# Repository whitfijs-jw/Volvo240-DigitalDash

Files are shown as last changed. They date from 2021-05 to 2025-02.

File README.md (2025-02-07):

# DigitalDash

Volvo 240 Digital Dash Project.  Designed to use existing dash connectors (circular connectors w/ 2mm pins, vehicle speed sensor (VSS) connector, and various spade connectors) to
minimize extra wiring effort and installation of superfluous sensors.

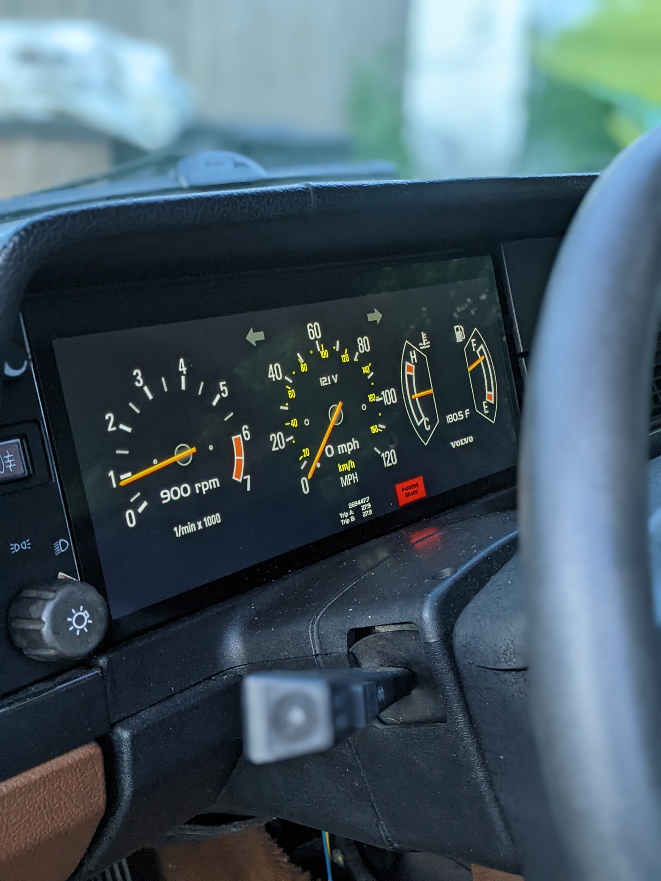
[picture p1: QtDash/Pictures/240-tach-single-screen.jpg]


## Features
### Plug and play with stock sensors and dash connectors
One of the main goals of the project was to use the existing Volvo 240 connectors. The only additional connectors and wiring needed are for sensors that weren't available on the stock main dash (oil pressure, oil temperature, vacuum/boost pressure, etc). Dash lights (low oil pressure, battery voltage, parking brake,high beams, etc) are functional as well as turn indicators. Fuel level and coolant temperature are functional.
The hardware supports the addition of common accessory sensors such as oil pressure, oil temperature, manifold absolute pressure, and ambient temperature.

### Multiple dash styles
Different Volvo dash styles can be displayed:
#### 240 w/ Tach
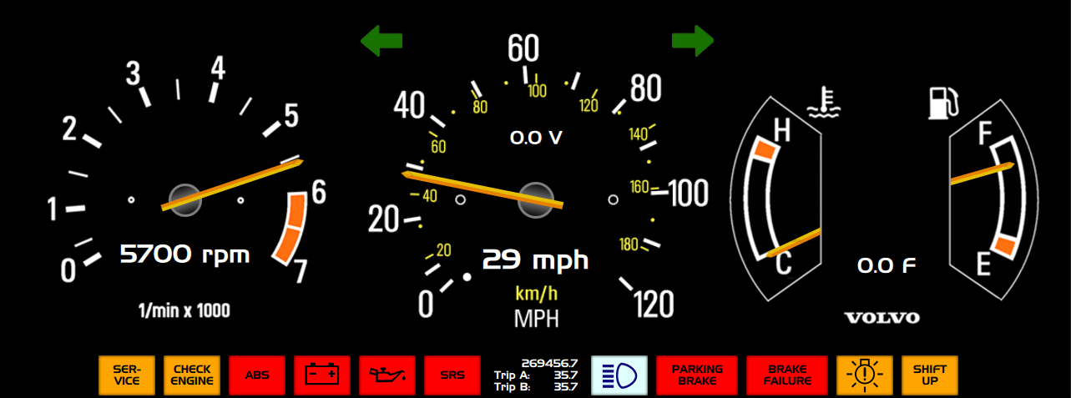
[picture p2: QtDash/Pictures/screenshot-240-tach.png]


#### 240 w/ Clock
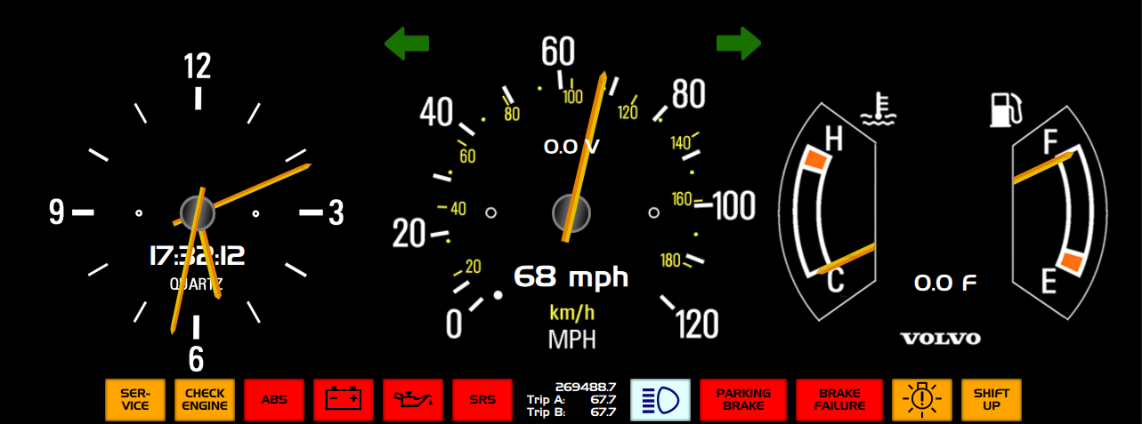
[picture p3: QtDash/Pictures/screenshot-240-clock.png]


#### R-Sport Style
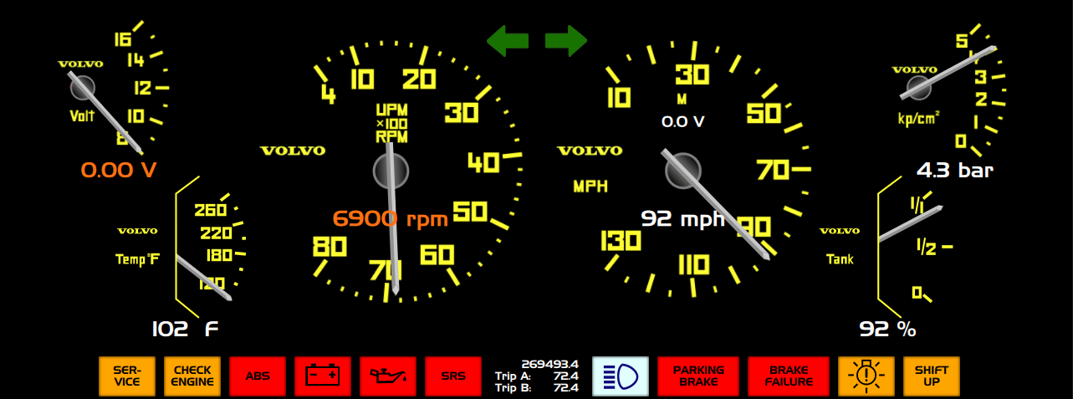
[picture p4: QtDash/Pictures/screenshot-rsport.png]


#### P1800 Style
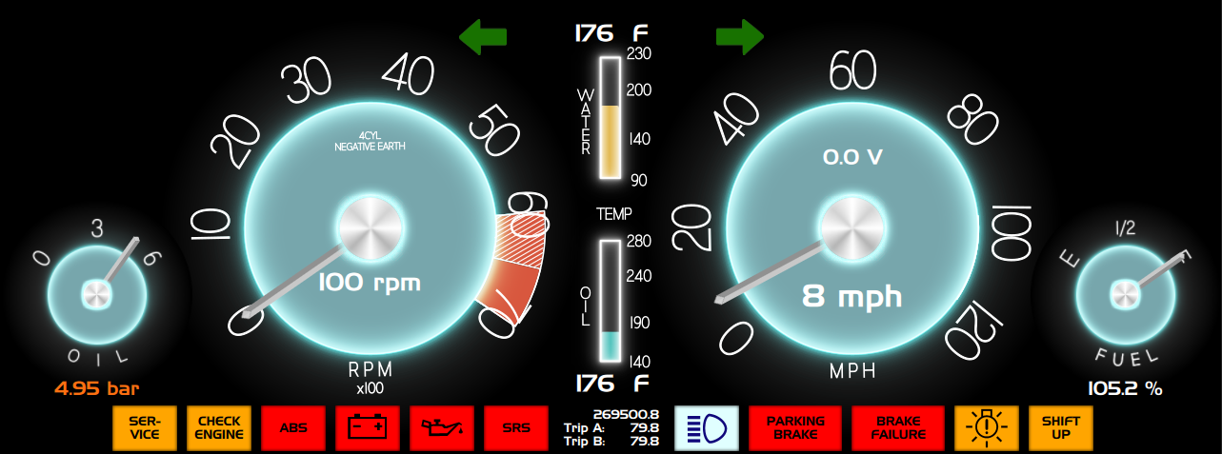
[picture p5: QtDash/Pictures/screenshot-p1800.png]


#### 850R
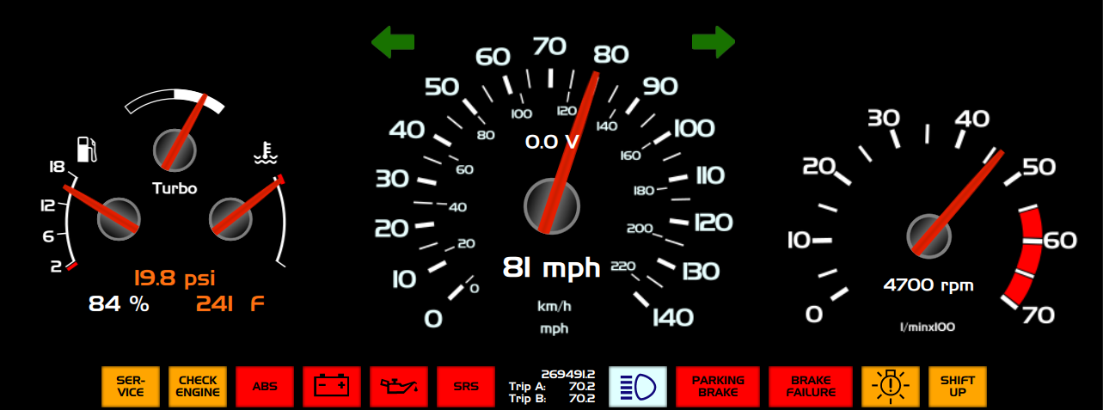
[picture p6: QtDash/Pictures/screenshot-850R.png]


#### 740/940 Style
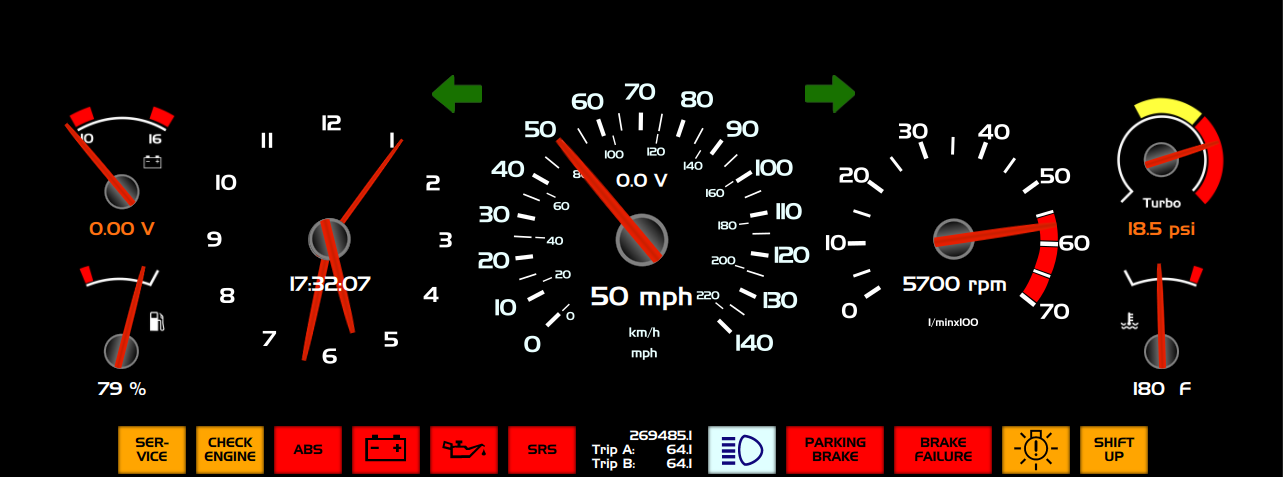
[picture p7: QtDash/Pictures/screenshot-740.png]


#### 544/140 Linear Style
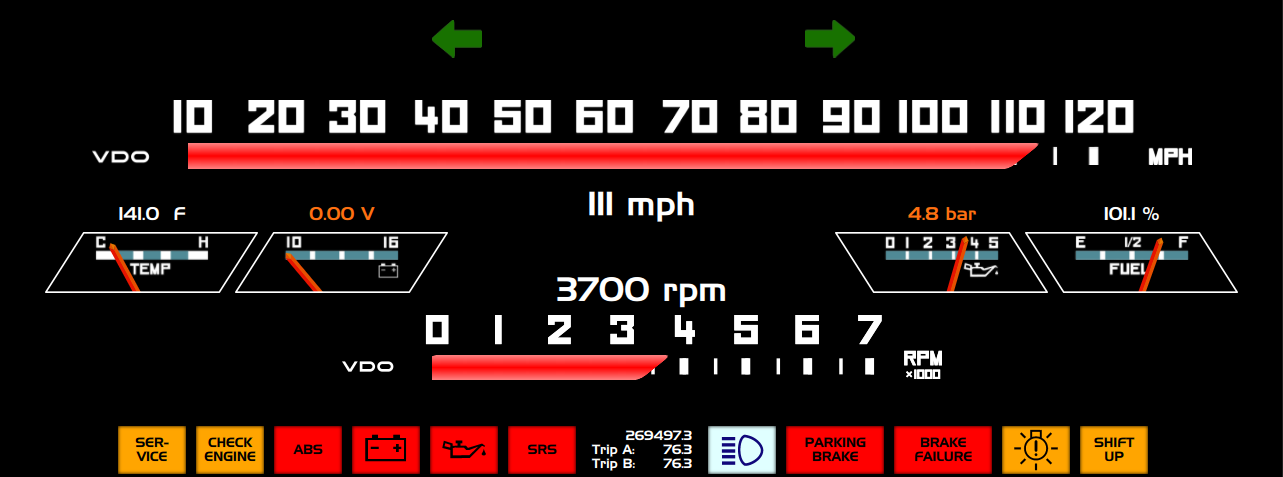
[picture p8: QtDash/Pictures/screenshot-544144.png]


#### Early 240 Style
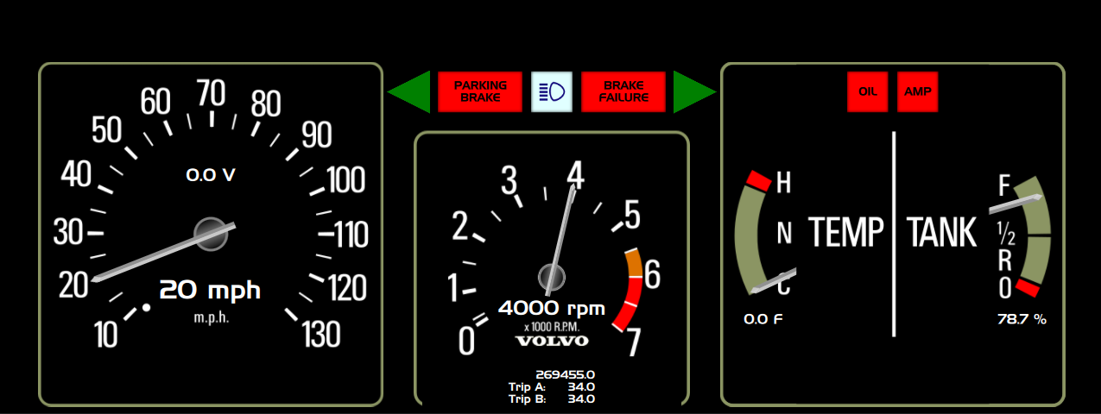
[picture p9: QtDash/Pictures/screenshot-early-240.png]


#### 140 Rallye Style
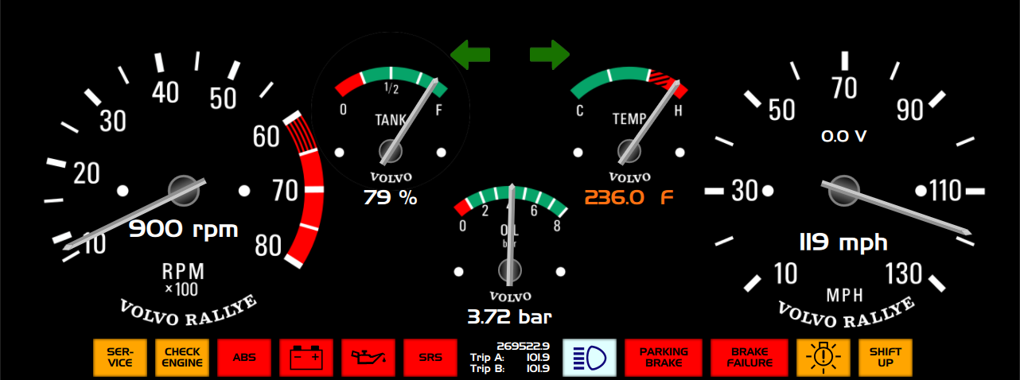
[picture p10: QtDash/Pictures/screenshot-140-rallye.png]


#### 240 Style Custom Layouts
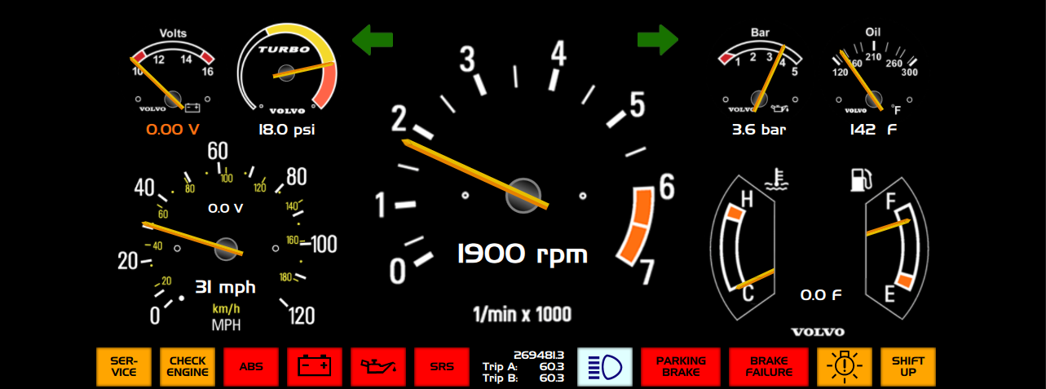
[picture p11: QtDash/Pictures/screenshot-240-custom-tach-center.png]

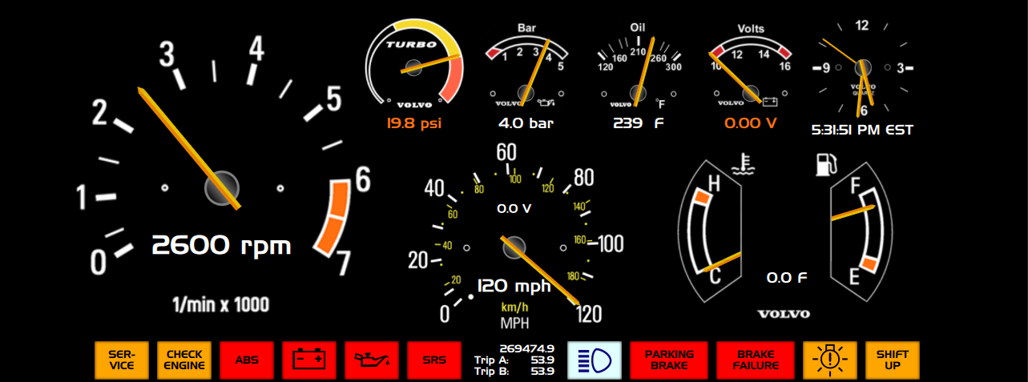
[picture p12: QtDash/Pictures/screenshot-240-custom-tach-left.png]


### Accessory Gauges
The raspberry pi 4 supports 2 HDMI outputs so a second screen can be added where normal 52mm accessory gauges would have been placed:

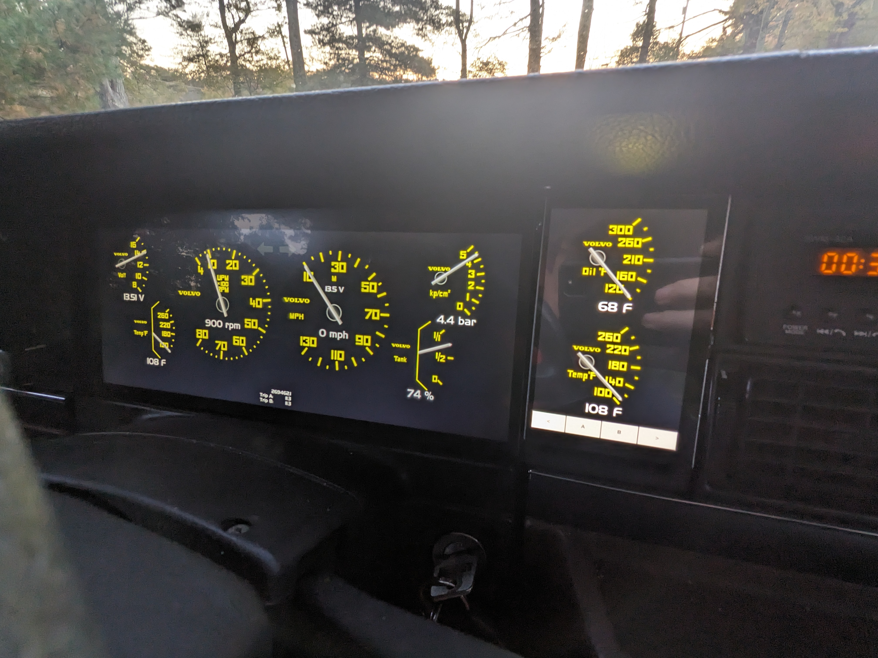
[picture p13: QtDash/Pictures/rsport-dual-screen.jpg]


Touch screen controls on this screen can be used to changed between dash layouts and also to reset trip odometers.  The style of the accessory gauges reflects the style of the main dash layout.

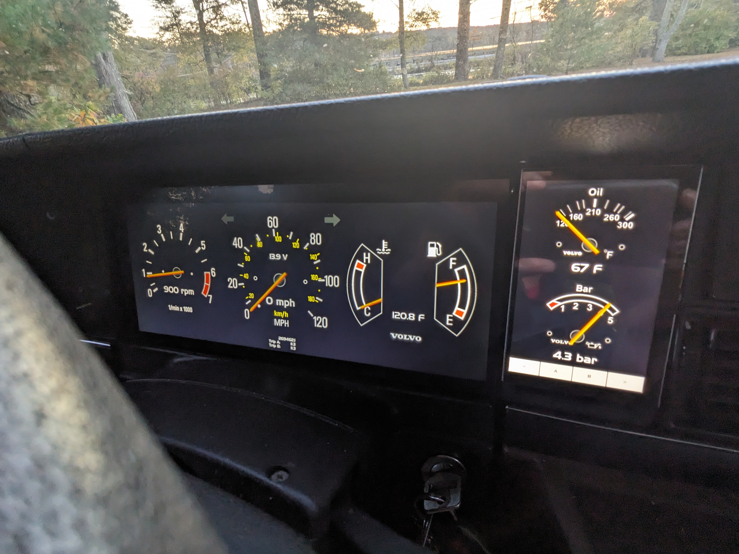
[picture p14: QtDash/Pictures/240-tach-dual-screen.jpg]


## Project Structure:
### /QtDash

This directory contains the hardware and software components that makeup the dash. There are also various visual/graphical assets that are used in the dash app.

#### /QtDash/VolvoDigitalDashModels

This directory contains the Qt app and related unit tests.  It is advised to use [QtCreator](https://www.qt.io/product/development-tools) to edit and compile the app. Using QtCreator to `QtDash/VolvoDigitalDashModels/subdirs.pro` will load both the app and the unit tests. The app is written using C/C++ for interfacing with the various sensors and QML for the UI.

#### /QtDash/Hardware

This directory contains the hardware that has been designed for this project.  Most of the PCBs have been designed using Eagle 7.7 as this is what I am most familiar with. The future of Eagle is questionable as an open source/free tool, so Kicad 6 will be used more and more as I become more familiar with it.

##### /QtDash/Hardware/DashHat

This directory contains the schematics and board files for the PCB that directly interfaces with the Raspberry Pi 40 pin header.  The board is split up into a low voltage (3.3/5V) that is powered from the Pi header and a high voltage (car battery voltage 8-16V) that is powered from the 240 ignition switch via the VSS connector.  The high voltage side is optically isolated from the low voltage side using optoislators.

##### /QtDash/Hardware/Cold Start Power Supply

This directory contains the schematics and board files for the cold start tolerant power supply design based around the LM3488. The input range is ~3V-24V and the output is ~5V rated at 3A.  During bench testing the input power needs to be above 5V when first powering up, and then could drop to ~3V while still continuously powering the Pi. This is a little overkill as the battery voltage during cranking only momentarily drops to 3V-4V before recovering very quickly to >10V.

##### /QtDash/Hardware/Screen Mounting

This directory contains the `.stl` files for mounting the HSD123KPW2-D10 12.3" TFT LCD using the stock 240 dash mounting holes.  These mounts will put the screen flush with the surrounding dash. The mounts and all other 3D modeling/CAD has been done using [Onshape](https://cad.onshape.com/documents/a41976d465f773bfdcbe5a50/w/2aee2fa256d8f08e0c531410/e/f563da56c6a88e94f86205e9). Included in the public OnShape document are models of the main PCB, HSD123KPW2-D10 LCD, screen mounts, etc.

##### /QtDash/Hardware/Simulation

This directory contains SPICE simulations of various circuits used in the dash. This is more of a scratchpad than it is a serious attempt at accurate real-life simulations.

##### /QtDash/Hardware/TachAdapter

This directory contains the schematics and board files for the tach signal adapter.  This board takes the high voltage pulses (>30V on my 88 245) and converts them to a square wave that can be used by the dash software to calculate RPM. The high voltage pulses are optically isolated from the dash/pi side to prevent any unwanted noise or damage to the pi or other hardware.

##### /QtDash/Hardware/VSS Adapter

This directory contains the schematics and board files for the VSS signal adapter. This board is based on the MAX9924 VR signal conditioning IC and takes the VR signal from the stock Volvo differential cover sensor and converts it into a square wave to be used by the dash software to calculated speed.

### /buildroot

This directory contains Buildroot, a tool used to generate a custom embedded Linux system that runs on the Pi. Buildroot allows us to generate a stripped down Linux system that has just enough to get the dash running.  This is the directory where you'll need to be to start linux image builds.

Below are relevant directories for this project within the buildroot directory structure:

#### /buildroot/board/volvodash

This directory contains the rootfs overlay for the dash as well as the custom scripts and configurations used whilst building the dash linux image. 

#### /buildroot/configs

This directory contains the configuration files for various boards. The relevant files for this project are `volvodash_defconfig` and `volvodash_rpi4_defconfig`.

#### /buildroot/output/images

This directory contains the outputs of the buildroot compilation process. After buildroot is done compiling the custom linux image, compiling the specified target packages, and constructing the target rootfs and bootfs, an image that can be flashed on to an SD card is placed here.  `sdcard.img` can then be flashed on to an SD card to be used on a pi.  As a part of the compilation/building the Qt Dash app should be compiled and placed within this image.  For more detailed information see *Setting Up Buildroot* below.

## Project components:
- Raspberry Pi 3 or Raspberry Pi 4/400
- 12.3" bar TFT LCD
- Qt Quick w/ EGLFS project to display renders of gauges
- Buildroot linux to cut down on footprint and boot time
- i2c/spi adc interface for reading temp, fuel, speed, etc sensors
- i2c IO expander for warning lights
- Raspberry Pi daughter board to read various sensors.
- DC/DC power supply for screen, pi and sensor supplies, if necessary
- Cheap USB GPS for speedometer and heading (leaving the original speedo behind the dash? Not planning on implementing a validated odometer)

## Current parts (mainly driven by availability):
- HSD123KPW2-D10 12.3" TFT 1920x720 LCD Display w/ HDMI conversion board and custom mounts
- MCP3208 for ADC inputs
- MCP23017SS for dash warning lights and left/right blinkers
- ILQ1 for isolated I/O inputs (3 for 12 inputs) add one more to completely fill the MCP23017
- IL300 for 12V to 3.3V for isolated analog signals (rheostat and battery voltage)
- lM358D for driving IL300 12V isolated analog inputs
- LMV324 & TVS912D for 5V to 3.3V analog sensor inputs
- VK-162 USB GPS module -- needs to be manually configured with u-blox u-center to get 10Hz update rate.
- (optional and separate) LM3488 switching power supply to maintain 5.1V out from 3V-24V input
- (optional) MAX9924 VSS conditioning circuit
- (separate) optocoupler tach pulse input.

## Accessory Screen Parts (optional)
- Adafruit TFP401 HDMI/DVI Decoder to 40-Pin TTL Breakout - With Touch
- BuyDisplay.com 5" IPS 800x480 LCD Screen TFT w/ touch module ER-TFT050-6-5781-4859
- extended 40-pin flat cable
- USB cable for touch screen interface

## Setting up buildroot

Buildroot will build the custom linux image.  The image being build is based on the raspberry-piX 32-bit images provided from the buildroot project.  Right now there is only support for raspberry pi 3 and pi 4/400.  Things are still a bit of a mess here and depending on your flavor of Linux you might have to setup your system a little differently than others.  You can find a lot of good information here on host packages that are absolutely necessary: [Buildroot System Requirements](https://buildroot.org/downloads/manual/manual.html#requirement)

Detailed instructions for setting up a virtual machine and the build environment are found [here](SetupBuildEnv.md)

## Remote Access

1. SSH (ethernet)

After boot the pi will be configured with a static ip address of 192.168.42.2.
Assuming you're running a version of linux that has network-manager you can run some variation of the following after connecting the pi to your computer with an ethernet cable:

`nmcli con add con-name dash-target type ethernet ifname <your-ethernet-interface> ip4 192.168.42.1/24`

`nmcli con up id dash-target`

You can find your ethernet interface by running:

`ip addr show`

You're looking for something like `enp2s0` or `eth0` depending on your flavor of linux.

After setting everything up you can test the connection using:

`ping 192.168.42.2` 

on the host machine and then run:

`ssh root@192.168.42.2` 

and enter the default credentials

## Dash Configuration

After linux is done booting and loading kernel modules, the init system will automatically start the Qt app stored in the /opt directory.  When the app is initializing it will load two configuration files from the /opt directory:

- config.ini
- config_gauges.ini
- config_odo.ini
- config_can.ini

These files are parsed using QSettings ([more info here](https://doc.qt.io/qt-5/qsettings.html)).

### Sensor input configuration (config.ini)

The sensor configuration file contains the configuration for the analog sensor inputs, dash light inputs, user inputs, tach inputs, vss inputs, the isolated 12V inputs, and backlight PWM control.

#### Sensor channels

Under the **[sensor_channel]** section the following inputs can be configured:

| Parameter | Description |
|---|---|
| *coolant_temp* | Stock Volvo coolant temperature sensor/sender. |
| *fuel_level* | Stock Volvo Fuel Level sender |
| *oil_pressure* | Oil Pressure sender |
| *oil_temp* | Oil temperature sender |
| *map_sensor* | MAP sensor sensor (GM 0-5V) |
| *ambient_temp* | Ambient Temperature sender (any NTC sensor can be used) |
| *dimmer_voltage* | Dimmer Rheostat output voltage |
| *fuse8_12v* | Volvo Fuse 8 to measure battery voltage |
| *reference* | A channel configured to measure the unregulated pi 5V supply to decrease measurment error.  If this is not used it is assumed that the supply is exactly 5V. You can alternatively measure your 5V power rail and provide that in the configurations below.|
| *v_supply* | Optional value to set the exact value of the 5V supply.  If left empty exactly 5.0V will be used |

The default configuration is as follows:
```
[sensor_channels]
coolant_temp=0
fuel_level=1
oil_pressure=2
oil_temp=3
map_sensor=5
ambient_temp=4
dimmer_voltage=6
fuse8_12v=7
reference=-1
v_supply=5.1
```

#### Dash Light Inputs

Under the **[dash_lights]** section the following inputs can be configured:

| Parameter | Description |
|---|---|
| *oil_pressure_sw* | Stock oil pressure switch |
| *od_lamp* | Overdrive lamp |
| *high_beam* | High beam indication |
| *brake_failure* | brake failure indication |
| *bulb_failure* | bulb failure indication |
| *charging* | Alternator D+/Battery charge failure indication |
| *blinker_left* | Left blinker indication |
| *blinker_right* | Right blinker indication |
| *od_lamp_auto* | auto trans OD lamp |
| *check_engine* | Check Engine indication |
| *parking_brake* | Parking Brake engagement indication |
| *conn_32_pin3* | Half moon connector pin 3 (ABS light in newer 240s) |

and one additional option:

- *active_low* -- Optoisolator outputs are open collector so this should be set to 1 unless changes to the hardware have been made

The default configuration is as follows:

```
[dash_lights]
active_low=1
oil_pressure_sw=0
od_lamp=1
high_beam=2
brake_failure=3
bulb_failure=7
charging=6
blinker_left=5
blinker_right=4
od_lamp_auto=8
check_engine=9
parking_brake=10
conn_32_pin3=11
```
#### User Input configuration

There are 4 user inputs in Rev C and greater hardware.  They are active low inputs on the otherwise unused pins on the MCP23017.

Under the **[user_inputs]** section the following inputs can be configured:

| Parameter | Description |
|---|---|
| *input_1* | User input 1 pin number |
| *input_2* | User input 2 pin number |
| *input_3* | User input 3 pin number |
| *input_4* | User input 4 pin number |
| *input_1_map* | User input 1 key mapping |
| *input_2_map* | User input 2 key mapping |
| *input_3_map* | User input 3 key mapping |
| *input_4_map* | User input 4 key mapping |

The default configuration is as follows:

```
[user_inputs]
input_1=12
input_2=13
input_3=14
input_4=15
input_1_map="Key_Left"
input_2_map="Key_A"
input_3_map="Key_B"
input_4_map="Key_Right"
```

Available key mappings are:
```
"Key_Left"
"Key_Right"
"Key_Up"
"Key_Down"
"Key_A"
"Key_B"
"Key_C"
"Key_D"
"Key_1"
"Key_2"
"Key_3"
"Key_4"
```

"Key_Left" and "Key_Right" are used to change dash layouts.  Other keys will be mapped to other functions in the future (resetting trip counters, for example).

#### MAP Sensor configuration

Designed for a GM style 0-5V output MAP sensor (1 bar, 2 bar, 3 bar). Under the **[map_sensor]** section the following parameters can be configured:

| Parameter | Description |
|---|---|
| *p_0v* | pressure when sensor output is 0V |
| *p_5v* | pressure when sensor output is 5V |
| *p_atm* | atmospheric pressure |
| *units* | pressure units used for above values.  "kPa", "psi" or "bar" should be used |

The default configuration is for a 3 bar GM style map sensor:

```
[map_sensor]
p_0v=3.6
p_5v=315
units="kPa"
```

#### Temperature Sensor (NTC) Configuration

An array of NTC sensor configurations. Calibration curves are calculated using the [Steinhart-Hart equation](https://en.wikipedia.org/wiki/Steinhart%E2%80%93Hart_equation). Under the **[temp_sensor]** the following parameters can be configured:

| Parameter | Description |
|---|---|
| *type* | Sensor type.  Options are "coolant", "oil", and "ambient" |
| *r_balance* | Resistance of the balance resistor. This can be calculated based on the high and low resistances expected during operation. |
| *t1_temp* 	|  Temperature at first calibration point |
| *t1_R* 		| Resistance at first calibration point |
| *t2_temp* 	| Temperature at second calibration point |
| *t2_R* 		| Resistance at second calibration point |
| *t3_temp* 	| Temperature at third calibration point |
| *t3_R* 		| Resistance at third valibration point |
| units | Temperature units used.  Options are "C", "K", "F" |

The default configuration is designed for an early type stock 240 coolant temp sensor, a VDO 325-905 Oil temperature sender, and a random ambient temp sensor for a BMW off Amazon.

```
[temp_sensor]
size=3
[temp_sensor/1]
type="coolant"
r_balance=470
t1_temp=60
t1_R=217
t2_temp=90
t2_R=87
t3_temp=100
t3_R=67
units="C"
[temp_sensor/2]
type="oil"
r_balance=150.0
t1_temp=19.5
t1_R=1325
t2_temp=100
t2_R=78.5
t3_temp=157
t3_R=40.5
units="C"
[temp_sensor/3]
type="ambient"
r_balance=6490
t1_temp=1.0
t1_R=15800
t2_temp=20
t2_R=6400
t3_temp=36
t3_R=3360
units="C"
```

#### Resistive Sensor Configuration

An array of resistive sensor configurations. Calibration values can be interpolated (not advised unless a lot of data points are available) or can be fitted with a polynomial of an arbitray order.  Usually a 2nd order polynomial is good enough.  The following parameters can be configured:

| Parameter | Description |
|---|---|
| *type* | Sensor type.  Options are "coolant", "oil", and "ambient" |
| *fit* | Type of fit. Options are "interpolate" or "polynomial, N" with N as the polynomial order.
| *r_balance* | Resistance of the balance resistor. This can be calculated based on the high and low resistances expected during operation. |
| *r* | Calibration resistance values.|
| *y* | Calibration y values |
| *units* | Units of calibration y values |
| *lag* | Lag factor (0-1).  Used to filter values with the difference equation: **y[n] = lag \* x[n] + (1 - lag) \* y[n-1]** Default value is 1.0. |
|*lag_decay*| Lag decay factor.  If set to a non-zero value the following equation will dictate the lag factor value used above: **lagStart=1-*lag*, lag[n] = lagStart \* (1 - *lag_decay*)^(n)** and saturates at the value set by *lag*. Large values will decay quickly, small values slowly.  Default value is 0.0.  |

The default configuration is designed for a VDO 360-028 Oil pressure sender and a 240-33Ohm Volvo 240 Fuel level sender.

```
[resistive_sensor]
size=2
[resistive_sensor/1]
type="oil_pressure"
fit=polynomial,2
r_balance=43.0
r=10.0,48.0,82.0,116.0,184.0
y=0.0,1.0,2.0,3.0,5.0
units="bar"
lag=1.0
[resistive_sensor/2]
type="fuel_level"
fit=polynomial,3
r_balance=91.0
r=240,196,153,125,103,87,67,45,33
y=0.0,12.5,25.0,37.5,50.0,62.5,75.0,87.5,100
units="%"
lag=0.2
```

#### Analog 12V inputs.

To measure signals that are inherently tied to battery voltage there are 2 linearized opto-isolated inputs.  The following parameters can be configured:

| Parameter | Description |
|---|---|
| *name* | Sensor name.  "voltmeter" is the only one currently used |
| *opto_r1* | Isolated side (R59 in schematic below) |
| *opto_r2* | Opto-isolator gain resistor R2 (R62 in schematic below) |
| *input_r1* | High side resistor of voltage divider for input into opto-isolator. (R71 in schematic below) |
| *input_r2* | Low side resistor of voltage divivider for input into opto-isolator. (R72 in schematic below) |
| *k3* | Opto-isolator K3 gain (defined by linearized opto-isolator used and will have to be measured) |
| *offset* | Offset to voltage calculation, the linearized opto-isolator usually has an offset that will need to be accounted for. |
| *x* | Linearized opto-isolator input voltage calibration measurements.  This is the high voltage side.  The more measurement points the better. |
| *y* | Output voltage calibration measurements.  This is the low voltage side.  Ideally if there was zero offset and a K3 gain of 1.0 these should be x / 10.  This is unlikely to be the case given the binning of the IL300 and LOC11x series. |

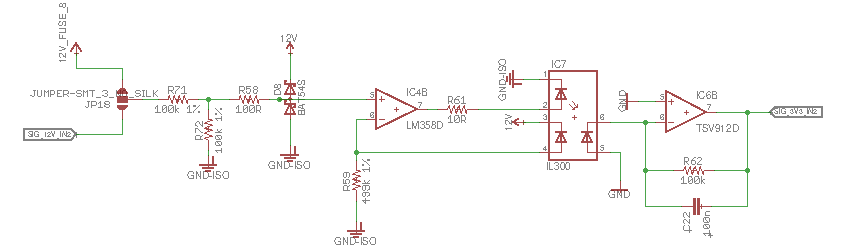
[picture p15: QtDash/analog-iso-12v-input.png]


##### How to determine K3 value (still need to test on car -- likely to change)
1. In the config.ini file, set *opto_r1*, *opto_r2*, *input_r1*, *input_r2*, and *k3* to 1.0.
2. In the config.ini file, set *offset* to 0.0.
3. Reboot the dash.
4. The output for the voltmeters will now be the real input to the ADC. Usually between 1V-2V for inputs from 8V to 16V.
5. With the car on but not running, measure the voltage at fuse 8.  This will be your first x value.  Take the output of the voltmeter (somewhere between 1V-2V).  This will be your first y value.
6. Start the car and repeat the above step.  These will be your second x and y values.
7. Enter the values determined above in the config.ini file.
8. Reset the *opto_r1*, *opto_r2*, *input_r1*, *input_r2* to their previous values.  You can leave *offset* and *k3* alone.  The software will use your calibration values to calculate the k3 gain and offset.
9. Reboot the dash and verify that the voltages with the car on and running match what you had measured before.

*Note on K3 gain calibration values:*
*Ideally, you would want way more than just 2 points to calibrate with.  If you have access to an adjustable power supply it is recommended to take 5+ measurements from 8V-16V.*

The default configuration is as follows:

```
[12v_analog]
size=2
[12v_analog/1]
name="voltmeter"
opto_r1=490000.0
opto_r2=100000.0
input_r1=100000.0
input_r2=100000.0
k3=1.1536
offset=.087985
x=8.25, 9.05, 9.87, 10.67, 11.52, 12.37, 13.30, 14.15, 14.96, 15.78, 16.78
y=1.05, 1.15, 1.25, 1.35, 1.45, 1.55, 1.65, 1.76, 1.85, 1.95, 2.05
[12v_analog/2]
name="rheostat"
opto_r1=490000.0
opto_r2=100000.0
input_r1=100000.0
input_r2=100000.0
k3=1.1536
offset=.087985
x=8.25, 9.05, 9.87, 10.67, 11.52, 12.37, 13.30, 14.15, 14.96, 15.78, 16.78
y=1.05, 1.15, 1.25, 1.35, 1.45, 1.55, 1.65, 1.76, 1.85, 1.95, 2.05
```

#### Tach Input Configuration

RPM is estimated by measuring the time difference between pulses from the negative terminal of the ignition coil.  The following parameters can be configured:

| Parameter | Description |
|---|---|
| *pulse_per_rot* | Number of tach pulses per rotation (number of cylinders / 2) |
| *max_rpm* | Maximum RPM to resolve.  This should be as low as possible. |
| *avg_num_samples* | Number of samples to average over to estimate RPM |

The default configuration is as follows:

```
[tach_input]
pulse_per_rot=2
max_rpm=9000
avg_num_samples=4
```

#### Vehicle speed sensor input

Designed to used the stock 240 diff cover VSS. The vehicle speed can be estimated using the number of pulses coming from the VSS sensor for every rotation of the rear diff. The following parameters can be configured:

| Parameter | Description |
|---|---|
| *pulse_per_rot* | Number of VSS pulses per rotation (12 for non-ABS and 48 for ABS equipped 240s) |
| *tire_diameter* | Tire diameter (can be used to calculate pulses per unit distance) |
| *diameter_units* | Tire diameter units: "inch", "centimeter", "millimeter", "foot", etc  |
| *pulse_per_unit_distance* | Number of pulses per units distance. |
| *distance_units* | Distance units for pulses per unit distance:  "mile", "kilometer  |
| *max_speed* | max speed (distance_units / hour).  Keep as low as possible to avoid picking up noise as VSS pulses |

The default configuration is as follows:

```
[vss_input]
pulse_per_rot=12
tire_diameter=24.9
diameter_units="inch"
pulse_per_unit_distance=9720
distance_units="mile"
max_speed="185"
```

#### Backlight control configuration (optional and only somewhat functional)

The stock 240 dimming circuit (Pin 10 on the circular Volvo connector 31) can be used to dim the backlight of the LCD by injecting a PWM signal into the LCD control board. Back light control with the dimmer knob only works when the headlights or running lights are engaged.  Otherwise, the dimmer rheostat does not receive voltage.

The following parameters can be configured:

| Parameter | Description |
|---|---|
| *max_duty_cycle* | Maximimum duty cycle of backlight PWM signal (min_duty_cycle-1.0) |
| *min_duty_cycle* | Minimum duty cycle of backlight PWM signal (0-max_duty_cycle) |
| *lights_off_duty_cycle* | Default duty cycle to use when the headlights or running lights are off |
| *lights_on_duty_cycle* | Default duty cycle to use when headlights or running lights are on|
| *min_dimmer_ratio* | rheostat voltage as a percentage of battery voltage at dimmest setting |
| *max_dimmer_ratio* | rheostat voltage as a percentage of battery voltage at brightest setting |
| *use_dimmer* | flag to use/don't use dimmer |
| *active_low* | PWM signal active low flag |

The default configuration is as follows:

```
[backlight]
max_duty_cycle=1.0
min_duty_cycle=0.05
lights_off_duty_cycle=1.0
lights_on_duty_cycle=0.5
min_dimmer_ratio=0.82
max_dimmer_ratio=0.93
use_dimmer=0
active_low=1
```

### Gauge Configs (config_gauges.ini)
There are a few options in setting up the gauge units and high/low warning indications.  There settings are found within the file config_gauges.ini.  The app will parse this file and will set the various gauge units, min/max values, and high/low warnings.

#### Gauge Config Parameters
| Parameter | Description | Default Value |
|---|---|
|*units*| Gauge Display Units ||
|*low_alarm*| Value below which gauge will indicate a warning ||
|*high_alarm*| Value above which gauge will indicate a warning ||
|*alt_units_enable*| Enable alternate units|*false*|
|*alt_units*|Alternate units|\"\"|
|*alt_units_thres*|Threshold value to switch units|*0.0*|
|*alt_units_above*|If true, use alternate units above threshold.  Otherwise the alternate units are used below the threshold|*false*|

##### Example:
This example sets the units for coolant temperature gauges, in all screens, to celsius.  The gauge will indicate an alarm when the temperature exceeds 100C.
```
[coolant_temp]
units="C"
low_alarm=0.0
high_alarm=100.0
```

#### Available Gauge Units
Below are the available units for each gauge type

| Gauge Type | Available Units |
|---|---|
|**[boost]**|```"bar"``` ```"psi"``` ```"inHg"```|
|**[coolant_temp]**|```"C"``` ```"F"```|
|**[fuel_level]**|```"%"```|
|**[oil_pressure]**|```"bar"``` ```"psi"```|
|**[oil_temperature]**|```"C"``` ```"F"```|
|**[voltmeter]**|```"V"```|
|**[speedo]**|```"mph"``` ```"kph"``` ```"km/h"```|
|**[tacho]**|*none*|

#### Default Gauge Ranges

These are the default gauge ranges for the given units.  These can be assigned to different values in *config_gauges.ini*, but the gauges themselves are prerendered so its not gauranteed that the needle position will align with the displayed value

| Gauge Type | Unit | Min Value | Max Value |
|---|---|---|---|
|**[boost]**| ```"psi"``` | -20 | 30 |
|**[boost]**| ```"bar"```| -1.0| 1.5 |
|**[coolant_temp]**| ```"C"``` | 50 | 120 |
|**[coolant_temp]**| ```"F"```| 120| 250 |
|**[fuel_level]**| ```"%"``` | 0 | 100 |
|**[oil_pressure]**| ```"bar"```| 0| 5 |
|**[oil_pressure]**| ```"psi"``` | 0 | 80 |
|**[oil_temperature]**| ```"C"```| 50| 150 |
|**[oil_temperature]**| ```"F"``` | 120 | 300 |
|**[voltmeter]**| ```"V"```| 10| 16 |
|**[speedo]**| ```"kph"``` ```"km/h"``` | 0 | 220 |
|**[speedo]**| ```"mph"```| 0| 120 |

### Default Values

```
[boost]
units="psi"
low_alarm=-20.0
high_alarm=20.0
[coolant_temp]
units="F"
low_alarm=0.0
high_alarm=200.0
[fuel_level]
units="%"
low_alarm=10.0
high_alarm=200.0
[oil_pressure]
units="bar"
low_alarm=1.0
high_alarm=4.5
[oil_temperature]
units="F"
low_alarm=0.0
high_alarm=220.0
[voltmeter]
units="V"
low_alarm=12.0
high_alarm=15.0
[speedo]
units="mph"
top_value_source="voltmeter"
top_value_units="V"
[tacho]
max_rpm=7000
redline=6000
```

### CAN config (config_can.ini)
Rev C hardware added components to interface with CAN outputs from an aftermarket ECU.  The MCP2515 driver and can0 network interface are loaded when the dash boots and the Dash Qt app attempts to load CAN frame configuration from the *config_can.ini* file.  To date this has only been tested with a Microsquirt on a bench with simulated inputs. If the CAN interface is enabled in the CAN config file, the dash will preferentially use the frame data for a specific gauge over a hardware sensor.

#### Enable/Disable
Under the **[start]** heading in the CAN config file, there is a single option:

| Parameter | Description |
|---|---|
| *use* | true/false to enable/disable the use of incoming CAN data |

#### CAN Frame data
Under the **[can_frame]** heading will come the CAN frame data settings. This is setup based upon information found [here](http://www.msextra.com/doc/pdf/Megasquirt_CAN_Broadcast.pdf).

| Parameter | Description |
|---|---|
| *frame_id* | CAN Frame ID where data is present |
| *offset* | Offset within frame where the data is present |
| *data_size* | Data size in bytes |
| *signed* | true if data is signed |
| *name* | Name of data (map, rpm, tps, etc) -- default values come from the simplified CAN broadcast data from Megasquirt |
| *units* | Units of data |
| *multiply* | Factor to multiply raw value by |
| *divide* | Factor to divide raw value by |
| *add* | Value to add to raw value |
| *gauge* | Gauge to route data to. |

Order of operations is **(raw_data * multiply_factor / divide_factor) + add_value**.  Is this right? No idea.

Example configuration:
```
[start]
use=false
[can_frame]
size=7
[can_frame/1]
frame_id=1512
offset=0
data_size=2
signed=true
name="map"
units="kPa"
multiply=1
divide=10
add=0
gauge="boost"
[can_frame/2]
frame_id=1512
offset=2
data_size=2
signed=false
name="rpm"
units="rpm"
multiply=1
divide=1
add=0
gauge="tacho"
[can_frame/3]
frame_id=1512
offset=4
data_size=2
signed=true
name="clt"
units="F"
multiply=1
divide=10
add=0
gauge="coolant_temp"
[can_frame/4]
frame_id=1512
offset=6
data_size=2
signed=true
name="tps"
units="%"
multiply=1
divide=10
add=0
gauge="none"
[can_frame/5]
frame_id=1513
offset=4
data_size=2
signed=true
name="mat"
units="F"
multiply=1
divide=10
add=0
gauge="none"
[can_frame/6]
frame_id=1515
offset=0
data_size=2
signed=true
name="batt"
units="V"
multiply=1
divide=10
add=0
gauge="voltmeter"
[can_frame/7]
frame_id=1516
offset=0
data_size=2
signed=true
name="vss1"
units="msec^-1"
multiply=1
divide=10
add=0
gauge="none"
```

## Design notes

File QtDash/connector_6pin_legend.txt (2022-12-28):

oil pressure -> yellow
oil temp -> orange
ambient -> N/C
map_sensor -> blue

6 pin DT04-6P
1 -> +5V (red)
2 -> MAP Sensor output (blue)
3 -> GND (black)
4 -> N/C (ambient temp sensor)
5 -> oil temp (orange)
6 -> oil pressure (yellow)

Molex Nano-fit 8-pin
1 -> oil temp (orange)
2 -> oil pressure (yellow)
3 -> sensor 2 input (used by stock fuel level sensor)
4 -> sensor 1 input (used by stock coolant temp sensor)
5 -> N/C (ambient temp sensor)
6 -> MAP (blue)
7 -> +5V (red)
8 -> GND (black)

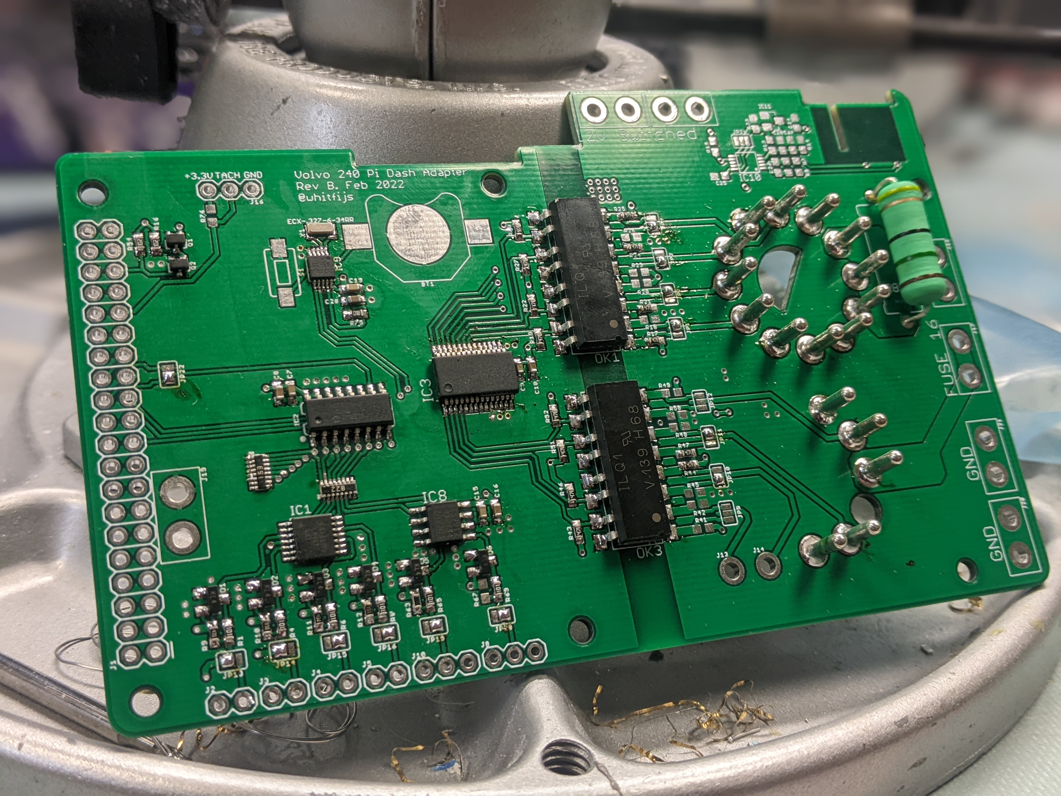
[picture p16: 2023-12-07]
QtDash/Pictures/revb_hardware.jpg

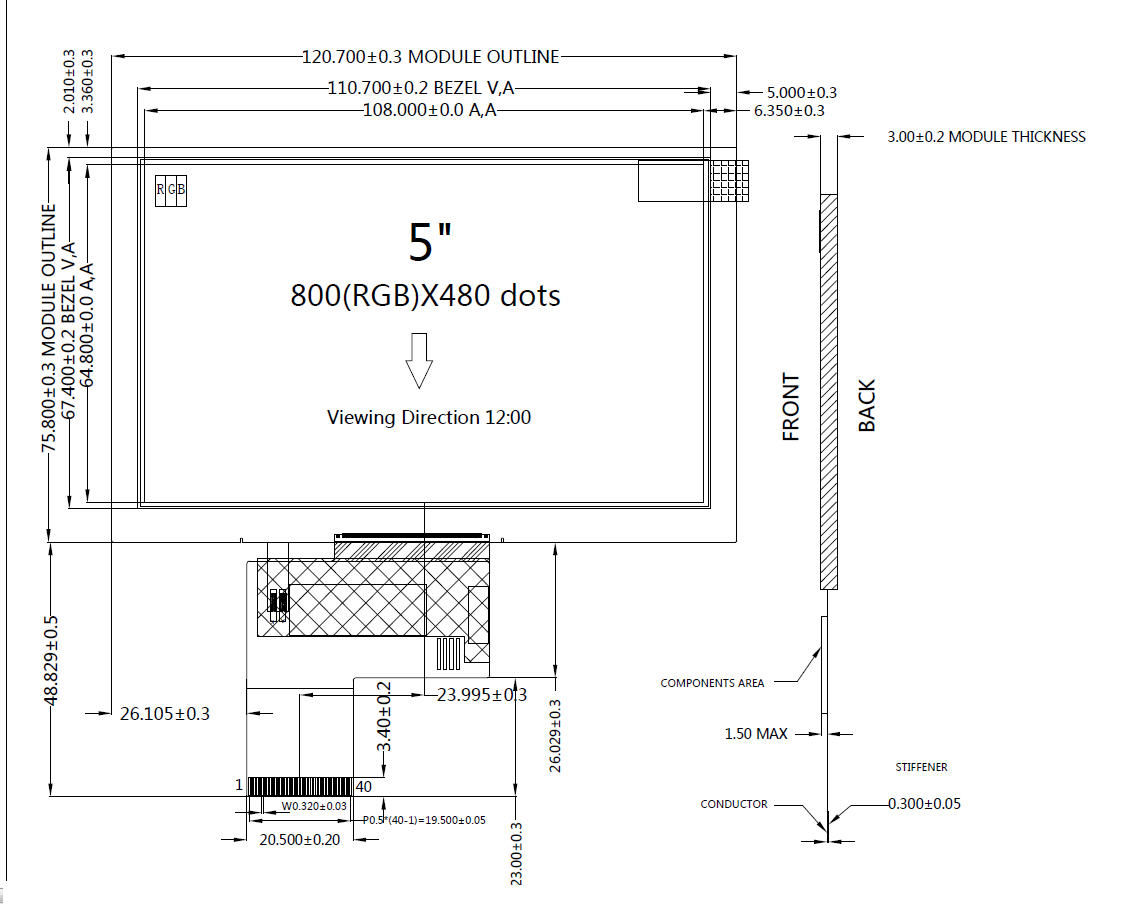
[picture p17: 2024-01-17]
QtDash/Hardware/Datasheets/Accessory Screen/er-tft050-3_outline_drawing_5.jpg

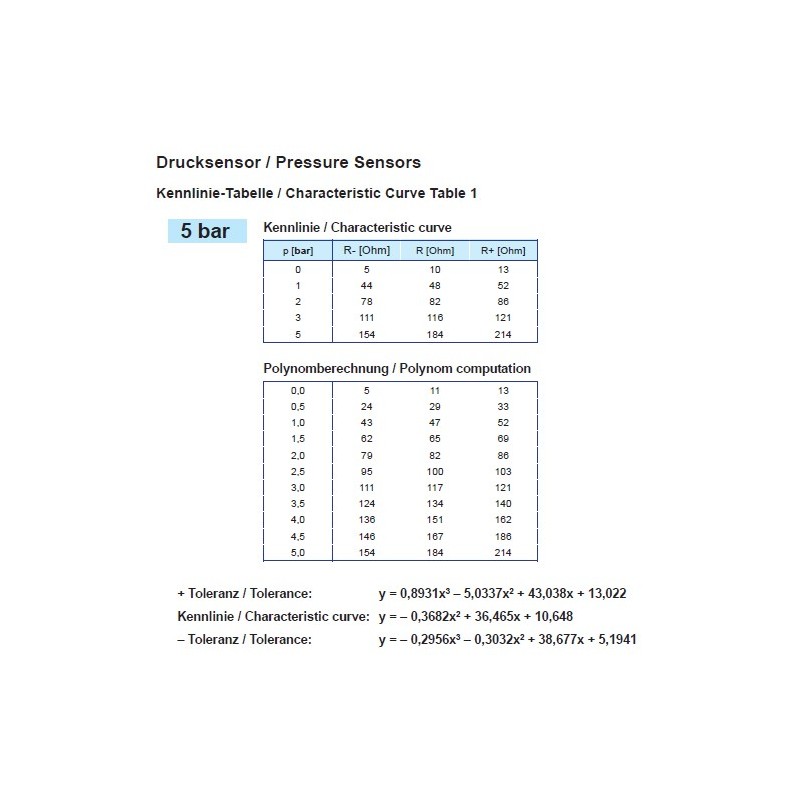
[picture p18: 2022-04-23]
QtDash/Hardware/Datasheets/Sensor Info/vdo-pressure-sender-0-5-bar-1-8-27-nptf.jpg

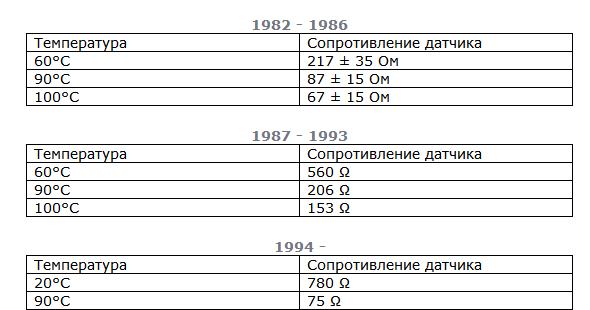
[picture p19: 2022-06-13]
QtDash/Hardware/Datasheets/Sensor Info/sensor.JPG

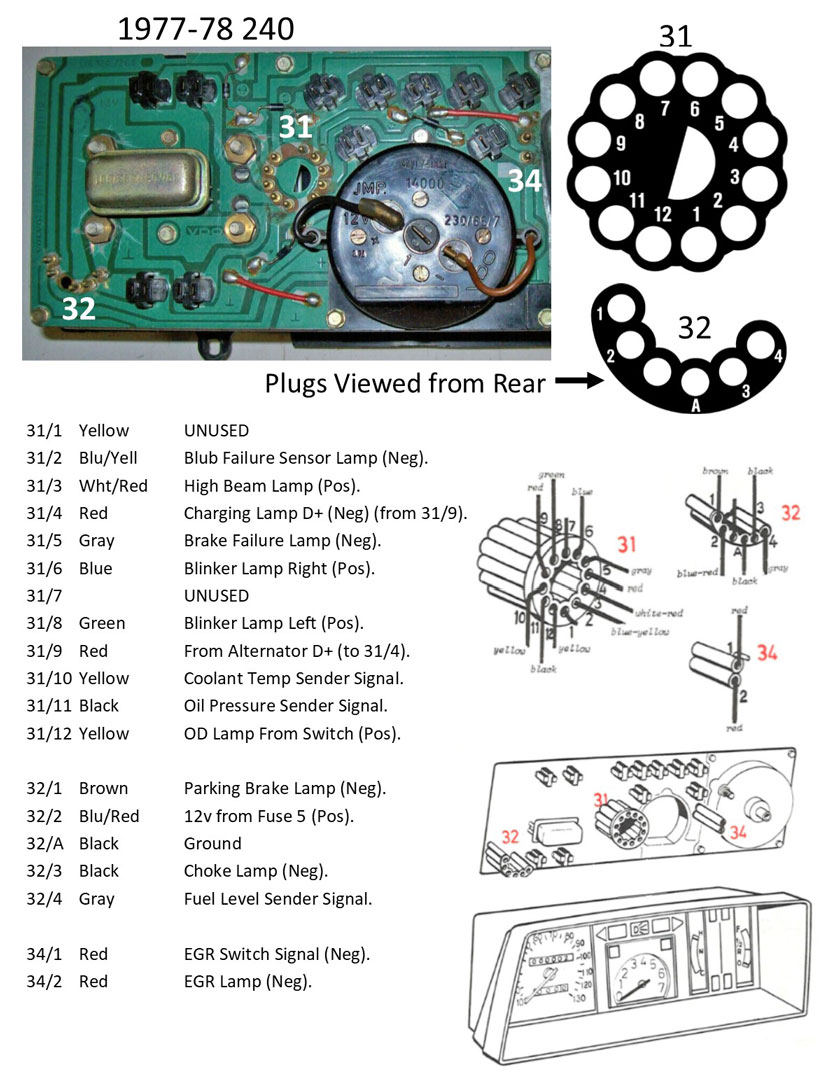
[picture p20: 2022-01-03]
QtDash/Hardware/Dash Pinouts/240instruments1977-78-01med.jpg

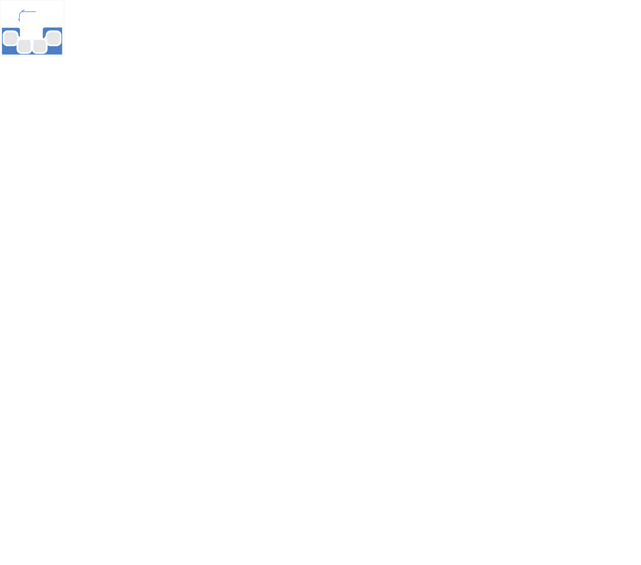
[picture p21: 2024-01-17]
QtDash/Hardware/TouchPanel/touch_panel/bottom_layer.svg/touch_panel-B_Cu.png

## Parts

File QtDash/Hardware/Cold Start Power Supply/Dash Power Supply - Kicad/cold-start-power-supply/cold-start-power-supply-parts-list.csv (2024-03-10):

Item | Qty | Reference(s) | Value | LibPart | Footprint | Datasheet | PN
1 | 3 | C1, C2, C3 | 3.3u | Device:C_Polarized | Capacitor_SMD:CP_Elec_5x5.3 | ~ | EEE-FK1K3R3R
2 | 1 | C4 | 100n | Device:C | Capacitor_SMD:C_0603_1608Metric | ~ | CL10B104MB8NNNC
3 | 2 | C5, C7 | 1n | Device:C | Capacitor_SMD:C_0603_1608Metric | ~ | CL10B102KB8NNWC
4 | 1 | C6 | .68u | Device:C | Capacitor_SMD:C_0603_1608Metric | ~ | CL10B684KO8NFNC
5 | 1 | C8 | 4.7u | Device:C | Capacitor_SMD:C_0603_1608Metric | ~ | CL10A475KL8NRNC
6 | 2 | C9, C10 | 100u | Device:C | Capacitor_SMD:C_1210_3225Metric | ~ | CL32A107MPVNNNE
7 | 1 | C11 | 4.7u | Device:C | Capacitor_SMD:C_1210_3225Metric | ~ | CL10A475KL8NRNC
8 | 1 | D1 | D_Schottky | Device:D_Schottky | Package_TO_SOT_SMD:TO-263-2_TabPin1 | ~ | STPS8H100G-TR
9 | 4 | H1, H2, H3, H4 | MountingHole | Mechanical:MountingHole | MountingHole:MountingHole_2.2mm_M2_Pad_Via | ~
10 | 1 | IC1 | LM3488 | volvodash:LM3488 | Package_SO:MSOP-8_3x3mm_P0.65mm |  | LM3488QMMX/NOPB
11 | 2 | J1, J2 | Conn_01x02 | Connector_Generic:Conn_01x02 | Connector_Wire:SolderWire-1sqmm_1x02_P5.4mm_D1.4mm_OD2.7mm | ~
12 | 1 | L1 | 4.7u | Device:L_Coupled_1324 | volvodash:DRQ127 | ~ | DRQ127-4R7-R
13 | 1 | Q1 | BSC026N08NS5 | Transistor_FET:BSC026N08NS5 | Package_TO_SOT_SMD:TDSON-8-1 | http://www.infineon.com/dgdl/Infineon-BSC026N08NS5-DS-v02_01-EN.pdf?fileId=5546d4624ad04ef9014ae2eace7629e0 | DMTH6002LPS-13
14 | 1 | R1 | 20R | Device:R | Resistor_SMD:R_0603_1608Metric | ~ | RC0603JR-0720RL
15 | 1 | R2 | 270 1% | Device:R | Resistor_SMD:R_0603_1608Metric | ~ | RC0603FR-07270RL
16 | 1 | R3 | 75k | Device:R | Resistor_SMD:R_0603_1608Metric | ~ | RC0603JR-0775KL
17 | 1 | R4 | 0 | Device:R | Resistor_SMD:R_0603_1608Metric | ~
18 | 1 | R5 | 100R | Device:R | Resistor_SMD:R_0603_1608Metric | ~ | RC0603JR-07100RL
19 | 1 | R6 | 6mOhm | Device:R | volvodash:R3216 | ~ | PRL1632-R006-F-T1
20 | 1 | R7 | 30.9k 1% | Device:R | Resistor_SMD:R_1206_3216Metric | ~ | RC1206FR-0730K9L
21 | 1 | R8 | 10k 1% | Device:R | Resistor_SMD:R_0603_1608Metric | ~ | RC0603FR-1010KL

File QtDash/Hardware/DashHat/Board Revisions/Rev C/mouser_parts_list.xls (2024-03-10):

VOLVODIGITALDASH
Mouser # | Mfr. # | Manufacturer | Customer # | Description | RoHS | Lifecycle | Order Qty. | Price (USD) | Ext.: (USD)
538-105300-2100-CT | 105300-2100 (Cut Strip) | Molex |  | Headers & Wire Housings NF FEM TERM 20-22AWG CUT STRIP OF 100 | RoHS Compliant |  | 100 | $0.131 | $13.10
534-3000 | 3000 | Keystone Electronics |  | Coin Cell Battery Holders SM COIN CELL BH 12mm | RoHS Compliant |  | 1 | $0.388 | $0.388
603-RC0603JR-07100RL | RC0603JR-07100RL | YAGEO |  | Thick Film Resistors - SMD 100 Ohms 100 mW 0603 5% | RoHS Compliant By Exemption |  | 8 | $0.10 | $0.80
603-RC0603FR-10100KL | RC0603FR-10100KL | YAGEO |  | Thick Film Resistors - SMD 100 kOhms 100-200mW 0603 1% | RoHS Compliant By Exemption |  | 6 | $0.10 | $0.60
187-CL10B104MB8NNNC | CL10B104MB8NNNC | Samsung Electro-Mechanics |  | Multilayer Ceramic Capacitors MLCC - SMD/SMT 100nF+/-20% 50V X7R 0603 | RoHS Compliant |  | 20 | $0.012 | $0.24
603-RC0603FR-1010KL | RC0603FR-1010KL | YAGEO |  | Thick Film Resistors - SMD 10 kOhms 100-200mW 0603 1% | RoHS Compliant By Exemption |  | 2 | $0.10 | $0.20
187-CL10B103KB8NNNC | CL10B103KB8NNNC | Samsung Electro-Mechanics |  | Multilayer Ceramic Capacitors MLCC - SMD/SMT SAMSUNG | RoHS Compliant |  | 1 | $0.10 | $0.10
187-CL10B106MQ8NRNC | CL10B106MQ8NRNC | Samsung Electro-Mechanics |  | Multilayer Ceramic Capacitors MLCC - SMD/SMT 10uF+/-20% 6.3V X7R 0603 | RoHS Compliant |  | 1 | $0.69 | $0.69
603-RC0603FR-07120RL | RC0603FR-07120RL | YAGEO |  | Thick Film Resistors - SMD 120 Ohms 100mW 0603 1% | RoHS Compliant By Exemption |  | 1 | $0.10 | $0.10
520-120-20-3XT | ECS-120-20-3X-TR | ECS |  | Crystals 12MHz 20pF 50ppm -10C +70C | RoHS Compliant |  | 1 | $0.31 | $0.31
603-YC248-JR-0715KL | YC248-JR-0715KL | YAGEO |  | Resistor Networks & Arrays 15K 5% CONVEX SQUARE 8X0402 | RoHS Compliant By Exemption |  | 1 | $0.24 | $0.24
603-RC0603JR-071KL | RC0603JR-071KL | YAGEO |  | Thick Film Resistors - SMD 1 kOhms 100 mW 0603 5% | RoHS Compliant By Exemption |  | 27 | $0.01 | $0.27
187-CL10A105KA8NNNC | CL10A105KA8NNNC | Samsung Electro-Mechanics |  | Multilayer Ceramic Capacitors MLCC - SMD/SMT 1uF+/-10% 25V X5R 16 0603 | RoHS Compliant |  | 8 | $0.10 | $0.80
603-RC0603JR-0720KL | RC0603JR-0720KL | YAGEO |  | Thick Film Resistors - SMD 20 kOhms 100 mW 0603 5% | RoHS Compliant By Exemption |  | 5 | $0.10 | $0.50
603-RC0603FR-0720KL | RC0603FR-0720KL | YAGEO |  | Thick Film Resistors - SMD 20 kOhms 100mW 0603 1% | RoHS Compliant By Exemption |  | 2 | $0.10 | $0.20
187-CL10C220JB81PNC | CL10C220JB81PNC | Samsung Electro-Mechanics |  | Multilayer Ceramic Capacitors MLCC - SMD/SMT 22pF+/-5% 50V C0G 16 0603 | RoHS Compliant |  | 2 | $0.10 | $0.20
603-RC0603FR-07270RL | RC0603FR-07270RL | YAGEO |  | Thick Film Resistors - SMD 270 Ohms 100mW 0603 1% | RoHS Compliant By Exemption |  | 2 | $0.10 | $0.20
512-2N7002 | 2N7002 | onsemi |  | MOSFET N-CHANNEL 60V 115mA | RoHS Compliant |  | 2 | $0.45 | $0.90
603-RC0603JR-07470RL | RC0603JR-07470RL | YAGEO |  | Thick Film Resistors - SMD 470 Ohms 100 mW 0603 5% | RoHS Compliant By Exemption |  | 10 | $0.011 | $0.11
603-YC248-JR-078K2L | YC248-JR-078K2L | YAGEO |  | Resistor Networks & Arrays 8.2K 5% CONVEX LONG SIDE TERM | RoHS Compliant By Exemption |  | 1 | $0.28 | $0.28
637-BAT54S | BAT54S | Diotec Semiconductor |  | Schottky Diodes & Rectifiers Schottky, SOT-23, 30V, 0.2A | RoHS Compliant |  | 8 | $0.12 | $0.96
700-DS1374U-33T&R | DS1374U-33+T&R | Analog Devices Inc. |  | Real Time Clock I C, 32-Bit Binary Counter Watchdog RTC with Trickle Charger and Reset Input/Output | RoHS Compliant |  | 1 | $4.81 | $4.81
520-.327-6-34RRT | ECS-.327-6-34RR-TR | ECS |  | Crystals 32.786kHz 6pF 20ppm -40C +85C | RoHS Compliant |  | 1 | $1.14 | $1.14
782-IL300-DEFG-X007T | IL300-DEFG-X007T | Vishay |  | High Linearity Optocouplers High Gain Wide Bandwidth Linear | RoHS Compliant |  | 2 | $4.74 | $9.48
782-ILQ1-X009 | ILQ1-X009 | Vishay |  | Transistor Output Optocouplers Phototransistor Out Quad CTR > 20% | RoHS Compliant |  | 2 | $4.43 | $8.86
595-LM358DR | LM358DR | Texas Instruments |  | Operational Amplifiers - Op Amps Dual Op Amp | RoHS Compliant |  | 1 | $0.45 | $0.45
926-LMV614MTX/NOPB | LMV614MTX/NOPB | Texas Instruments |  | Operational Amplifiers - Op Amps Lo Vltg,Low Pwr,RRIO Gen Purp amp | RoHS Compliant |  | 1 | $1.04 | $1.04
700-MAX9924UAUB/V+T | MAX9924UAUB/V+T | Analog Devices Inc. |  | Sensor Interface Var-Relctnce SnsrIntrfce w/Diffl Inpt<(>&<)>Adptve PkThrshld | RoHS Compliant |  | 1 | $10.98 | $10.98
579-MCP23017-E/SS | MCP23017-E/SS | Microchip |  | Interface - I/O Expanders 16bit Input/Output Exp I2C interface | RoHS Compliant |  | 1 | $1.69 | $1.69
579-MCP2515T-E/SO | MCP2515T-E/SO | Microchip |  | CAN Interface IC W/ SPI Inter 125dC | RoHS Compliant |  | 1 | $2.97 | $2.97
579-MCP3208-BI/SL | MCP3208-BI/SL | Microchip |  | Analog to Digital Converters - ADC 12-bit SPI 8 Chl | RoHS Compliant |  | 1 | $5.76 | $5.76
771-PESD1CANVL | PESD1CANVL | Nexperia |  | ESD Suppressors / TVS Diodes PESD1CAN/SOT23/TO-236AB | RoHS Compliant | NRND | 1 | $0.42 | $0.42
652-WS5M68R0J | WS5M68R0J | Bourns |  | Wirewound Resistors - Through Hole 68R0 5W 5% RES AX | RoHS Compliant |  | 1 | $0.69 | $0.69
595-SN65HVD230D | SN65HVD230D | Texas Instruments |  | CAN Interface IC STANDBY MODE | RoHS Compliant | End of Life | 1 | $3.04 | $3.04
595-TSV912AQDRQ1 | TSV912AQDRQ1 | Texas Instruments |  | Operational Amplifiers - Op Amps Automotive-grade, dual, 5.5-V, 8-MHz, RRIO operational amplifier 8-SOIC -40 to 125 | RoHS Compliant |  | 2 | $0.97 | $1.94
621-ZXTR2105FQ-7 | ZXTR2105FQ-7 | Diodes Incorporated |  | Linear Voltage Regulators Transistor Array | RoHS Compliant |  | 1 | $0.34 | $0.34
575-1480-3-80-030 | 1480-3-00-80-00-00-03-0 | Mill-Max |  | Circuit Board Hardware - PCB Surface Mount Pin, .375" Long Slotted Base, .080" Diameter Tail | RoHS Compliant |  | 17 | $0.352 | $5.98
538-105310-2108 | 105310-2108 | Molex |  | Headers & Wire Housings NanoFit Hdr Vrt 8Ckt DR KNK Pns Ntl Tin | RoHS Compliant |  | 1 | $2.52 | $2.52
538-105314-1204 | 105314-1204 | Molex |  | Headers & Wire Housings NanoFit RA Hdr TH DR 4Ckt 0.38um Au Blk | RoHS Compliant |  | 1 | $1.35 | $1.35
538-105308-1208 | 105308-1208 | Molex |  | Headers & Wire Housings NanoFit TPA Recp Hsg Dual Row 8Ckt Blk | RoHS Compliant |  | 1 | $0.50 | $0.50
538-105308-1204 | 105308-1204 | Molex |  | Headers & Wire Housings NanoFit TPA Recp Hsg Dual Row 4Ckt Blk | RoHS Compliant |  | 1 | $0.42 | $0.42

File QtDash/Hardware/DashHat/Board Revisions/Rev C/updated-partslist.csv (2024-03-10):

Qty | Value | Device | Package | Parts | Description
1 |  | 3000 | BATTCON_12MM | BT1 | Battery - Single Cell
8 | 100R | RC0603JR-07100RL | 603 | R1, R4, R6, R8, R57, R58, R65, R69
6 | 100k 1% | RC0603FR-10100KL | 603 | R53, R59, R71, R72, R73, R74
20 | 100n | CL10B104MB8NNNC | 603 | C1, C2, C3, C4, C5, C7, C9, C11, C12, C15, C17, C18, C19, C21, C22, C23, C25, C27, C30, C31
2 | 10k 1% | RC0603FR-1010KL | 603 | R5, R7
1 | 10n | CL10B103KB8NNNC | 603 | C26
1 | 10u | CL10B106MQ8NRNC | 603 | C28
1 | 120 1% | RC0603FR-07120RL | 603 | R77
1 | 12MHz | ECS-120-20-3X-TR | ECS | X1
1 | 15k | YC248-JR-0715KL | YC248 | R3
27 | 1k | RC0603JR-071KL | 603 | R9, R10, R11, R12, R13, R14, R15, R19, R22, R27, R28, R31, R34, R39, R40, R43, R46, R51, R52, R63, R64, R66, R67, R68, R70, R75, R80
8 | 1u | CL10A105KA8NNNC | 603 | C6, C8, C10, C13, C14, C16, C20, C24
5 | 20k | RC0603JR-0720KL | 603 | R16, R54, R60, R76, R81
2 | 20k 1% | RC0603FR-0720KL | 603 | R56, R62
2 | 22p | CL10C220JB81PNC | 603 | C32, C33
2 | 270 1% | RC0603FR-07270RL | 603 | R55, R61
2 | 310mA/60V/1.6Ω | 2N7002 | SOT323 | Q1, Q2 | N-channel MOSFETs
10 | 470R | RC0603JR-07470RL | 603 | R17, R21, R24, R25, R29, R32, R36, R38, R44, R47
1 | 8.2k | YC248-JR-078K2L | YC248 | R2
8 | BAT54S | BAT54S | SOT23 | D1, D2, D3, D4, D5, D6, D7, D8 | Schottky Diodes
1 | DS1374 | DS1374U-33+T&R | UMAX10 | IC9
1 | ECX-.327-6-34RR | ECS-.327-6-34RR-TR | ECX-34RR | Y1
2 | IL300 | IL300-DEFG-X007T | DIL8-SMD | IC5, IC7
3 | ILQ1X009 | ILQ1X009 | SMD16 | OK1, OK2, OK3 | SIEMENS OPTO COUPLER
1 | LM358D | LM358DR | SO08 | IC4 | OP AMP also LM158 | LM258 | LM2904
1 | LMV614 | LMV614MTX/NOPB | TSSOP14 | IC1
1 | MAX9924 | MAX9924UAUB/V+T | UMAX10 | IC10
1 | MCP23017SS | MCP23017 E/SS | SSOP28 | IC3 | http://ww1.microchip.com/downloads/en/DeviceDoc/21952a.pdf
1 | MCP2515 | MCP2515T-E/SO | SO18W | IC13 | CAN controller with SPI interface
1 | MCP3X083008 | MCP3208-BI/SL | SO16 | IC2
1 | PESD1CAN | PESD1CANVL | SOT23 | D9 | CAN bus ESD protection diode
1 | 68R | WS5M68R0J | 0617/17 | R82
1 | SN65HVD230D | SN65HVD230D | SO08 | IC12
2 | TSV912D | TSV912AQDRQ1 | SO08 | IC6, IC8 | OP AMP also TSV912A
1 | ZXTR2105FQ | ZXTR2105FQ-7 | SOT23 | IC11
17 | Connector Pins | 1480-3-00-80-00-00-03-0 |  |  | Volvo Connectors Pins
1 | CONN_04X2 | 1053102108 |  | J2 | Sensor input
1 | CONN_04RIGHT-ANGLE | 1053141204 |  | J3 | Switched 12V
1 | CONN_04X2_MALE | 1053081208 |  |  | Sensor input male plug
1 | CONN_04_MALE | 1053081204 |  |  | switched 12V male plug
20 | MOLEX_CONNECTOR_PIN | 538-105300-2100-CT |  |  | Molex connector pins

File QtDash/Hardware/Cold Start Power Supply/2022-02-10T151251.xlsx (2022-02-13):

Index | Quantity | Part Number | Manufacturer Part Number | Description | Customer Reference | Available | Backorder | Unit Price | Extended Price USD
1 | 3 | LM3488QMM/NOPBCT-ND | LM3488QMM/NOPB | IC REG CTRLR MULT TOP 8VSSOP |  | 3 | 0 | 3.32 | 9.96
2 | 3 | 513-1147-1-ND | DRQ127-4R7-R | INDUCT ARRAY 2 COIL 4.841UH SMD |  | 3 | 0 | 3.03 | 9.09
3 | 3 | LM5060Q1MM/NOPBCT-ND | LM5060Q1MM/NOPB | IC GATE DRVR HIGH-SIDE 10VSSOP |  | 3 | 0 | 3.05 | 9.15
4 | 6 | IPB042N10N3GATMA1CT-ND | IPB042N10N3GATMA1 | MOSFET N-CH 100V 100A D2PAK |  | 6 | 0 | 3.04 | 18.24
5 | 3 | BSC027N04LSGATMA1CT-ND | BSC027N04LSGATMA1 | MOSFET N-CH 40V 24A/100A TDSON |  | 3 | 0 | 1.57 | 4.71
6 | 3 | 497-7571-1-ND | STPS8H100G-TR | DIODE SCHOTTKY 100V 8A D2PAK |  | 3 | 0 | 1.08 | 3.24
7 | 3 | PRL1632.006FCT-ND | PRL1632-R006-F-T1 | RES 0.006 OHM 1W 1206 WIDE |  | 3 | 0 | 0.6 | 1.80
8 | 10 | 445-12508-1-ND | CGA3E3X5R1H684K080AB | CAP CER 0.68UF 50V X5R 0603 |  | 10 | 0 | 0.205 | 2.05
9 | 10 | 1276-2114-1-ND | CL10B684KO8NFNC | CAP CER 0.68UF 16V X7R 0603 |  | 10 | 0 | 0.139 | 1.39
10 | 10 | PCE3487CT-ND | EEV-FK1K3R3R | CAP ALUM 3.3UF 20% 80V SMD |  | 10 | 0 | 0.223 | 2.23
11 | 10 | 1276-3364-1-ND | CL32A107MPVNNNE | CAP CER 100UF 10V X5R 1210 |  | 10 | 0 | 0.868 | 8.68
12 | 10 | 1276-6794-1-ND | CL10A475KL8NRNC | CAP CER 4.7UF 35V X5R 0603 |  | 10 | 0 | 0.322 | 3.22
13 | 100 | 311-270HRCT-ND | RC0603FR-07270RL | RES 270 OHM 1% 1/10W 0603 |  | 100 | 0 | 0.0097 | 0.97
14 | 100 | 311-30.9KFRCT-ND | RC1206FR-0730K9L | RES 30.9K OHM 1% 1/4W 1206 |  | 100 | 0 | 0.0301 | 3.01

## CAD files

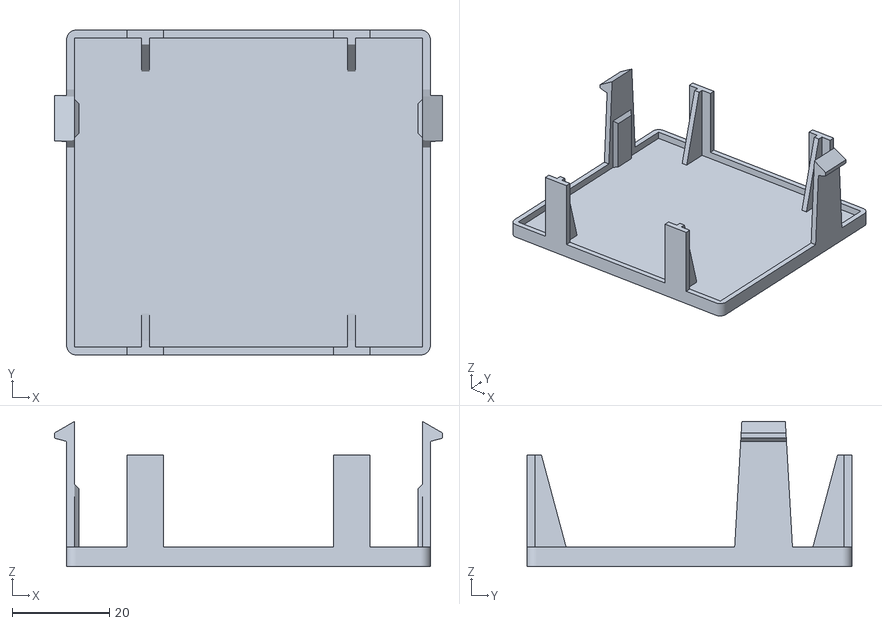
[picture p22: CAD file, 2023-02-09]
QtDash/Hardware/TouchPanel/3D Models/Small_Gauge_Cover_Whole.stl
80.0 x 67.0 x 29.9

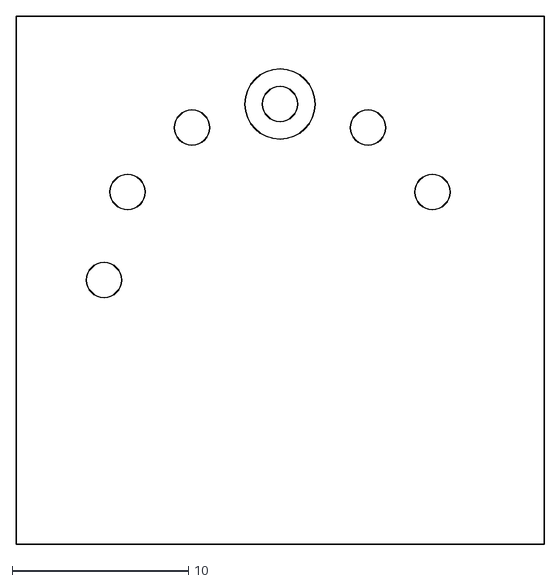
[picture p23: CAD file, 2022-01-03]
QtDash/Hardware/Dash Pinouts/Dash-Connector-32.dxf
30.0 x 30.0

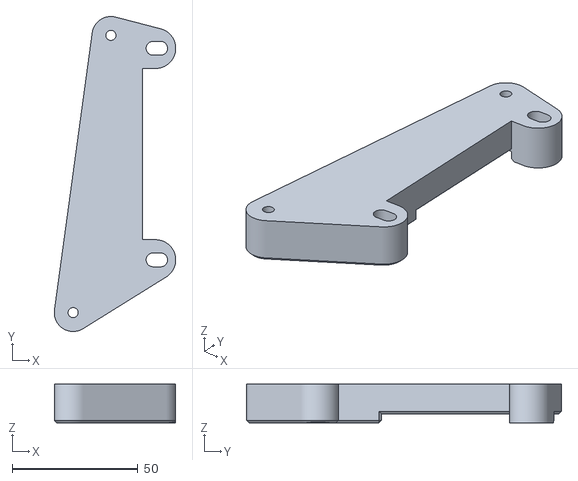
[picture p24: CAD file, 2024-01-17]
QtDash/Hardware/Screen Mounting/Mount-thick-HSD123KPW2-upsidedown-left.stl
48.2 x 125.1 x 15.4

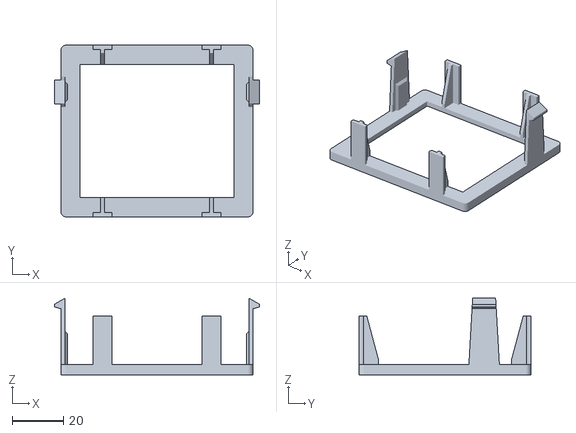
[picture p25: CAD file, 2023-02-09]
QtDash/Hardware/TouchPanel/3D Models/Small_Gauge_Cover_Cover_ w_cutout.stl
80.0 x 67.0 x 29.9

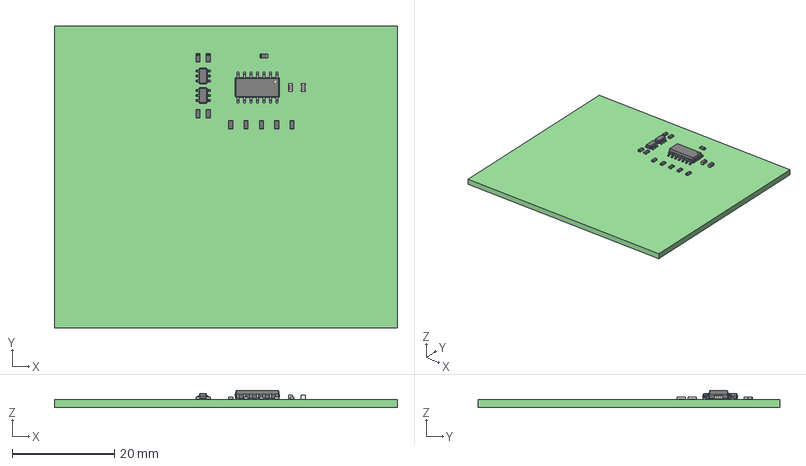
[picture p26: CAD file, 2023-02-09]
QtDash/Hardware/TouchPanel/touch_panel/touch_panel.step
67.0 x 59.0 x 3.40 mm
touch_panel PCB

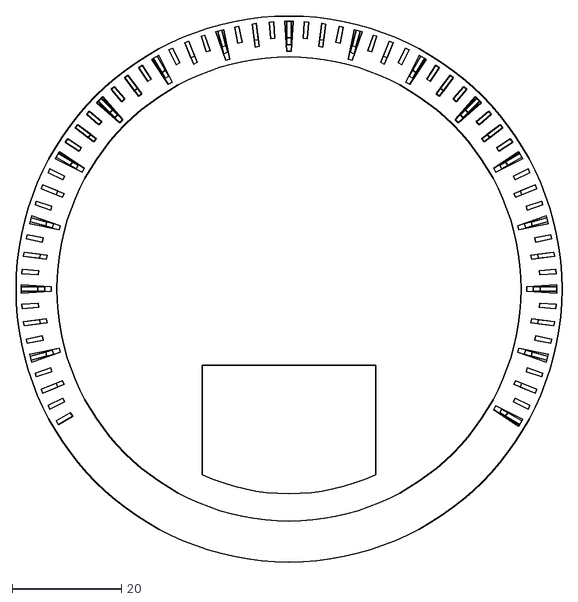
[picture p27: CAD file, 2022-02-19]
QtDash/s60R gauges/face.dxf
100.0 x 100.0

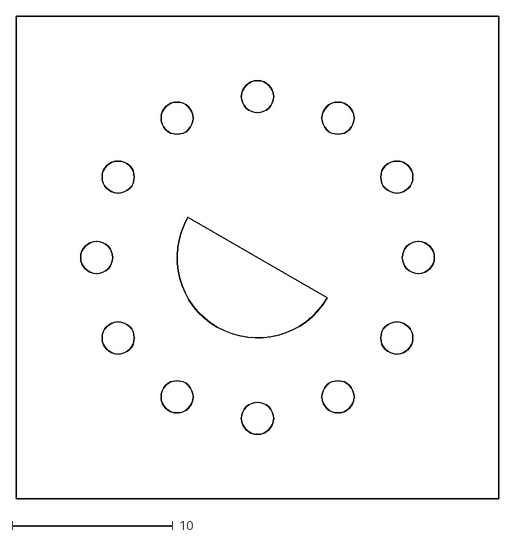
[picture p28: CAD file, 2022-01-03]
QtDash/Hardware/Dash Pinouts/Dash-Connector-31.dxf
30.0 x 30.0

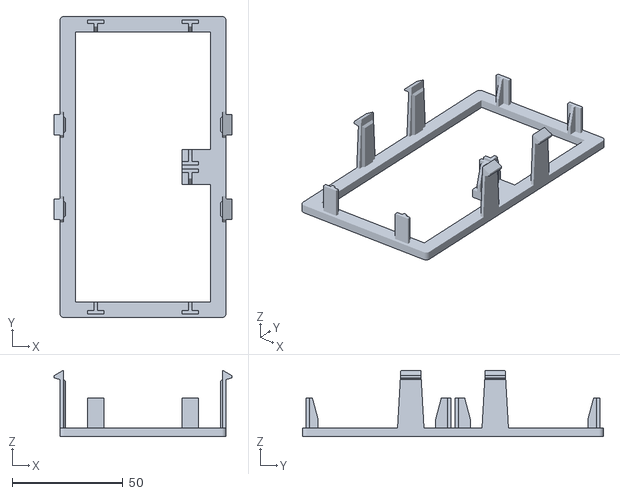
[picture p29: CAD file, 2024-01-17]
QtDash/Hardware/Screen Mounting/accessory_screen_double_cover.stl
80.0 x 135.6 x 29.9

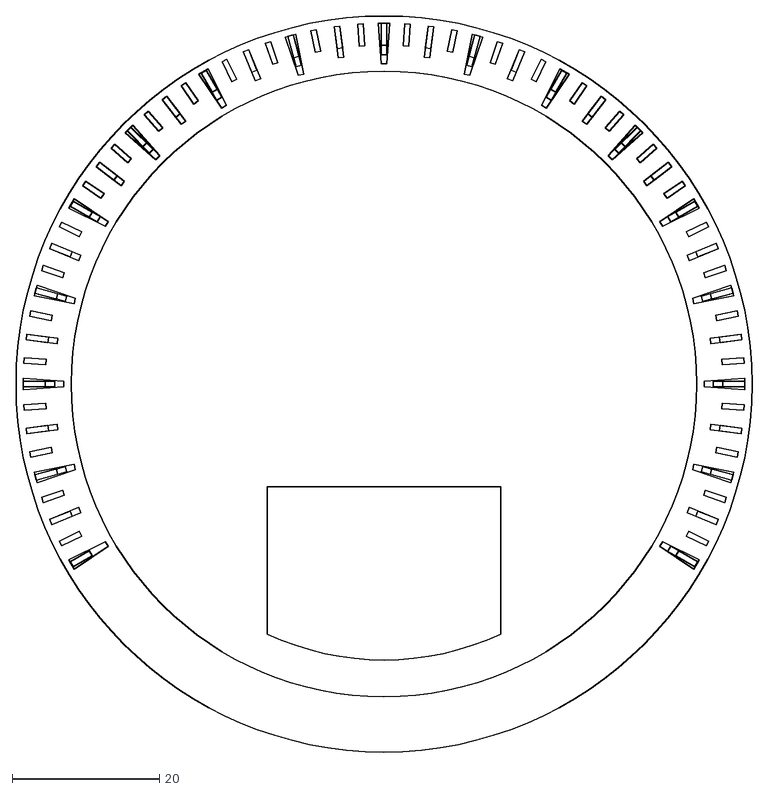
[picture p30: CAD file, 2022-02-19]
QtDash/s60R gauges/face_all.dxf
100.0 x 100.0

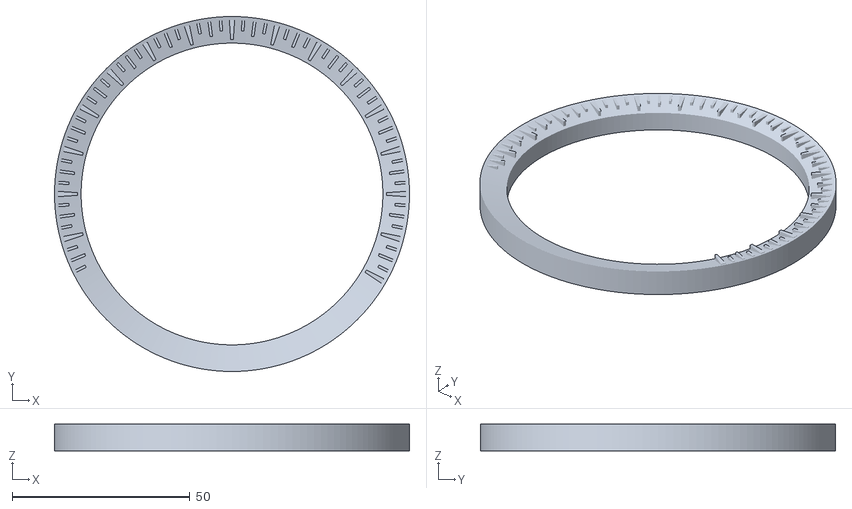
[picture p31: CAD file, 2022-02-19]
QtDash/s60R gauges/outerface.stl
100.0 x 100.0 x 7.50

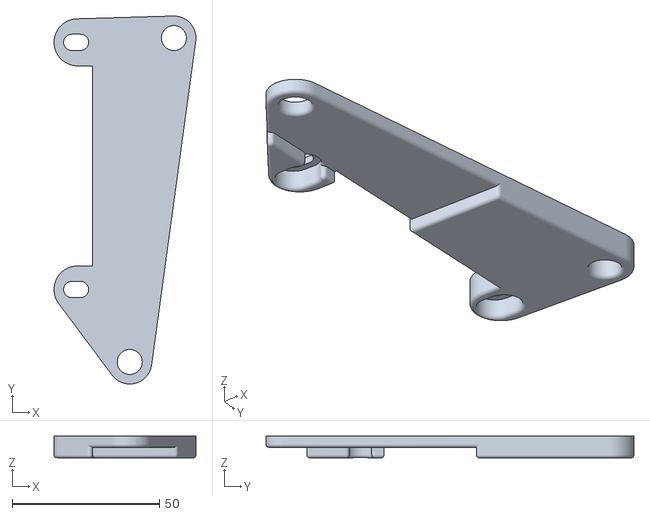
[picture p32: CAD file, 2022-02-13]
QtDash/Hardware/Screen Mounting/Mount-HSD123KPW2-right.stl
48.2 x 125.1 x 7.40

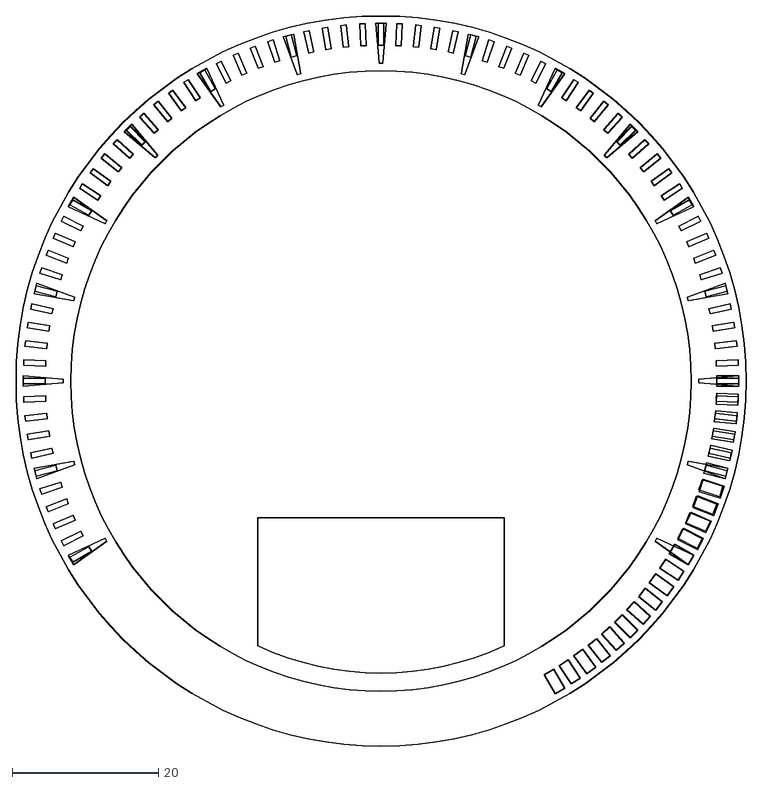
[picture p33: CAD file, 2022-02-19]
QtDash/s60R gauges/tach-face.dxf
100.0 x 100.0

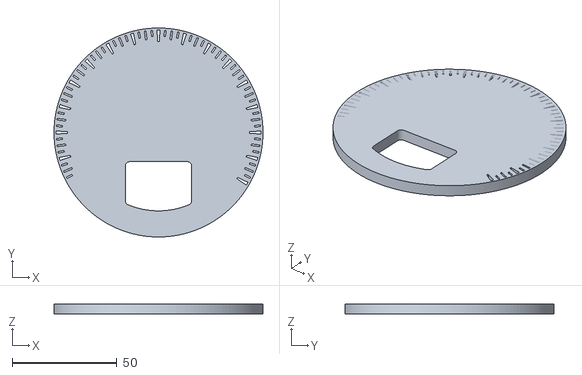
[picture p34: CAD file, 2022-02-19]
QtDash/s60R gauges/innerface.stl
100.0 x 100.0 x 5.00

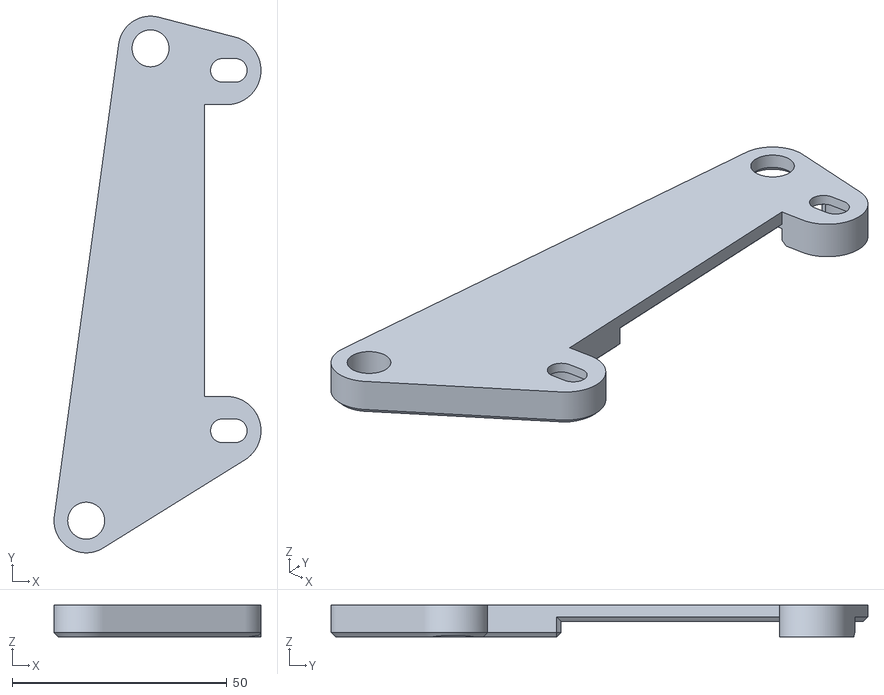
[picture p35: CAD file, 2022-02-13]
QtDash/Hardware/Screen Mounting/Mount-HSD123KPW2-upsidedown-left.stl
48.2 x 125.1 x 7.40

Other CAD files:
QtDash/Hardware/Screen Mounting/Mount-thick-HSD123KPW2-upsidedown-right.stl
QtDash/Hardware/Screen Mounting/Mount-HSD123KPW2-left.stl
QtDash/Hardware/Screen Mounting/Electronics Mount.stl
QtDash/Hardware/Screen Mounting/Electronics Mount-right.stl
QtDash/Hardware/Screen Mounting/Electronics Mount-left.stl
QtDash/Hardware/Screen Mounting/Mount-HSD123KPW2-upsidedown-right.stl

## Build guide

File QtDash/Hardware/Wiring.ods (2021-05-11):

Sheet: Tach Pinout
Marking | Wire Color (93) | Connection
G | Black | GND
1 | Green/White | VR sensor input
+ | Blue | +12V

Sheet: Circular Cluster Connector
Connector Pos | Color (Diagram) | Color (JY 93 Cluster) | Function | Warning Light (if applicable) | Gauge (if applicable)
1 | Green | Gray | Brake Fail Switch | Brake Failure
2 | Yellow | Yellow | Temp Sensor | N/A | Coolant Temp
3 | White/Red | White/Red | Step Relay (?) | High Beam On/Off
4 | Brown/Black | Brown/Black | SRS Ctrl Unit | SRS Warning (?)
5 | Black | Black | Oil Pressure Sensor | Low Oil Pressure
6 | Blue/Black | Blue/Black | Fuel Injection ECU
7 | Blue | Blue | DIR SW | Right Blinker
8 | Blue/Green | Blue/Green | DIR SW | Left Blinker
9 | Green | Green | Fuse #8 (power)
10 | Brown | Brown | Convenience Lights
11 | Red | Red | Alternator | Low Voltage/Battery
12 | Blue/Yellow | Blue/Yellow | Blub Failure Sensor | Bulb Failure

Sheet: C Shaped Connected
Connector Pos | Color (Diagram) | Color (JY 93 Cluster) | Function | Warning Light (if applicable) | Gauge (if applicable)
1 | Gray/White | Gray/White | Fuel Sensor |  | Fuel
2 | Brown | Brown | Parking Brake Switch | Parking Brake
NC | N/A | N/A | N/A
A | Gray | Not Present | Fuse #16 (+12V)
3 | Green | Green | ABS Control Unit | ABS
4 | Black | Black | GND

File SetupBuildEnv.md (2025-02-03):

# Setting up Build Environment

## Install Virtual Box
If not already running linux, you can install a virtual machine using VirtualBox. Detailed instructions on setting up Ubuntu using VirtualBox can be found [here](https://ubuntu.com/tutorials/how-to-run-ubuntu-desktop-on-a-virtual-machine-using-virtualbox#1-overview). 

It is recommended to up the drive size from 25GB to 50GB. These instructions assume that you are installing Ubuntu 24.04 LTS

## Cloning the repository
After installing a vanilla version of Ubuntu 24.04 on a virtual box instance, its time to actually clone the repo:

```
sudo apt update
sudo apt upgrade
```
then

```
sudo apt install git git-lfs
```

Cloning the repo, first making sure you're in the home directory and then making a git directory so its not cloned directly in home:

```
cd ~/
mkdir git
cd git
git clone https://github.com/whitfijs-jw/Volvo240-DigitalDash.git --recurse-submodules
```
## Install necessary packages for Buildroot
After the clone you'll need to install the necessary packages for buildroot (from [here](https://buildroot.org/downloads/manual/manual.html#requirement-mandatory), with the exception of python-is-python3):

```
sudo apt install which sed make binutils build-essential diffutils gcc g++ bash patch gzip bzip2 perl tar cpio unzip rsync file bc findutils wget python-is-python3
```

## Configure Buildroot
Navigate into the buildroot directory (from ~/git/)

```
cd Volvo240-DigitalDash/buildroot/
```

Set the current configuration so that we're building for the dash:

For configuring Buildroot to build an image for a Raspberry Pi 4 use:
```
make volvodash_rpi4_defconfig
```

For configuring Buildroot to build an image for a Raspberry Pi 3 use:
```
make volvodash_defconfig
```

## Building the image

Cross your fingers and then run:

```
make
```

This is going to take a while, many hours if you're running it on a laptop or older computer.

## Finding the output image

The output produced from build are located here:

```/buildroot/output/images```

This directory contains the outputs of the buildroot compilation process. After buildroot is done compiling the custom linux image, compiling the specified target packages, and constructing the target rootfs and bootfs, an image that can be flashed on to an SD card is placed here. ```sdcard.img``` can then be flashed on to an SD card to be used on a pi. As a part of the compilation/building the Qt Dash app should be compiled and placed within this image.

## Flashing the image to an SD card

The easiest way to flash the image (```sdcard.img```) onto an SD card for use on a pi is to use a utility like the [Raspberry Pi Imager](https://www.raspberrypi.com/software/). In the imager utility select the "Choose OS" option, scroll all the way down and select the "Use Custom" option. Navigate to where the repository is cloned then to ```buildroot/output/images```. There should be a file named ```sdcard.img```. After selecting the image file, select your sdcard using the "Choose Storage" option. Hit write and wait.

After writing has completed you can plug the SD card into the pi and boot. The dash app should start up automatically.

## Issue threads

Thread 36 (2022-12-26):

Network not coming up on Rev B hardware

whitfijs-jw, 2022-12-26:
To boot can0 + mcp2515 in config.txt in boot partition had to be disabled.

Check if network interfaces needs to be tweaked as well to remove can0 bringup

whitfijs-jw, 2022-12-26:
These are the changes made to /etc/network/interfaces on rev B hardware that resulted in eth0 working again:

`auto lo
iface lo inet loopback

auto eth0
iface eth0 inet static
      address 192.168.42.2
      netmask 255.255.255.0

#auto can0
#iface can0 inet manual
#    pre-up /sbin/ip link set can0 type can bitrate 500000 triple-#sampling on restart-ms 100
#    up /sbin/ifconfig can0 up
#    down /sbin/ifconfig can0 down
`

EvripidesKarseras, 2023-09-03:
Hi,

I having difficulty getting the network working on the rev B hardware. This is the first time I am trying this whole buildroot/pi deal.

When the whole thing was compiling I got an error about the sftp server not finding python 2.4 or better and I applied a fix I found on the buildoort mailing list. Ended up finishing succesfully generating the image.

Bit off topic but, I haven't got the custom boards/adc/etc, would that mean that the app will not just fire up on the pi? I haven't read any of the code yet btw so don't really know how the whole state machine is supposed to work.

Thanks for the work you've put into this. It is brilliant.

Regards,
Evros

whitfijs-jw, 2023-09-03:
Hey! I'll have to test with a bare pi to see what happens -- it's been a little while since I've done bench testing.  From what I remember, the only thing that holds the eth0 network from starting is the can0 interface failing to come up.  Otherwise, I don't think the app really cares if any of the other devices are present -- I will verify this on the bench as soon as I can.

First things first, can you tell me what your setup is?:

- What version pi are you using?
- What screen, if any, do you have hooked up?
- What branch/commit are you building from?

Another thing to verify is that you've gone through setting up your network manager (assuming you're using some version of ubuntu):

> Remote Access

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

EvripidesKarseras, 2023-09-04:
Hi J,

Thanks for replying. I tried to sign up on the forum but I could not reach you via pm so I thought I'd write you over here.

Short story, I began building something similar in a bare-metal fashion with embedded graphics libraries, etc, but it is taking ages and the result is going to need a lot of work to reach Qt levels of eye-candiness. I bumped on your project in youtube and thought I'd give it a go. When I first started considering a digital dash I didn't think you'd get fast enough boot times. This qt/buildroot/pi thing is too softwarey for my skills. I digress.

1. I am using a pi4 B, 8GB currently on sale at mouser.
2. I haven't got a dedicated screen yet, I am using the pc monitor.
3. I am using the main branch. I am not well versed in Git, I only know the basics.

Let me know if you want to be contacted elsewhere.

Cheers,
Evros

whitfijs-jw, 2023-09-05:
Sorry, I didn't get any notifications on the tb forums, not sure whats up -- if we can work it out on here maybe it'll help someone with a similar issue in the future.

I've done a fair amount of work with stm32's and LVGL so I get not wanting to go through the hassle of low level firmware development on something like this.

Back on task:
Does anything come up on screen? I tested with a pi 400 on the bench with nothing attached and everything started alright.

The only change I had to make was that I edited the file /etc/network/interfaces on the rootfs partition of SD card so that the can0 setup is either deleted or commented out.  That should allow the network to come up on eth0 at 192.168.42.2.  The current buildroot image doesn't have any wifi drivers, as an attempt at boot time optimization, so you'll have to plug in an ethernet cable to your host computer.

EvripidesKarseras, 2023-09-06:
Hi J,

1. I managed to sort the network out by commenting out the can0 interface.
2. The display issue got resolved by me not being an idiot and plugging the cable in the wrong port!

Thanks for jumping in. I am slowly starting to get the hand of this OS thing, I never worked with anything at such a high level.

Have you got any idea what sort of peculiar resolutions does the pi support? If I can get one that integrates in my dash nicely I will proceed. This is not for a volvo so some extra development is needed on the hardware side.

Cheers,
Evros

whitfijs-jw, 2023-09-06:
Good news!  I started this project to get more familiar with buildroot and embedded linux in general. It took a little while to figure out what's going on and can be time consuming to rebuild images constantly.

The screen that fits the 240 almost perfectly is a 12.3" 1920x720 ([amazon link](https://www.amazon.com/gp/product/B09KN463M4/)) that I drive at 1280x480 to keep asset sizes a little smaller so the Qt app boots a little faster.  You can manually edit the config.txt file in the boot partition of the SD card.  The section you can play around with is, specifically the hdmi_cvt line:
```
#hdmi_safe=1
hdmi_cvt 1280 480 60 5 0 0 0
hdmi_group=2
hdmi_mode=87
hdmi_force_hotplug=1
config_hdmi_boost=4
```
HDMI mode 87, group 2 is meant for custom configurations ([more info here](http://wiki.sunfounder.cc/index.php?title=Adjust_Resolution_for_Raspberry_Pi)).  Once you have a screen you want and a config that works you can go into `buildroot/boards/volvodash/` and edit the config-rpi4.txt file to match the changes you've made on the SD card.  That way any future buildroot images you generate will already have your changes.

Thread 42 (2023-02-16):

Long press mapping for user inputs -- trip odometer resetting

whitfijs-jw, 2023-02-16:
Long pressing a button should be configurable -- start with trip odometer resetting.

Closed 2023-03-02.

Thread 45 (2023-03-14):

Multiple screens + touch screen control (for smaller side screen)

whitfijs-jw, 2023-03-14:
Replace the cap-touch board with a 5" capacitive touch screen -- would only work with dual HDMI output rpi4.

todo:
- get EGLFS up and running on multiple screens (json?)
- create new layouts for accessory screen
- add support for side screen touch controller
- add touch controls to side screen for main display (left, right, reset trip, etc)
- (nice to have) possibly change accessory gauge style based on current main display style

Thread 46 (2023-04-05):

Pi Zero Support

whitfijs-jw, 2023-04-05:
Work on Pi Zero/Zero 2 support for a linux image along with the Pi3 and Pi4 images that are currently setup

whitfijs-jw, 2024-03-13:
While this works, boot times are hilariously long.  I don't recommend using a pi zero unless you're very patient.

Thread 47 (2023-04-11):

Input power protection is missing + 12V dash light input protection is suspect

whitfijs-jw, 2023-04-11:
Switched 12V from VSS connector to power supply is unprotected from reverse polarity and load dump.
Options:
    - Big (5-7kW) unidirectional TVS diode to to cover both situations.  Main goal is to limit load dump voltage spike to be within the voltage range of the power and other inputs.  (https://www.littelfuse.com/~/media/electronics/datasheets/tvs_diodes/littelfuse_tvs_diode_sld8s_datasheet.pdf.pdf)
    - Bidirectional TVS diode for load dump and schottky diode for reverse voltage protection.

12V input protection is a little more open ended.

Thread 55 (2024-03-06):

ADC voltage calculation incorrect

whitfijs-jw, 2024-03-06:
In adc.h:
```
/* 5V inputs go through voltage divider for 3.3V ADC inputs -- not quite 100% */
static constexpr double REFERENCE_VOLTAGE_DIVIDER = (15.0e3 / (15.0e3 + 8.2e3));
static constexpr double INPUT_VOLTAGE_DIVIDER = (15.0e3 / (15.0e3 + 8.2e3));
static constexpr double VOLTAGE_CONVERSION_CORRECTION_FACTOR = 3.3 / (INPUT_VOLTAGE_DIVIDER * 5.0);
```
farther down:

```
    /**
     * @brief Read scaled ADC value
     * @param channel: adc channel to read
     * @return current measured voltage
     */
    double readValue(int channel, double vRef = -1) {
        double volts = ((double)readRawValue(channel) / (double)mMaxVal);

        if (vRef < 0) {
            updateReference();
            return volts * mVref * VOLTAGE_CONVERSION_CORRECTION_FACTOR;
        } else {
            return volts * vRef;
        }
    }
```

Not sure what happened but the multiplication by mVref and division by 5.0 are superfluous and introduce a small error.

Closed 2024-03-10.

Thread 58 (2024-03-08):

Late 70's/Early 80's 240 dash connector support

whitfijs-jw, 2024-03-08:
Late 70's/Early 80's dash connectors are physically similar to the late 80's connectors for which this was designed to support.  There should at least be some documentation on how a patch harness should be wired to work with the existing connections on the board.

As a part of this effort it's probably worthwhile to make an untested/unconfirmed section of the readme:
- VSS passthrough to the ECU on LH2.4/3.1 cars
- Anything to do with ABS/SRS on early 90's 2.4/3.1 cars
- Manual or automatic OD indicators (only tested with an M47)
- Probably a lot more

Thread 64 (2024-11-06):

Fuel gauge filtering

whitfijs-jw, 2024-11-06:
The fuel gauge swings too much during long up/down hills or around long sweeping turns.  Looking into using decaying filter coefficients so that it reports the fuel value on start up quickly, but then slows/damps updates after the initial start period.

Closed 2024-12-24.

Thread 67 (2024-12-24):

Missing documentation for feature/64 and feature/63 updates

whitfijs-jw, 2024-12-24:
missed documentation update for fuel level filtering and multi-unit gauge update

Closed 2024-12-24.

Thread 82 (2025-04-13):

BOM Missing

Pieterccc, 2025-04-13:
The BOM files appear to be missing for Every board other than the Dash_hat

Pieterccc, 2025-04-13:
Also please put the Gerber files in. I know im doing something wrong, but I am struggling to make them properly

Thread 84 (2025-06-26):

remove dependency on erthink/libmdbx because its 🇷🇺 author collects money to kill Ukranians 🇺🇦

srghma, 2025-06-26:
This issue was created automatically bc search showed that You use [https://github.com/erthink/libmdbx](https://github.com/erthink/libmdbx/issues/280).

## Describe the issue

On https://gitflic.ru/user/erthink @erthink collects money for 🇷🇺 occupants to kill [🇺🇦 children](https://daily.zt.ua/lviv-znaydene-tilo-divchynky-v-zavalynakh-pislia-prylotu-divchynka-zahynula/) and occupy my home (I am from Donetsk, Rodynskoye, my city is on the line, they already destroyed city and hunt ordinary people with drones. Also, russians tortured my friend Ivan for flag of 🇺🇦 Ukraine in 📱 mobile phone)

I would suggest to drop this dependency:
- (minimum) You support someone who kills [🇺🇦 children](https://daily.zt.ua/lviv-znaydene-tilo-divchynky-v-zavalynakh-pislia-prylotu-divchynka-zahynula/)
- (maximum) @erthink can inject malicious code

## Why @erthink does this?

### 1. Maybe he thinks that Ukraine is full of nazis

But this is not true.

@erthink,

- I ask You to help me. In Russia there is a Nazi called Alexei Milchakov. He told in interview that [he cuts hands of Ukranians and puts then in a jar](https://www.instagram.com/reel/C2Q9D0_L4mG/?hl=en). @erthink, Let's conduct an experiment. You write a petition to 🇷🇺 president putin and ask him to take away the 🎖️ medal [that he gave to Milchakov](https://rossaprimavera.ru/article/provokaciya-udalas-aksenov-nagradil-nacista-milchakova). And I will write a petition to my 🇺🇦 president so that he punish some Nazi in the Ukrainian army. If You will find one. Let's see which country has better ["mechanisms of finding and correcting errors"](https://www.youtube.com/watch?v=tw1m__JutoY).

  - Result: Actually, I have asked him this 100 times, he ignored. Which means he either is a Nazi or he fears punishment.

- I ask You to help me. Let's come to Red Square in Moscow together and stand on a street with a poster ["russians tortured my friend Ivan" (slide 85)](https://docs.google.com/presentation/d/1x1WXcqXbxWo-Nj3lzXgcSBTdmV-8Ohs9lGZDlfMI76g/edit). By law, police should not arrest us, because we do not call for bloodshed, but this is a good way to check whether freedom of speech in Russia is allowed.

- I ask You to help me. Let's come to Red Square and tell "Serhii Khoma asked everyone in his city Rodynskoye whether they want to be part of Russia and everyone asked no. Therefore, Rodynskoye should not be occupied". (In [Ukraine we can tell "Donetsk should be part of russia"](https://x.com/DavidDeutschOxf/status/1877999499395625319), but can people tell "Donetsk should be part of Ukraine" in russia?)

- I ask You to make an interview with me. I will post it on [my Youtube channel](https://www.youtube.com/@srghma).

  - Result: Actually, I have asked him this 100 times, he ignored.

### 2. He told "I am a patriot of my country. Just like You or Chinese people".

No, @erthink, You are traitor of 🇷🇺 russia and humanity, bc You want more countries 🇺🇦 to be a Static Society of Karl Popper. Society where You Yourself fear to criticize Your government.

@erthink, ❤️ I am Your friend.

- I wish all humans to live forever and have infinite amount of children.
- I believe the amount of food, territory, energy and [computation](https://x.com/DavidDeutschOxf/status/958977281694846976) in Universe is infinite and limited only by our knowledge.
- (Just like [David Deutsch](https://www.youtube.com/watch?v=gQliI_WGaGk&ab_channel=TED) and [Frank Tipler](https://www.amazon.com/Physics-Immortality-Modern-Cosmology-Resurrection/dp/0385467990)) I believe humans can live forever. I believe one day humans will stop heat death of the universe or any other unforseen problem.

BUT there is a catch.

Since ["open society—the only stable kind of society"](https://www.daviddeutsch.org.uk/wp-content/uploads/2019/07/PossibleMinds_Deutsch.pdf), therefore (I believe) only Open Society of Karl Popper can give humans infinite life. Because only this type of society can have infinite progress, which is required to prevent unforseen problems.

So, @erthink, why You want to take my home and kill [🇺🇦 children](https://daily.zt.ua/lviv-znaydene-tilo-divchynky-v-zavalynakh-pislia-prylotu-divchynka-zahynula/)? Lets talk?

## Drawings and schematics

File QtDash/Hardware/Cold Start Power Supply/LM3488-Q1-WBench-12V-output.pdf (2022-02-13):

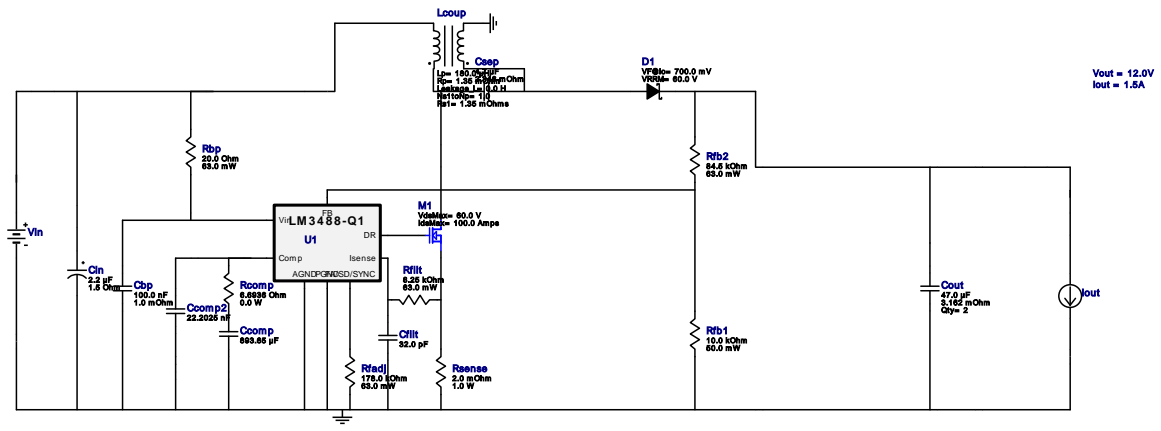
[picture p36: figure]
Rfb2 84.5 kOhm 63.0 m W; Cfilt 32.0 pF; Csep 4.7 µF 2.346 m Ohm; Rfb1 10.0 kOhm 50.0 m W; Com p; Isense; AGNDPGND; FA/SD/SYNC; Vin; Cbp 100.0 nF 1.0 m Ohm; Lcoup; Lp= 180.0 µH Rp= 1.35 m Ohm; Leakage_L=; Ns1toNp= 1.0 Rs1= 1.35 m Ohm s; Rsense 2.0 m Ohm 1.0 W; Ccom p2 22.2025 nF; D1 VF@Io= 700.0 m V VRRM= 60.0 V; Cin 2.2 µF 1.5 Ohm; Rfilt 8.25 kOhm; M1 VdsMax= 60.0 V IdsMax= 100.0 Am ps; Ccom p 893.65 µF; Rcom p 6.6936 Ohm 0.0 W; Vout = 12.0V Iout = 1.5A; Cout 47.0 µF; 3.162 m Ohm Qty= 2; Rfadj 178.0; kOhm; Rbp 20.0 Ohm 63.0 m W; Iout

Copyright © 2022, Texas Instruments Incorporated | 1 | ti.com/webench

WEBENCH®
Design Report LM3488QMM/NOPB : LM3488QMM/NOPB 3V-22V to 12.00V @ 1A February 9, 2022 19:38:25 GMT-06:00

## WEBENCH ® Design Report

Design : 4 LM3488QMM/NOPB
LM3488QMM/NOPB 3V-22V to 12.00V @ 1A

VinMin = 3.0V
VinMax = 24.0V
Vout = 12.0V
Iout = 1.5A

Device = LM3488QMM/NOPB
Topology = SEPIC
Created = 2022-02-09 19:24:12.025 BOM Cost = NA
BOM Count = 19
Total Pd = 3.29W
1. Please note that Loop/ stability model has not been implemented for this device.The opertating values and charts related to loop model are disabled.

## Electrical BOM

Name | Manufacturer | Part Number | Properties | Qty Price | Footprint
Cbp | Yageo | CC0805KRX7R9BB104 (http://www.yageo.com/documents/recent/UPY%2DGPHC%5FX7R%5F6.3V%2Dto%2D50V%5F7.pdf) Series= X7R | Cap= 100.0 nF ESR= 1.0 mOhm VDC= 50.0 V IRMS= 0.0 A
1 | $0.02
| | | | | 0805 7 mm²
Ccomp | CUSTOM | CUSTOM Series= ?

Cap= 893.65 uF
VDC= 0.0 V
IRMS= 0.0 A

1 NA
CUSTOM 0 mm²
Ccomp2 | CUSTOM | CUSTOM Series= ?

Cap= 22.2025 nF
VDC= 0.0 V
IRMS= 0.0 A

1 NA
CUSTOM 0 mm²
Cfilt | AVX | 06033A320FAT2A (http://www.avx.com/docs/Catalogs/ccog.pdf) Series= C0G/NP0

Cap= 32.0 pF
VDC= 25.0 V
IRMS= 0.0 A

1 $0.11
0603 5 mm²
Cin | AVX | TPSA225K035R1500 (http://www.avx.com/docs/masterpubs/tantniob.pdf) Series= TPS

Cap= 2.2 uF
ESR= 1.5 Ohm
VDC= 35.0 V
IRMS= 201.0 mA

1 $0.22
3216-18 11 mm²
Cout | TDK | C5750X5R1C476M230KA (https://product.tdk.com/en/search/capacitor/ceramic/mlcc/info?part%5Fno%3DC5750X5R1C476M230KA) Series= X5R

Cap= 47.0 uF
ESR= 3.162 mOhm
VDC= 16.0 V
IRMS= 5.1344 A

2 $0.72

2220_250 54 mm²
Csep | TDK | CGA4J1X7R1V475K125AC (https://product.tdk.com/en/search/capacitor/ceramic/mlcc/info?part%5Fno%3DCGA4J1X7R1V475K125AC) Series= X7R

Cap= 4.7 uF
ESR= 2.346 mOhm
VDC= 35.0 V
IRMS= 4.2602 A

1 $0.16
0805 7 mm²
D1 | Diodes Inc. | B560C-13-F (http://www.diodes.com/datasheets/ds13012.pdf) | VF@Io= 700.0 mV VRRM= 60.0 V
1 | $0.17

SMC 83 mm²

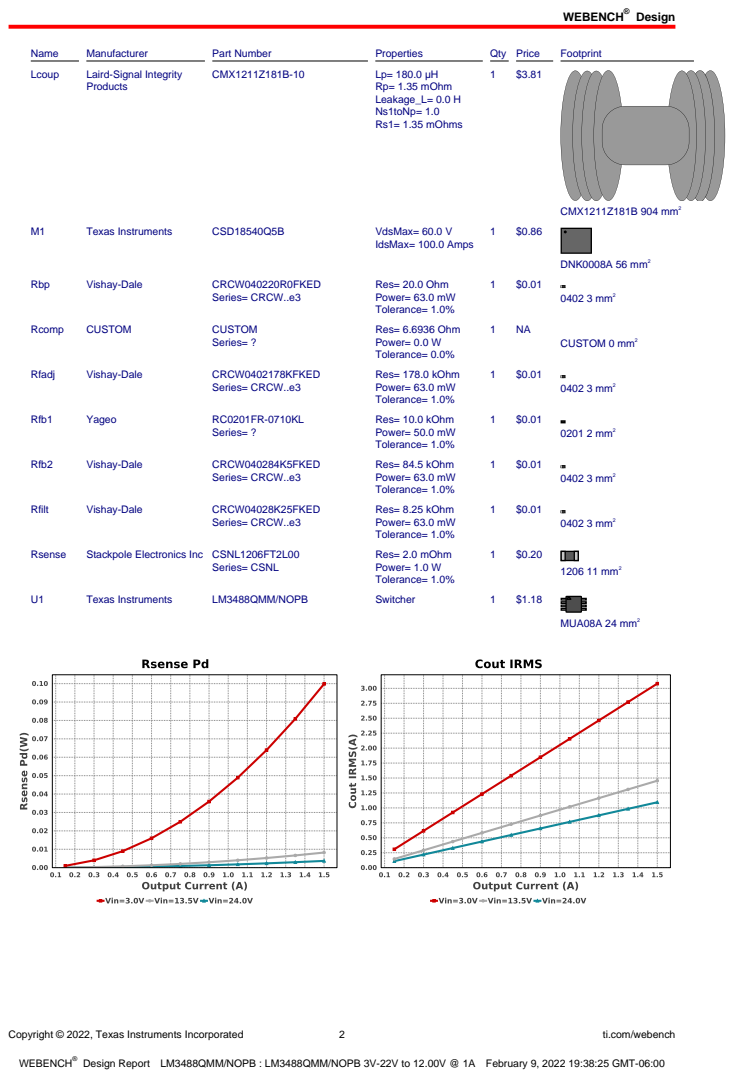
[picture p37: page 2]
Design; Copyright © 2022, Texas Instruments Incorporated; ti.com/webench; Name; Manufacturer; Part Number; Properties; Qty Price; Footprint; Lcoup; Laird-Signal Integrity; Products; CMX1211Z181B-10; Rp= 1.35 mOhm Leakage_L= 0.0 H Ns1toNp= 1.0 Rs1= 1.35 mOhms; CMX1211Z181B 904 mm²; Texas Instruments; CSD18540Q5B; VdsMax= 60.0 V; IdsMax= 100.0 Amps; DNK0008A 56 mm²; Rbp; Vishay-Dale; CRCW040220R0FKED; Series= CRCW..e3; Res= 20.0 Ohm Power= 63.0 mW Tolerance= 1.0%; 0402 3 mm²; Rcomp; CUSTOM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

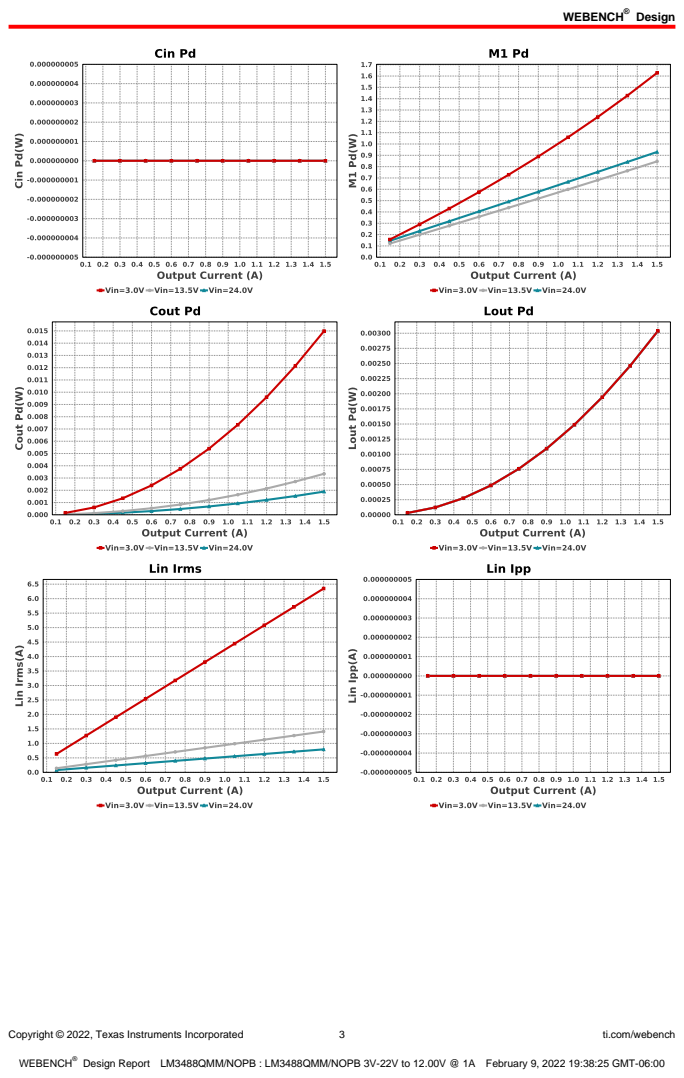
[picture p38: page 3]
Copyright © 2022, Texas Instruments Incorporated; ti.com/webench

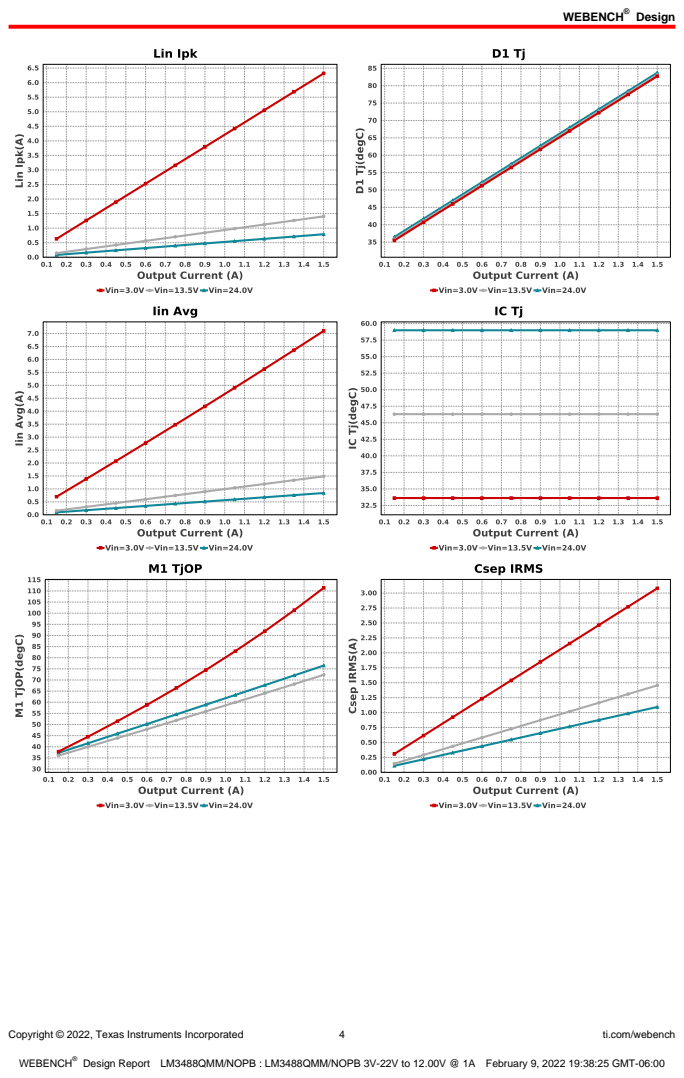
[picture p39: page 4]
Copyright © 2022, Texas Instruments Incorporated; ti.com/webench

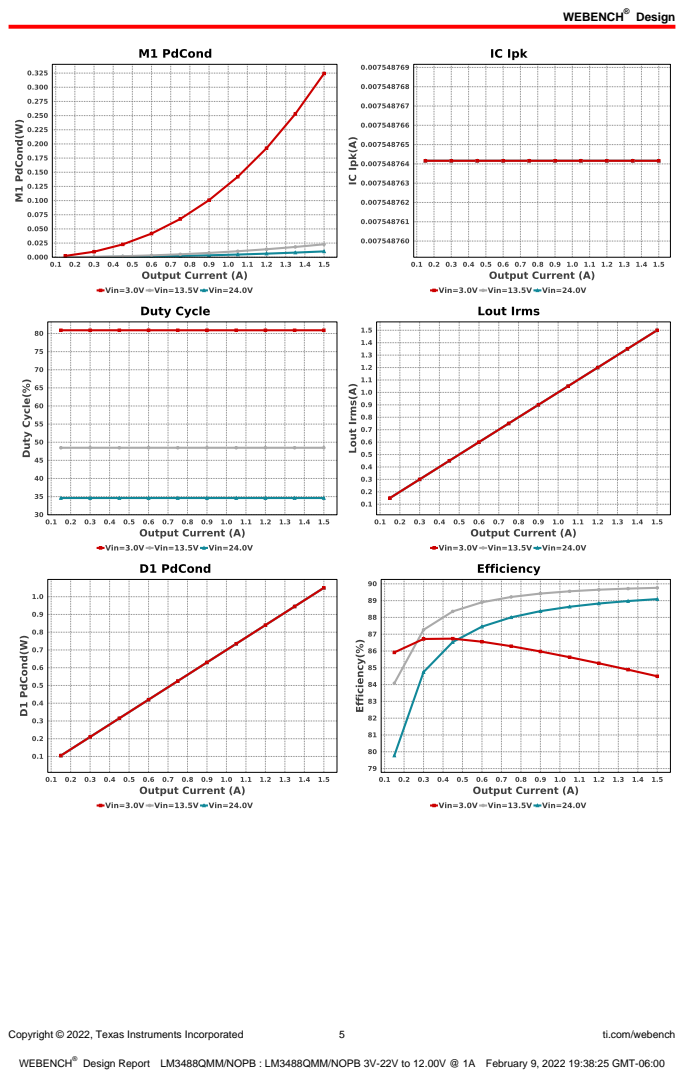
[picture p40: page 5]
Copyright © 2022, Texas Instruments Incorporated; ti.com/webench

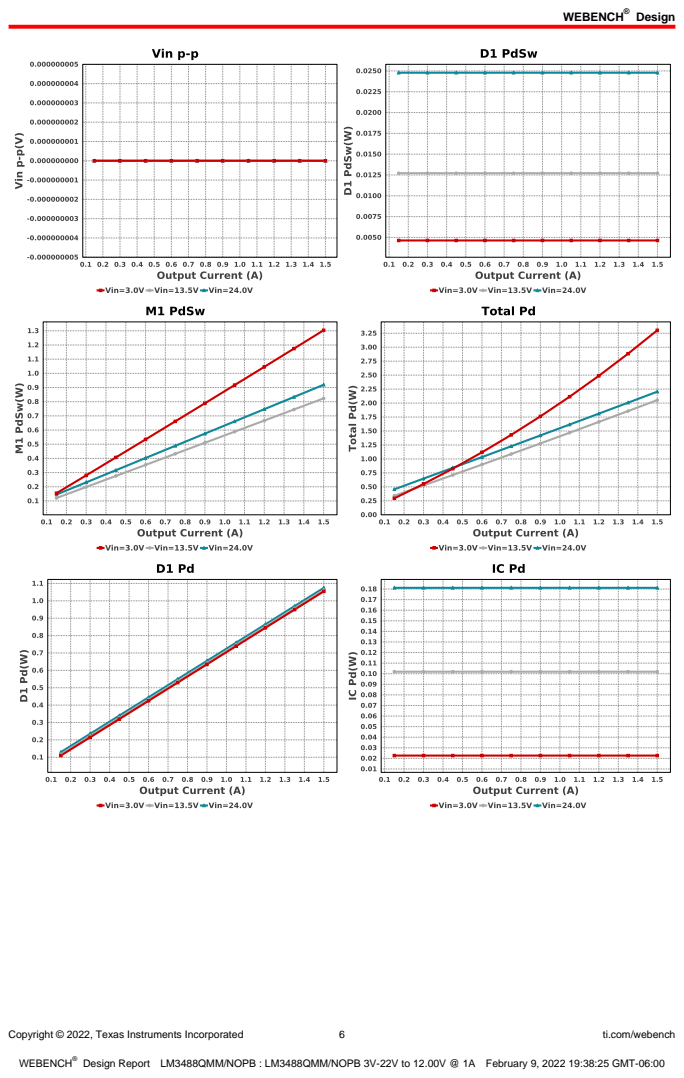
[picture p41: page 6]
Copyright © 2022, Texas Instruments Incorporated; ti.com/webench

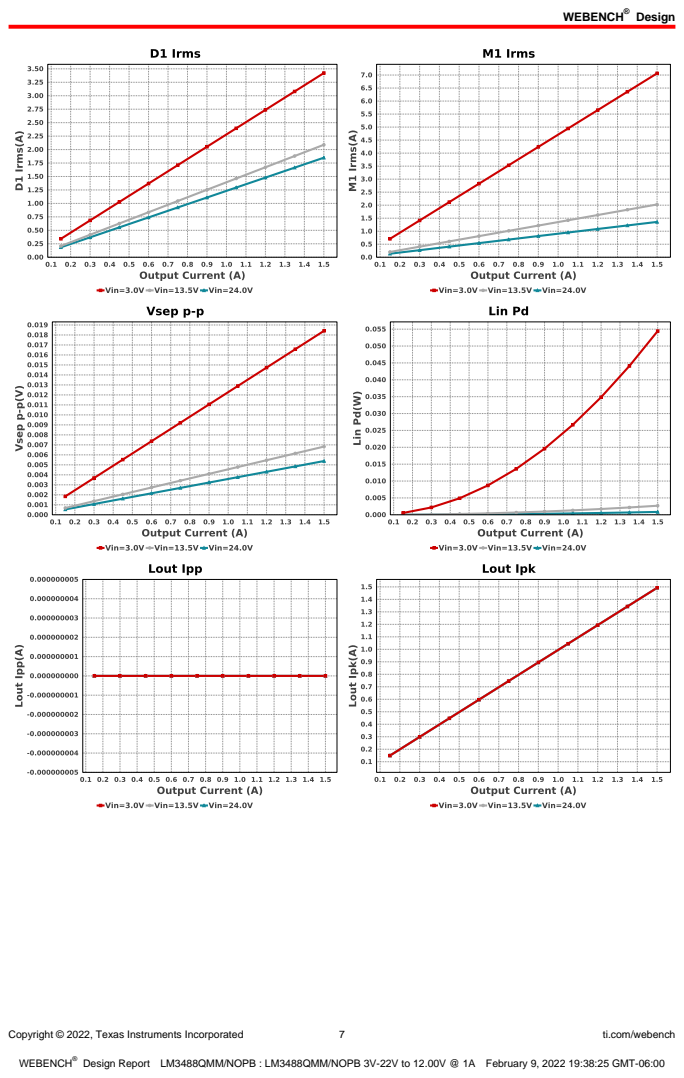
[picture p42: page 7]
Copyright © 2022, Texas Instruments Incorporated; ti.com/webench

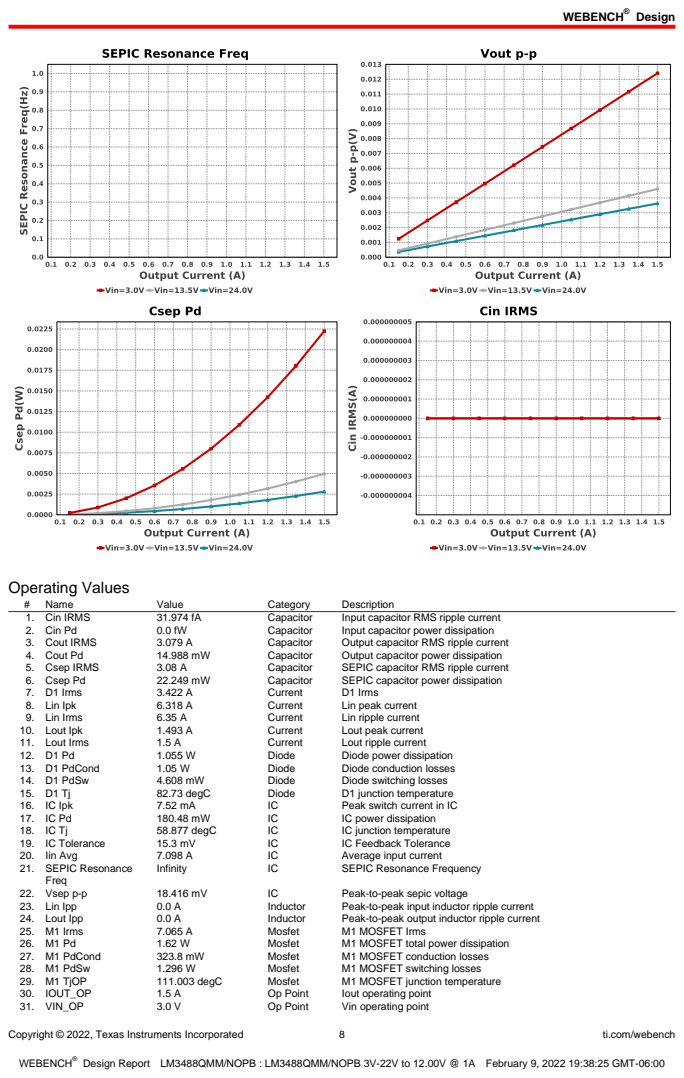
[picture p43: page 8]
Copyright © 2022, Texas Instruments Incorporated; ti.com/webench; Operating Values; Name; Value; Category; Description; 1. Cin IRMS; Capacitor; Input capacitor RMS ripple current; 2. Cin Pd; Input capacitor power dissipation; 3. Cout IRMS; Output capacitor RMS ripple current; 4. Cout Pd; Output capacitor power dissipation; 5. Csep IRMS; SEPIC capacitor RMS ripple current; 6. Csep Pd; SEPIC capacitor power dissipation; 7. D1 Irms; Current; D1 Irms; 8. Lin Ipk; Lin peak current; 9. Lin Irms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

Copyright © 2022, Texas Instruments Incorporated | 9 | ti.com/webench
# | Name | Value | Category | Description

32. Lin Pd | 54.435 mW | Power | Lin power dissipation
33. Lout Pd | 3.038 mW | Power | Lout power dissipation
34. Total Pd | 3.295 W | Power | Total Power Dissipation
35. Rsense Pd | 99.828 mW | Resistor | LED Current Rsns Power Dissipation
36. BOM Count | 19 | System
| | | Information | Total Design BOM count
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

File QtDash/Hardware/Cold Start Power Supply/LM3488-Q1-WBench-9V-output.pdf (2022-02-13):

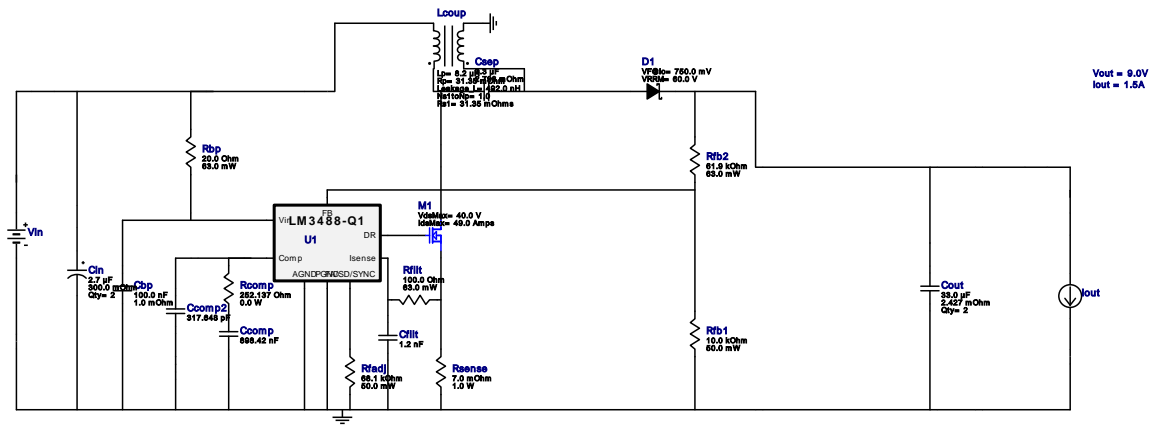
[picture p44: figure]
Rfb2 61.9 kOhm 63.0 m W; Cfilt 1.2 nF; Csep 3.3 µF 2.798 m Ohm; Rfb1 10.0 kOhm 50.0 m W; Com p; Isense; AGNDPGND; FA/SD/SYNC; Vin; Cbp 100.0 nF 1.0 m Ohm; Lcoup; Lp= 8.2 µH Rp= 31.35 m Ohm; Leakage_L=; Ns1toNp= 1.0 Rs1= 31.35 m Ohm s; Rsense 7.0 m Ohm 1.0 W; Ccom p2 317.648 pF; D1 VF@Io= 750.0 m V VRRM= 60.0 V; Cin 2.7 µF 300.0 m Ohm Qty= 2; Rfilt 100.0 Ohm; M1 VdsMax= 40.0 V IdsMax= 49.0 Am ps; Ccom p 898.42 nF; Rcom p 252.137 Ohm 0.0 W; Vout = 9.0V Iout = 1.5A; Cout 33.0 µF; 2.427 m Ohm Qty= 2; Rfadj 68.1 kOhm; Rbp 20.0 Ohm 63.0 m W; Iout

Copyright © 2022, Texas Instruments Incorporated | 1 | ti.com/webench

WEBENCH®
Design Report LM3488QMM/NOPB : LM3488QMM/NOPB 3V-22V to 12.00V @ 1A February 9, 2022 19:40:04 GMT-06:00

## WEBENCH ® Design Report

Design : 4 LM3488QMM/NOPB
LM3488QMM/NOPB 3V-22V to 12.00V @ 1A

VinMin = 3.0V
VinMax = 24.0V
Vout = 9.0V
Iout = 1.5A

Device = LM3488QMM/NOPB
Topology = SEPIC
Created = 2022-02-09 19:24:12.025 BOM Cost = NA
BOM Count = 20
Total Pd = 4.14W
1. Please note that Loop/ stability model has not been implemented for this device.The opertating values and charts related to loop model are disabled.

## Electrical BOM

Name | Manufacturer | Part Number | Properties | Qty Price | Footprint
Cbp | Yageo | CC0805KRX7R9BB104 (http://www.yageo.com/documents/recent/UPY%2DGPHC%5FX7R%5F6.3V%2Dto%2D50V%5F7.pdf) Series= X7R | Cap= 100.0 nF ESR= 1.0 mOhm VDC= 50.0 V IRMS= 0.0 A
1 | $0.02
| | | | | 0805 7 mm²
Ccomp | CUSTOM | CUSTOM Series= ?

Cap= 898.42 nF
VDC= 0.0 V
IRMS= 0.0 A

1 NA
CUSTOM 0 mm²
Ccomp2 | CUSTOM | CUSTOM Series= ?

Cap= 317.648 pF
VDC= 0.0 V
IRMS= 0.0 A

1 NA
CUSTOM 0 mm²
Cfilt | Samsung Electro- Mechanics | CL21C122JBFNNNE (http://www.samsungsem.com/servlet/FileDownload?type%3Dspec%26file%3DCL21C122JBFNNNE.pdf) Series= C0G/NP0

Cap= 1.2 nF
VDC= 50.0 V
IRMS= 0.0 A

1 $0.02
0805 7 mm²
Cin | Panasonic | 35TQC2R7MYF Series= TQC

Cap= 2.7 uF
ESR= 300.0 mOhm
VDC= 35.0 V
IRMS= 800.0 mA

2 $0.46

3528-21 17 mm²

Cout | TDK | C4532X5R1C336M250KA Series= X5R

Cap= 33.0 uF
ESR= 2.427 mOhm
VDC= 16.0 V
IRMS= 4.9234 A

2 $0.41

1812_280 23 mm²

Csep | TDK | CGA4J1X7R1V335K125AC (https://product.tdk.com/en/search/capacitor/ceramic/mlcc/info?part%5Fno%3DCGA4J1X7R1V335K125AC) Series= X7R

Cap= 3.3 uF
ESR= 2.798 mOhm
VDC= 35.0 V
IRMS= 3.90156 A

1 $0.13
0805 7 mm²
D1 | Vishay-Semiconductor | SS36-E3/57T (http://www.vishay.com/docs/88751/88751.pdf) | VF@Io= 750.0 mV VRRM= 60.0 V
1 | $0.20

SMC 83 mm²

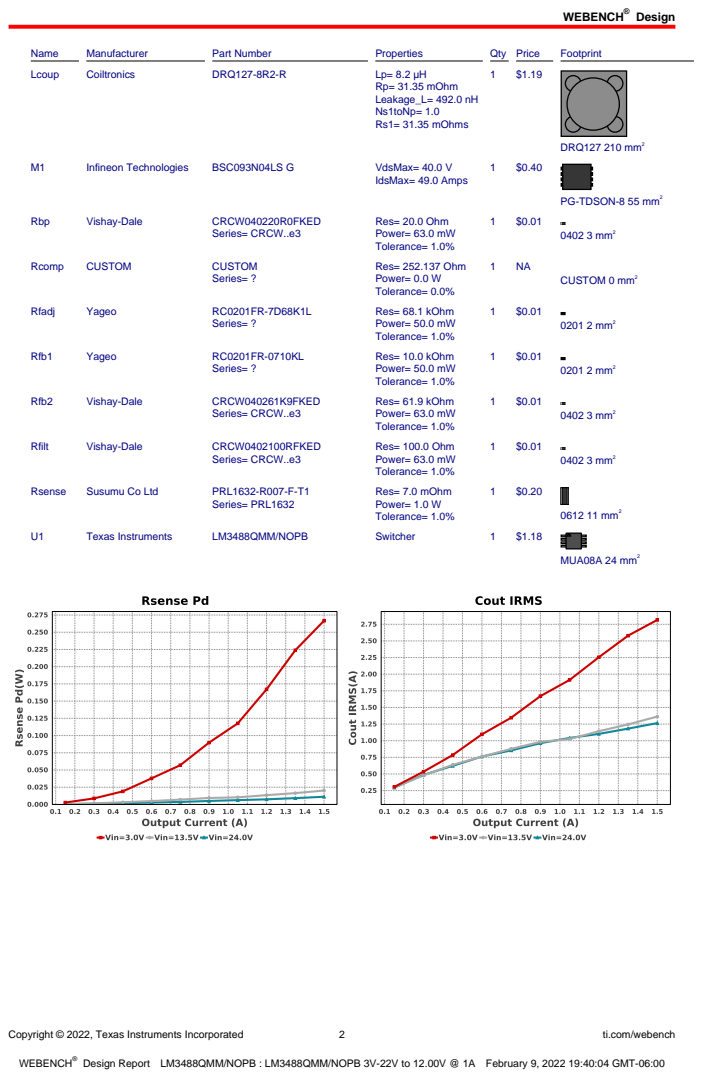
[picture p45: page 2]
Design; Copyright © 2022, Texas Instruments Incorporated; ti.com/webench; Name; Manufacturer; Part Number; Properties; Qty Price; Footprint; Lcoup; Coiltronics; DRQ127-8R2-R; Rp= 31.35 mOhm Leakage_L= 492.0 nH Ns1toNp= 1.0 Rs1= 31.35 mOhms; DRQ127 210 mm²; Infineon Technologies; BSC093N04LS G; VdsMax= 40.0 V; IdsMax= 49.0 Amps; Rbp; Vishay-Dale; CRCW040220R0FKED; Series= CRCW..e3; Res= 20.0 Ohm Power= 63.0 mW Tolerance= 1.0%; 0402 3 mm²; Rcomp; CUSTOM; Series= ?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

PG-TDSON-8 55 mm²

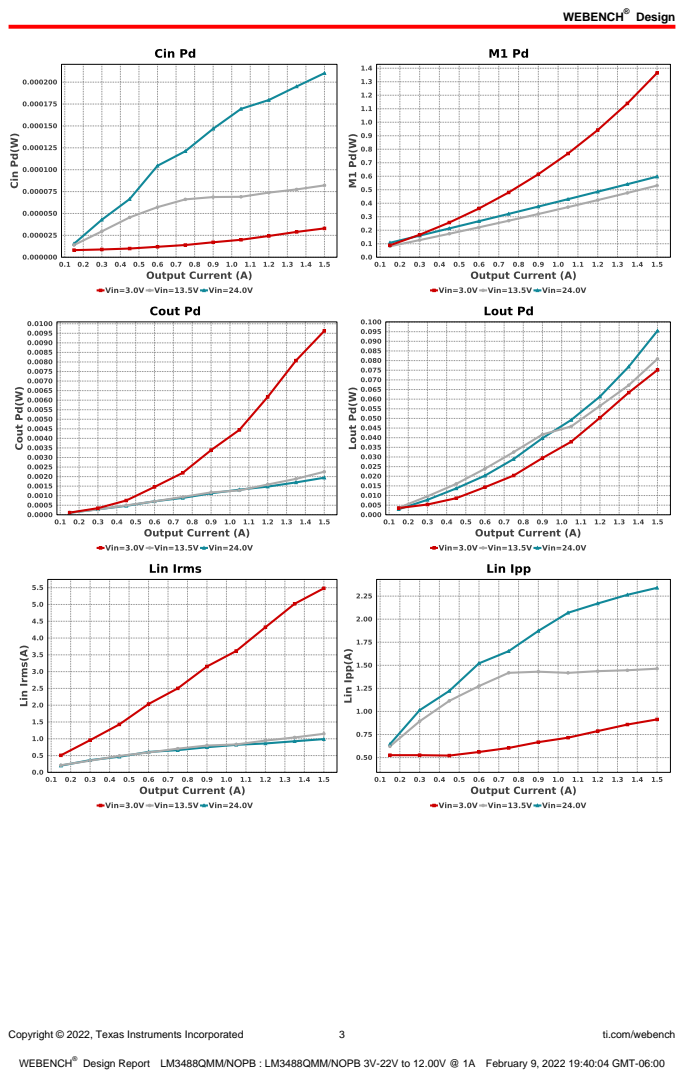
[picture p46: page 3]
Copyright © 2022, Texas Instruments Incorporated; ti.com/webench

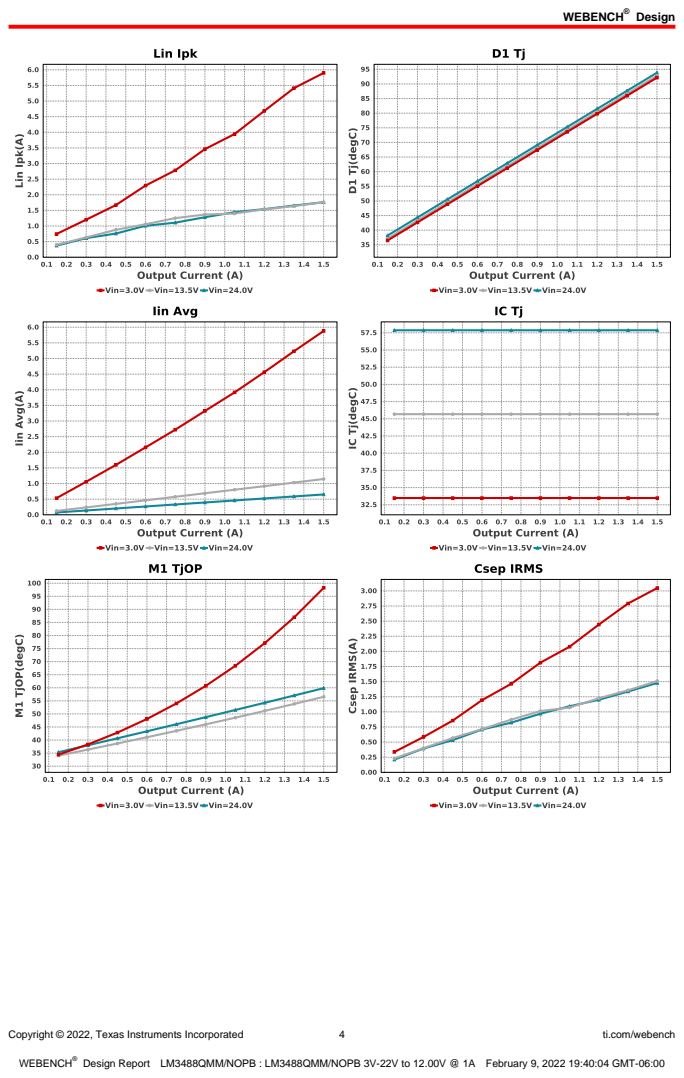
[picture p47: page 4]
Copyright © 2022, Texas Instruments Incorporated; ti.com/webench

Copyright © 2022, Texas Instruments Incorporated; ti.com/webench

Copyright © 2022, Texas Instruments Incorporated; ti.com/webench

Copyright © 2022, Texas Instruments Incorporated; ti.com/webench

Copyright © 2022, Texas Instruments Incorporated; ti.com/webench; Operating Values; Name; Value; Category; Description; 1. Cin IRMS; Capacitor; Input capacitor RMS ripple current; 2. Cin Pd; Input capacitor power dissipation; 3. Cout IRMS; Output capacitor RMS ripple current; 4. Cout Pd; Output capacitor power dissipation; 5. Csep IRMS; SEPIC capacitor RMS ripple current; 6. Csep Pd; SEPIC capacitor power dissipation; 7. D1 Irms; Current; D1 Irms; 8. Lin Ipk; Lin peak current; 9. Lin Irms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

Copyright © 2022, Texas Instruments Incorporated | 9 | ti.com/webench
# | Name | Value | Category | Description

32. Lin Pd | 946.344 mW | Power | Lin power dissipation
33. Lout Pd | 74.995 mW | Power | Lout power dissipation
34. Total Pd | 4.144 W | Power | Total Power Dissipation
35. Rsense Pd | 266.72 mW | Resistor | LED Current Rsns Power Dissipation
36. BOM Count | 20 | System
| | | Information | Total Design BOM count
37. Duty Cycle | 79.0 % | System
| | | Information | Duty cycle
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

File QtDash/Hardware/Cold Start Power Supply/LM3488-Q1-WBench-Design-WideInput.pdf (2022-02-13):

Cin 2.7 µF 300.0 m Ohm; Qty= 3; Cbp; 100.0 nF 1.0 m Ohm; Vout = 5.1V Iout = 3.0A; Cout 100.0 µF; 2.838 m Ohm Qty= 2; Rfadj 78.7 kOhm; M1 VdsMax= 40.0 V IdsMax= 73.0 Am ps; Rfb1 10.0 kOhm 50.0 m W; D1 VF@Io= 770.0 m V VRRM= 100.0 V; PGND; Vin; Com p; AGND; Isense; Ccom p 710.67 nF; Rcom p 270.072 Ohm 0.0 W; Rfb2 30.5 kOhm 125.0 m W; Ccom p2 1.05083 nF; Rbp 20.0 Ohm 63.0 m W; Lcoup; Lp= 4.7 µH Rp= 18.35 m Ohm; Leakage_L=; Ns1toNp= 1.0 Rs1= 18.35 m Ohm s; Cfilt 1.5 nF; Rfilt 100.0 Ohm; Csep 4.7 µF 3.728 m Ohm Qty= 2; Rsense 6.0 m Ohm 1.0 W; Iout

Copyright © 2022, Texas Instruments Incorporated | 1 | ti.com/webench

WEBENCH®
Design Report LM3488MM/NOPB : LM3488MM/NOPB 3V-24V to 5.10V @ 3A February 9, 2022 14:55:47 GMT-06:00

## WEBENCH ® Design Report

Design : 2 LM3488MM/NOPB
LM3488MM/NOPB 3V-24V to 5.10V @ 3A

VinMin = 3.0V
VinMax = 24.0V
Vout = 5.1V
Iout = 3.0A

Device = LM3488MM/NOPB
Topology = SEPIC
Created = 2022-02-09 14:53:52.190 BOM Cost = NA
BOM Count = 22
Total Pd = 5.67W
1. Please note that Loop/ stability model has not been implemented for this device.The opertating values and charts related to loop model are disabled.

## Electrical BOM

Name | Manufacturer | Part Number | Properties | Qty Price | Footprint
Cbp | Yageo | CC0805KRX7R9BB104 (http://www.yageo.com/documents/recent/UPY%2DGPHC%5FX7R%5F6.3V%2Dto%2D50V%5F7.pdf) Series= X7R | Cap= 100.0 nF ESR= 1.0 mOhm VDC= 50.0 V IRMS= 0.0 A
1 | $0.02
| | | | | 0805 7 mm²
Ccomp | CUSTOM | CUSTOM Series= ?

Cap= 710.67 nF
VDC= 0.0 V
IRMS= 0.0 A

1 NA
CUSTOM 0 mm²
Ccomp2 | CUSTOM | CUSTOM Series= ?

Cap= 1.05083 nF
VDC= 0.0 V
IRMS= 0.0 A

1 NA
CUSTOM 0 mm²
Cfilt | TDK | C2012C0G1H152J060AA (http://product.tdk.com/capacitor/mlcc/en/documents/mlcc%5Fcommercial%5Fgeneral%5Fen.pdf) Series= C0G/NP0

Cap= 1.5 nF
VDC= 50.0 V
IRMS= 0.0 A

1 $0.02
0805 7 mm²
Cin | Panasonic | 35TQC2R7MYF Series= TQC

Cap= 2.7 uF
ESR= 300.0 mOhm
VDC= 35.0 V
IRMS= 800.0 mA

3 $0.46

3528-21 17 mm²

Cout | TDK | C3216X5R1A107M160AC Series= X5R

Cap= 100.0 uF
ESR= 2.838 mOhm
VDC= 10.0 V
IRMS= 4.3069 A

2 $0.50
1206_190 11 mm²
Csep | TDK | C1608X5R1V475K080AC Series= X5R

Cap= 4.7 uF
ESR= 3.728 mOhm
VDC= 35.0 V
IRMS= 2.69359 A

2 $0.10
0603 5 mm²
D1 | Vishay-Semiconductor | 50WQ10FNPBF (http://www.vishay.com/docs/94235/50wq10fn.pdf) | VF@Io= 770.0 mV VRRM= 100.0 V
1 | $0.80

DPAK 102 mm²

Design; Copyright © 2022, Texas Instruments Incorporated; ti.com/webench; Name; Manufacturer; Part Number; Properties; Qty Price; Footprint; Lcoup; Coiltronics; DRQ127-4R7-R; Rp= 18.35 mOhm Leakage_L= 282.0 nH Ns1toNp= 1.0 Rs1= 18.35 mOhms; DRQ127 210 mm²; Infineon Technologies; BSC059N04LS G; VdsMax= 40.0 V; IdsMax= 73.0 Amps; Rbp; Vishay-Dale; CRCW040220R0FKED; Series= CRCW..e3; Res= 20.0 Ohm Power= 63.0 mW Tolerance= 1.0%; 0402 3 mm²; Rcomp; CUSTOM; Series= ?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

PG-TDSON-8 55 mm²

Copyright © 2022, Texas Instruments Incorporated; ti.com/webench

Copyright © 2022, Texas Instruments Incorporated; ti.com/webench

Copyright © 2022, Texas Instruments Incorporated; ti.com/webench

Copyright © 2022, Texas Instruments Incorporated; ti.com/webench

Copyright © 2022, Texas Instruments Incorporated; ti.com/webench

Copyright © 2022, Texas Instruments Incorporated; ti.com/webench; Operating Values; Name; Value; Category; Description; 1. Cin IRMS; Capacitor; Input capacitor RMS ripple current; 2. Cin Pd; Input capacitor power dissipation; 3. Cout IRMS; Output capacitor RMS ripple current; 4. Cout Pd; Output capacitor power dissipation; 5. Csep IRMS; SEPIC capacitor RMS ripple current; 6. Csep Pd; SEPIC capacitor power dissipation; 7. D1 Irms; Current; D1 Irms; 8. Lin Ipk; Lin peak current; 9. Lin Irms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

Copyright © 2022, Texas Instruments Incorporated | 9 | ti.com/webench
# | Name | Value | Category | Description

32. Lin Pd | 798.741 mW | Power | Lin power dissipation
33. Lout Pd | 172.822 mW | Power | Lout power dissipation
34. Total Pd | 5.675 W | Power | Total Power Dissipation
35. Rsense Pd | 376.042 mW | Resistor | LED Current Rsns Power Dissipation
36. BOM Count | 22 | System
| | | Information | Total Design BOM count
37. Duty Cycle | 69.0 % | System
| | | Information | Duty cycle
38. Efficiency | 72.945 % | System
| | | Information | Steady state efficiency
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

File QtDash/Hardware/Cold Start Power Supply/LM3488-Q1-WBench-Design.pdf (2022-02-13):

Rfb2 30.5 kOhm 125.0 m W; Cfilt 1.2 nF; Csep 1.0 µF 5.522 m Ohm Qty= 3; Rfb1 10.0 kOhm 50.0 m W; Com p; Isense; AGNDPGND; FA/SD/SYNC; Vin; Cbp 100.0 nF 1.0 m Ohm; Lcoup; Lp= 4.7 µH Rp= 18.35 m Ohm; Leakage_L=; Ns1toNp= 1.0 Rs1= 18.35 m Ohm s; Rsense 6.0 m Ohm 1.0 W; Ccom p2 974.59 pF; D1 VF@Io= 510.0 m V VRRM= 40.0 V; Cin 5.6 µF 100.0 m Ohm; Rfilt 100.0 Ohm; M1 VdsMax= 30.0 V IdsMax= 35.0 Am ps; Ccom p 1.28915 µF; Rcom p 138.118 Ohm 0.0 W; Vout = 5.1V Iout = 3.0A; Cout 47.0 µF; 2.864 m Ohm Qty= 3; Rfadj 68.1 kOhm; Rbp 20.0 Ohm 63.0 m W; Iout

Copyright © 2022, Texas Instruments Incorporated | 1 | ti.com/webench

WEBENCH®
Design Report LM3488QMM/NOPB : LM3488QMM/NOPB 3V-18V to 5.10V @ 3A February 9, 2022 13:31:38 GMT-06:00

## WEBENCH ® Design Report

Design : 1 LM3488QMM/NOPB
LM3488QMM/NOPB 3V-18V to 5.10V @ 3A

VinMin = 3.0V
VinMax = 18.0V
Vout = 5.1V
Iout = 3.0A

Device = LM3488QMM/NOPB
Topology = SEPIC
Created = 2022-02-09 13:27:11.585 BOM Cost = NA
BOM Count = 22
Total Pd = 4.61W
1. Please note that Loop/ stability model has not been implemented for this device.The opertating values and charts related to loop model are disabled.

## Electrical BOM

Name | Manufacturer | Part Number | Properties | Qty Price | Footprint
Cbp | Yageo | CC0805KRX7R9BB104 (http://www.yageo.com/documents/recent/UPY%2DGPHC%5FX7R%5F6.3V%2Dto%2D50V%5F7.pdf) Series= X7R | Cap= 100.0 nF ESR= 1.0 mOhm VDC= 50.0 V IRMS= 0.0 A
1 | $0.02
| | | | | 0805 7 mm²
Ccomp | CUSTOM | CUSTOM Series= ?

Cap= 1.28915 uF
VDC= 0.0 V
IRMS= 0.0 A

1 NA
CUSTOM 0 mm²
Ccomp2 | CUSTOM | CUSTOM Series= ?

Cap= 974.59 pF
VDC= 0.0 V
IRMS= 0.0 A

1 NA
CUSTOM 0 mm²
Cfilt | Samsung Electro- Mechanics | CL21C122JBFNNNE (http://www.samsungsem.com/servlet/FileDownload?type%3Dspec%26file%3DCL21C122JBFNNNE.pdf) Series= C0G/NP0

Cap= 1.2 nF
VDC= 50.0 V
IRMS= 0.0 A

1 $0.02
0805 7 mm²
Cin | Panasonic | 25TQC5R6M Series= TQC

Cap= 5.6 uF
ESR= 100.0 mOhm
VDC= 25.0 V
IRMS= 800.0 mA

1 $0.61

3528-21 17 mm²

Cout | MuRata | GRM32ER71A476KE15L (http://psearch.en.murata.com/capacitor/result/smd/?status%3Dall%26pid%3DGRM32ER71A476KE15L) Series= X7R

Cap= 47.0 uF
ESR= 2.864 mOhm
VDC= 10.0 V
IRMS= 4.8625 A

3 $0.68
1210_280 15 mm²
Csep | TDK | CGA3E1X7R1V105K080AC (https://product.tdk.com/en/search/capacitor/ceramic/mlcc/info?part%5Fno%3DCGA3E1X7R1V105K080AC) Series= X7R

Cap= 1.0 uF
ESR= 5.522 mOhm
VDC= 35.0 V
IRMS= 2.2162 A

3 $0.05
0603 5 mm²
D1 | Vishay-Semiconductor | 50WQ04FNPBF (http://www.vishay.com/docs/94233/50wq04fn.pdf) | VF@Io= 510.0 mV VRRM= 40.0 V
1 | $0.40

DPAK 102 mm²

Design; Copyright © 2022, Texas Instruments Incorporated; ti.com/webench; Name; Manufacturer; Part Number; Properties; Qty Price; Footprint; Lcoup; Coiltronics; DRQ127-4R7-R; Rp= 18.35 mOhm Leakage_L= 282.0 nH Ns1toNp= 1.0 Rs1= 18.35 mOhms; DRQ127 210 mm²; Texas Instruments; CSD17577Q3A; VdsMax= 30.0 V; IdsMax= 35.0 Amps; DNH0008A 18 mm²; Rbp; Vishay-Dale; CRCW040220R0FKED; Series= CRCW..e3; Res= 20.0 Ohm Power= 63.0 mW Tolerance= 1.0%; 0402 3 mm²; Rcomp; CUSTOM; Series= ?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

Copyright © 2022, Texas Instruments Incorporated; ti.com/webench

Copyright © 2022, Texas Instruments Incorporated; ti.com/webench

Copyright © 2022, Texas Instruments Incorporated; ti.com/webench

Copyright © 2022, Texas Instruments Incorporated; ti.com/webench

Copyright © 2022, Texas Instruments Incorporated; ti.com/webench

Copyright © 2022, Texas Instruments Incorporated; ti.com/webench; Operating Values; Name; Value; Category; Description; 1. Cin IRMS; Capacitor; Input capacitor RMS ripple current; 2. Cin Pd; Input capacitor power dissipation; 3. Cout IRMS; Output capacitor RMS ripple current; 4. Cout Pd; Output capacitor power dissipation; 5. Csep IRMS; SEPIC capacitor RMS ripple current; 6. Csep Pd; SEPIC capacitor power dissipation; 7. D1 Irms; Current; D1 Irms; 8. Lin Ipk; Lin peak current; 9. Lin Irms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

Copyright © 2022, Texas Instruments Incorporated | 9 | ti.com/webench
# | Name | Value | Category | Description

32. Lin Pd | 734.284 mW | Power | Lin power dissipation
33. Lout Pd | 225.046 mW | Power | Lout power dissipation
34. Total Pd | 4.61 W | Power | Total Power Dissipation
35. Rsense Pd | 326.412 mW | Resistor | LED Current Rsns Power Dissipation
36. BOM Count | 22 | System
| | | Information | Total Design BOM count
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

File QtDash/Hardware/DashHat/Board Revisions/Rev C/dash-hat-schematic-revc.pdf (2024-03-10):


GND-ISO

Connect output from speedo/vss
conditioning circuit to here.

Sensor/Analog Input ADC

GND
Dash Light Inputs (Isolated)

3/4/24 8:13 PM f=0.47 /home/whitfijs/git/Volvo240-DigitalDash/QtDash/Hardware/DashHat/dash-hat.sch (Sheet: 1/1)


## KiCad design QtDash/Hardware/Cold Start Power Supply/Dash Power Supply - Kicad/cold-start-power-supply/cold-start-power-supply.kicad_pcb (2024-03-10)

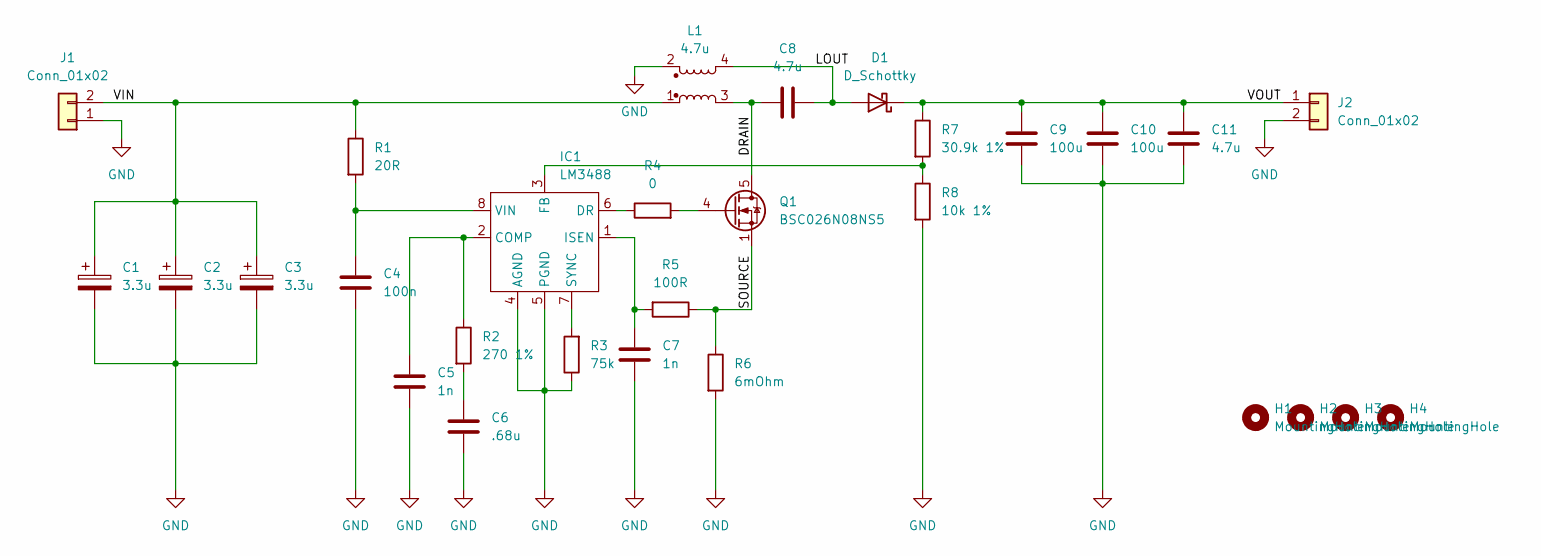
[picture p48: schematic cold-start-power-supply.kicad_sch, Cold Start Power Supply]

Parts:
C1, C2, C3: 3.3u; CP_Elec_5x5.3
C4: 100n; C_0603_1608Metric
C5, C7: 1n; C_0603_1608Metric
C6: .68u; C_0603_1608Metric
C8: 4.7u; C_0603_1608Metric
C9, C10: 100u; C_1210_3225Metric
C11: 4.7u; C_1210_3225Metric
D1: D_Schottky; TO-263-2_TabPin1
H1, H2, H3, H4: MountingHole; MountingHole_2.2mm_M2_Pad_Via
IC1: LM3488; MSOP-8_3x3mm_P0.65mm
J1, J2: Conn_01x02; SolderWire-1sqmm_1x02_P5.4mm_D1.4mm_OD2.7mm
L1: 4.7u; DRQ127
Q1: BSC026N08NS5; TDSON-8-1
R1: 20R; R_0603_1608Metric
R2: 270 1%; R_0603_1608Metric
R3: 75k; R_0603_1608Metric
R4: 0; R_0603_1608Metric
R5: 100R; R_0603_1608Metric
R6: 6mOhm; R3216
R7: 30.9k 1%; R_1206_3216Metric
R8: 10k 1%; R_0603_1608Metric

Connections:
/DRAIN: C8.2, L1.3, Q1.5 (D)
/LOUT: C8.1, D1.2 (A), L1.4
/SOURCE: Q1.1 (S), Q1.2 (S), Q1.3 (S), R5.1, R6.1
/VIN: C1.1, C2.1, C3.1, J1.2, L1.1, R1.1
/VOUT: C9.1, C10.1, C11.1, D1.1 (K), J2.1, R7.1
GND: C1.2, C2.2, C3.2, C4.2, C5.2, C6.2, C7.2, C9.2, C10.2, C11.2, IC1.4 (AGND), IC1.5 (PGND), J1.1, J2.2, L1.2, R3.1, R6.2, R8.2
unnamed: C4.1, IC1.8 (VIN), R1.2
unnamed: C5.1, IC1.2 (COMP), R2.1
unnamed: C6.1, R2.2
unnamed: C7.1, IC1.1 (ISEN), R5.2
unnamed: IC1.3 (FB), R7.2, R8.1
unnamed: IC1.6 (DR), R4.1
unnamed: IC1.7 (SYNC), R3.2
unnamed: Q1.4 (G), R4.2

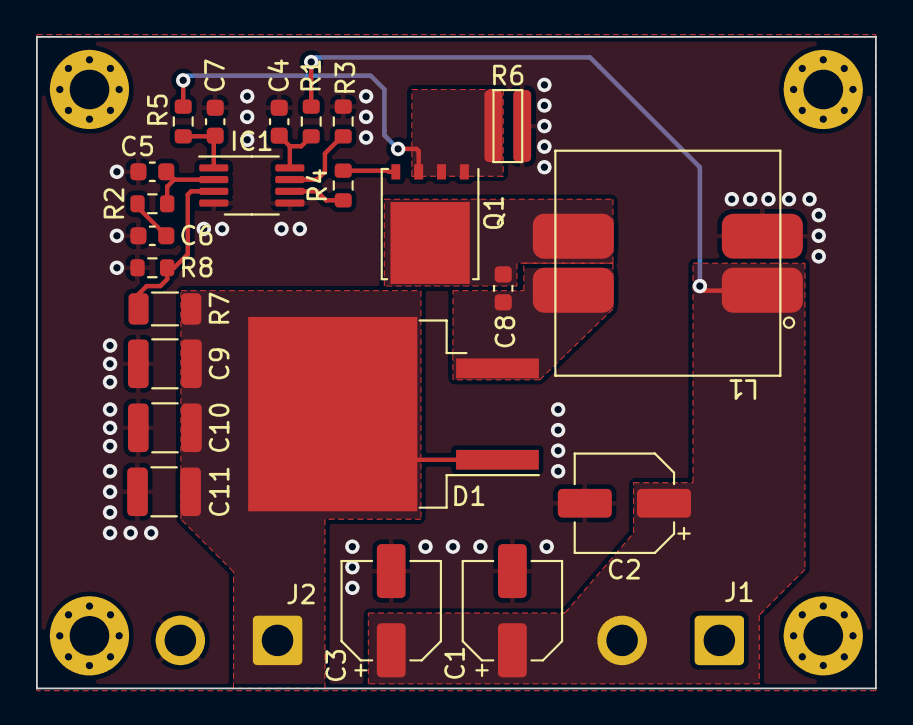
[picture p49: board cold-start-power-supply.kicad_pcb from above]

Board: 2 copper layers, 46.6 x 36.2 mm, 29 parts (0 on the bottom side), 14 nets.

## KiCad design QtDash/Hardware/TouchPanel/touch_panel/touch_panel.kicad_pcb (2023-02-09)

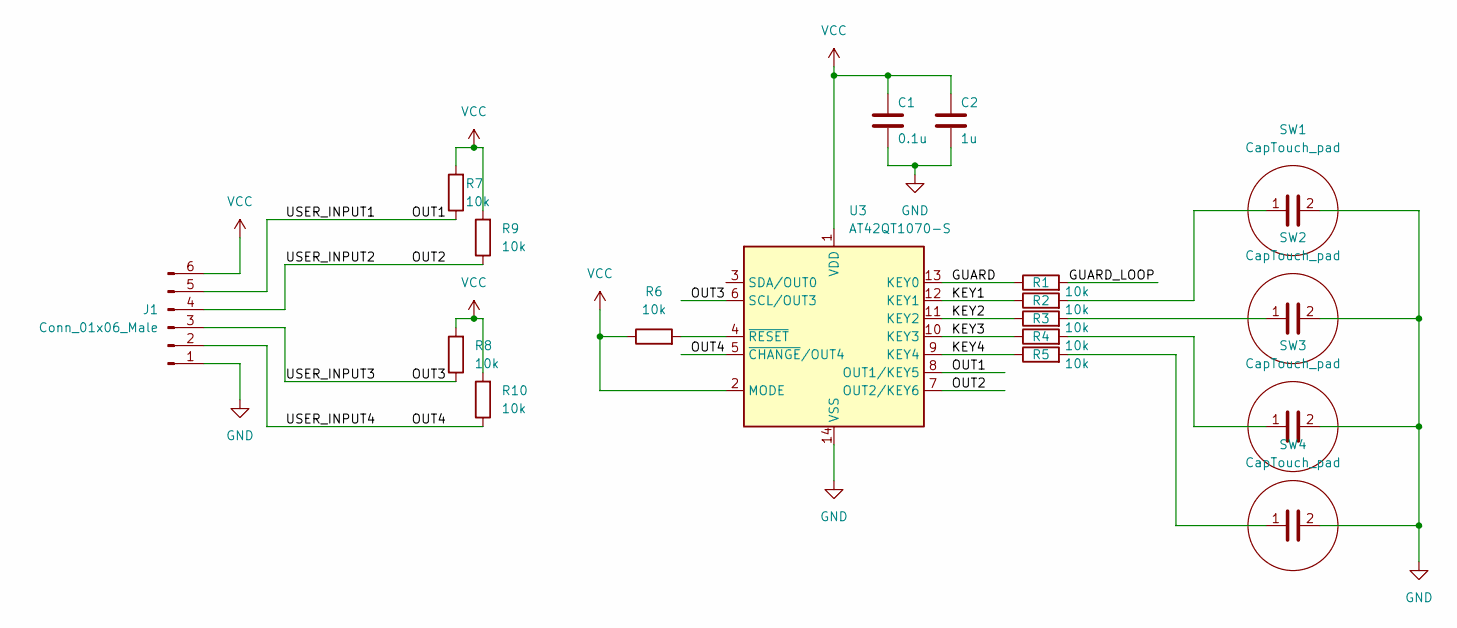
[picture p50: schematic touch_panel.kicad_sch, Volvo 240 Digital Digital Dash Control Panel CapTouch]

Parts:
C1: 0.1u; C_0603_1608Metric_Pad1.08x0.95mm_HandSolder
C2: 1u; C_0603_1608Metric_Pad1.08x0.95mm_HandSolder
J1: Conn_01x06_Male; JST_PH_S6B-PH-SM4-TB_1x06-1MP_P2.00mm_Horizontal
R1, R2, R3, R4, R5, R6, R7, R8, R9, R10: 10k; R_0603_1608Metric_Pad0.98x0.95mm_HandSolder
SW1, SW2, SW3, SW4: CapTouch_pad; CAPTOUCH_12.5
U3: AT42QT1070-S; SOIC-14_3.9x8.7mm_P1.27mm

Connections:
/GUARD: R1.1, U3.13 (KEY0)
/GUARD_LOOP: R1.2
/KEY1: R2.1, U3.12 (KEY1)
/KEY2: R3.1, U3.11 (KEY2)
/KEY3: R4.1, U3.10 (KEY3)
/KEY4: R5.1, U3.9 (KEY4)
/OUT1: J1.5, R7.1, U3.8 (OUT1/KEY5)
/OUT2: J1.4, R9.1, U3.7 (OUT2/KEY6)
/OUT3: J1.3, R8.1, U3.6 (SCL/OUT3)
/OUT4: J1.2, R10.1, U3.5 (~CHANGE/OUT4)
GND: C1.2, C2.2, J1.1, SW1.2, SW2.2, SW3.2, SW4.2, U3.14 (VSS)
unnamed: R2.2, SW1.1
unnamed: R3.2, SW2.1
unnamed: R4.2, SW3.1
unnamed: R5.2, SW4.1
unnamed: R6.2, U3.4 (~RESET)
VCC: C1.1, C2.1, J1.6, R6.1, R7.2, R8.2, R9.2, R10.2, U3.1 (VDD), U3.2 (MODE)

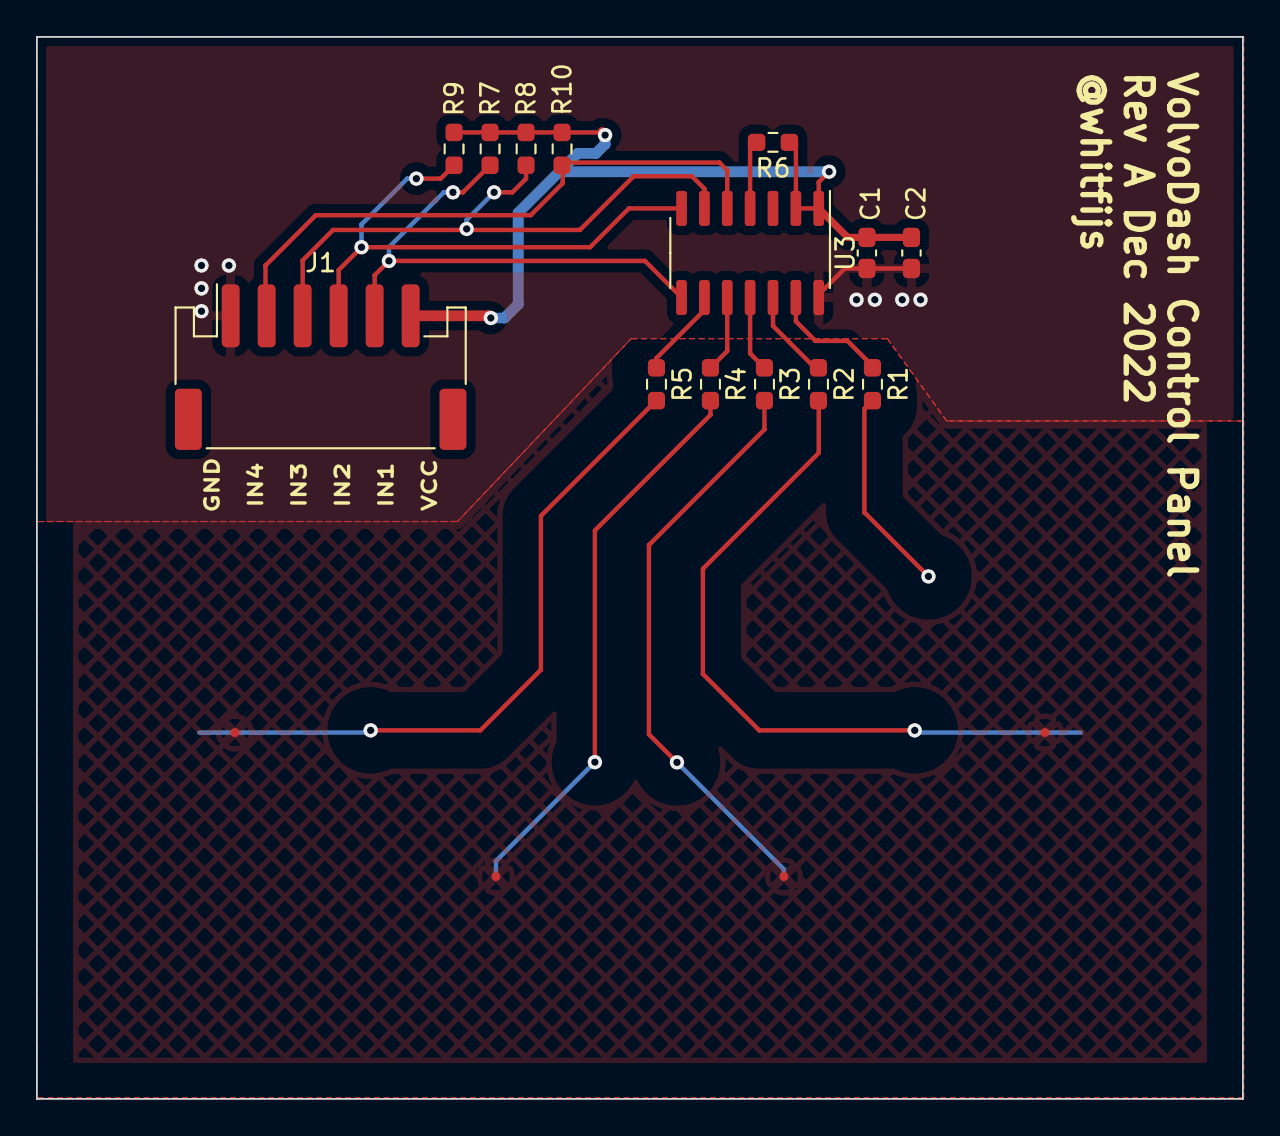
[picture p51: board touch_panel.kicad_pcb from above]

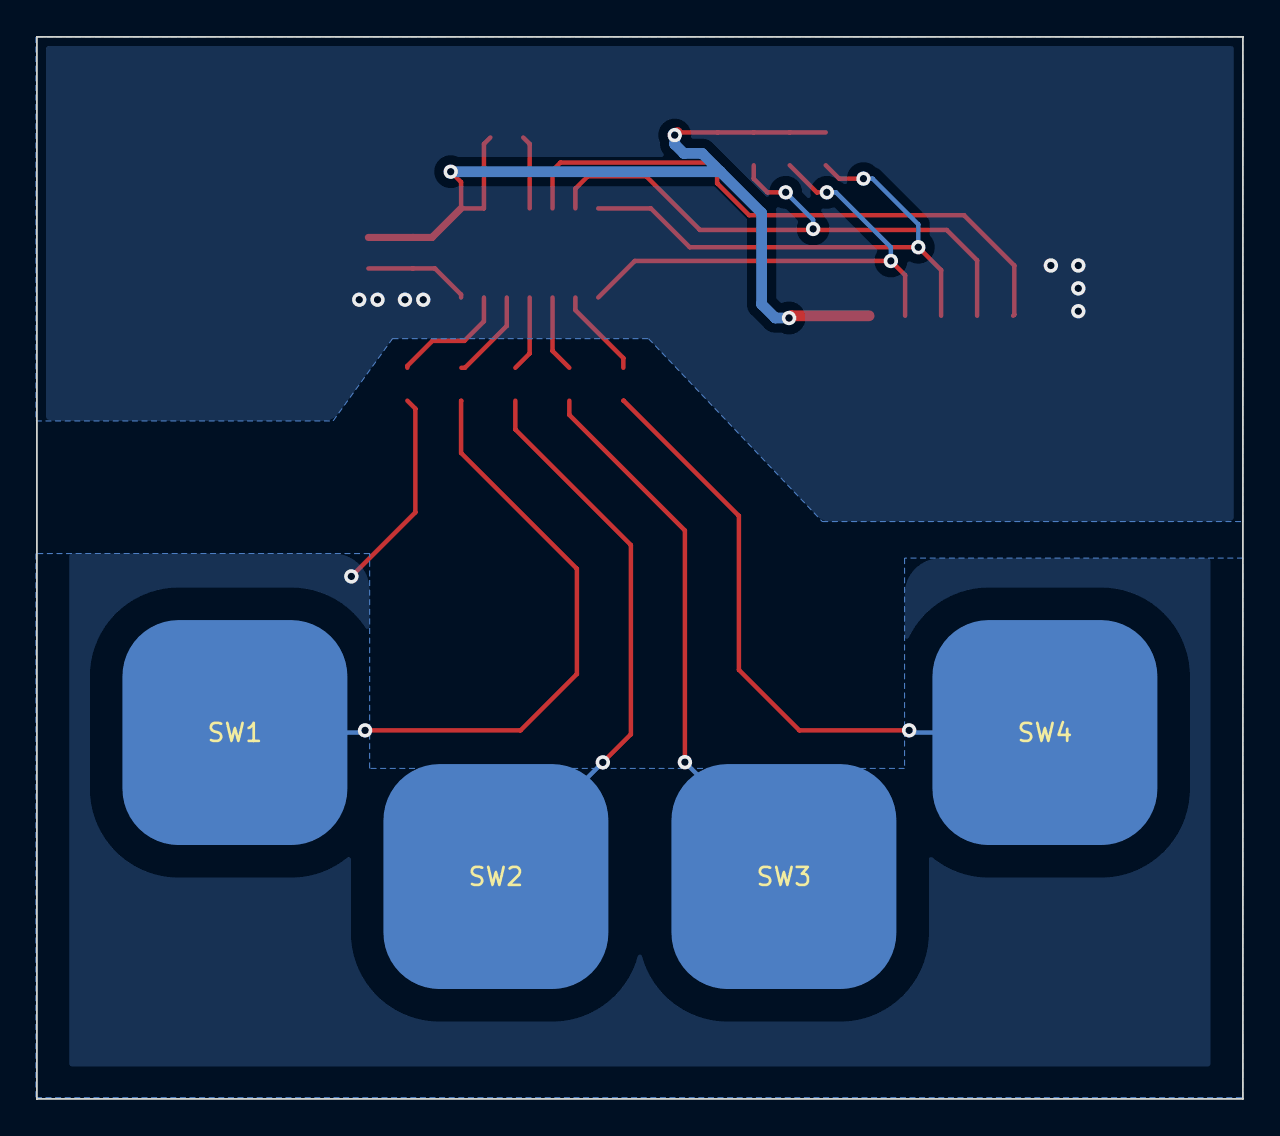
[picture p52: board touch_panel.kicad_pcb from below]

Board: 2 copper layers, 67.0 x 59.0 mm, 18 parts (4 on the bottom side), 16 nets.

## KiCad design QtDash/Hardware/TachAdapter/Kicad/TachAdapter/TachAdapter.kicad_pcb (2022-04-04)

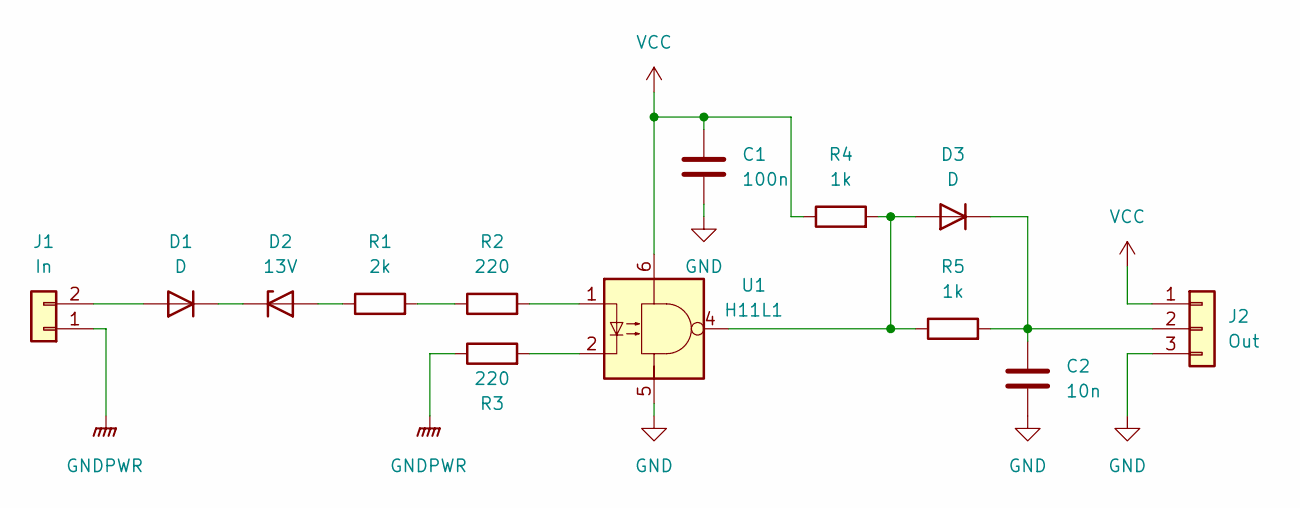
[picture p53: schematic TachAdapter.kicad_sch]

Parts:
C1: 100n; C_0603_1608Metric
C2: 10n; C_0603_1608Metric
D1, D3: D; D_SMA
D2: 13V; D_SMB
J1: In; SolderWire-1.5sqmm_1x02_P6mm_D1.7mm_OD3mm
J2: Out; SolderWire-1.5sqmm_1x03_P6mm_D1.7mm_OD3mm
R1: 2k; R_1206_3216Metric
R2, R3: 220; R_1206_3216Metric
R4, R5: 1k; R_0603_1608Metric
U1: H11L1; 6-SMD

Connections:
GND: C1.2, C2.2, J2.3, U1.5
GNDPWR: J1.1, R3.1
unnamed: C2.1, D3.1 (K), J2.2, R5.2
unnamed: D1.1 (K), D2.1 (K)
unnamed: D1.2 (A), J1.2
unnamed: D2.2 (A), R1.1
unnamed: D3.2 (A), R4.2, R5.1, U1.4
unnamed: R1.2, R2.1
unnamed: R2.2, U1.1
unnamed: R3.2, U1.2
VCC: C1.1, J2.1, R4.1, U1.6

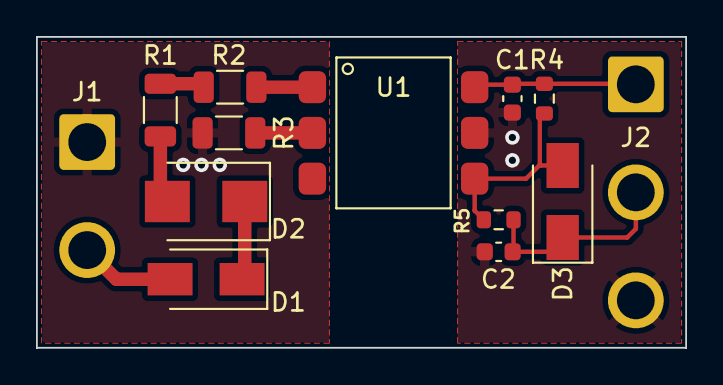
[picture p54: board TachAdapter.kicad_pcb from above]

Board: 2 copper layers, 36.1 x 17.3 mm, 13 parts (0 on the bottom side), 11 nets.

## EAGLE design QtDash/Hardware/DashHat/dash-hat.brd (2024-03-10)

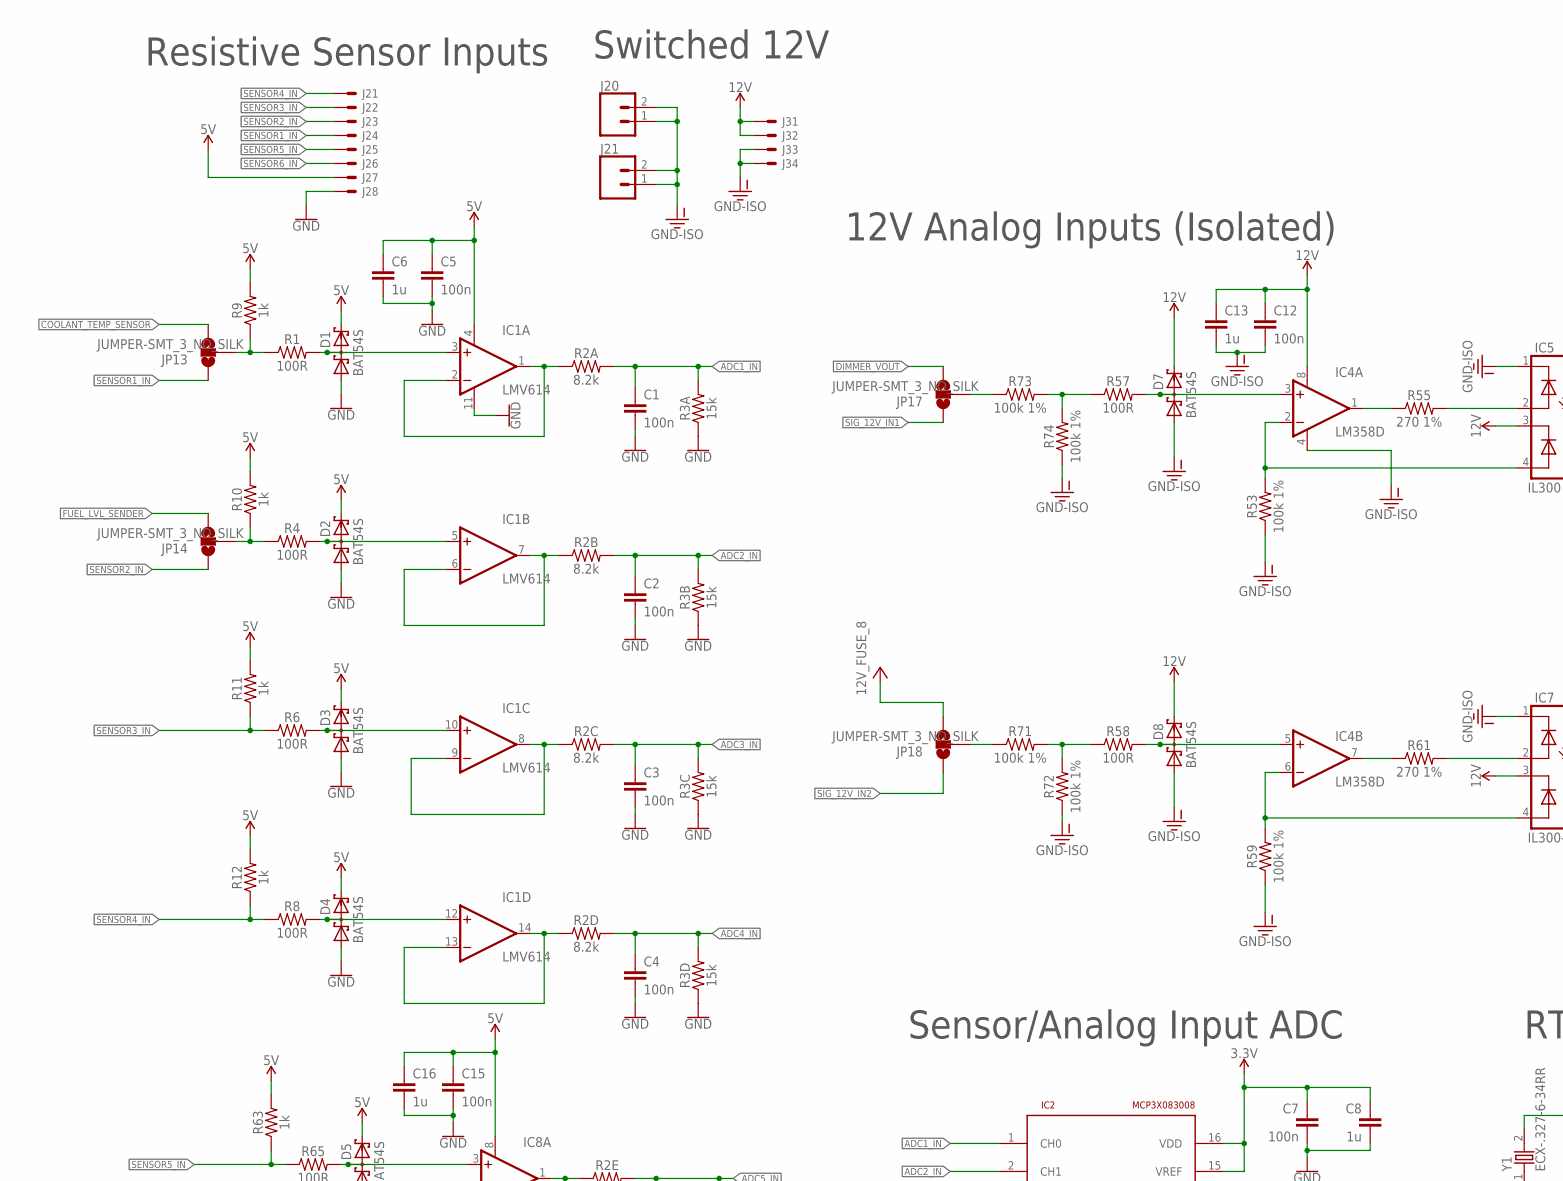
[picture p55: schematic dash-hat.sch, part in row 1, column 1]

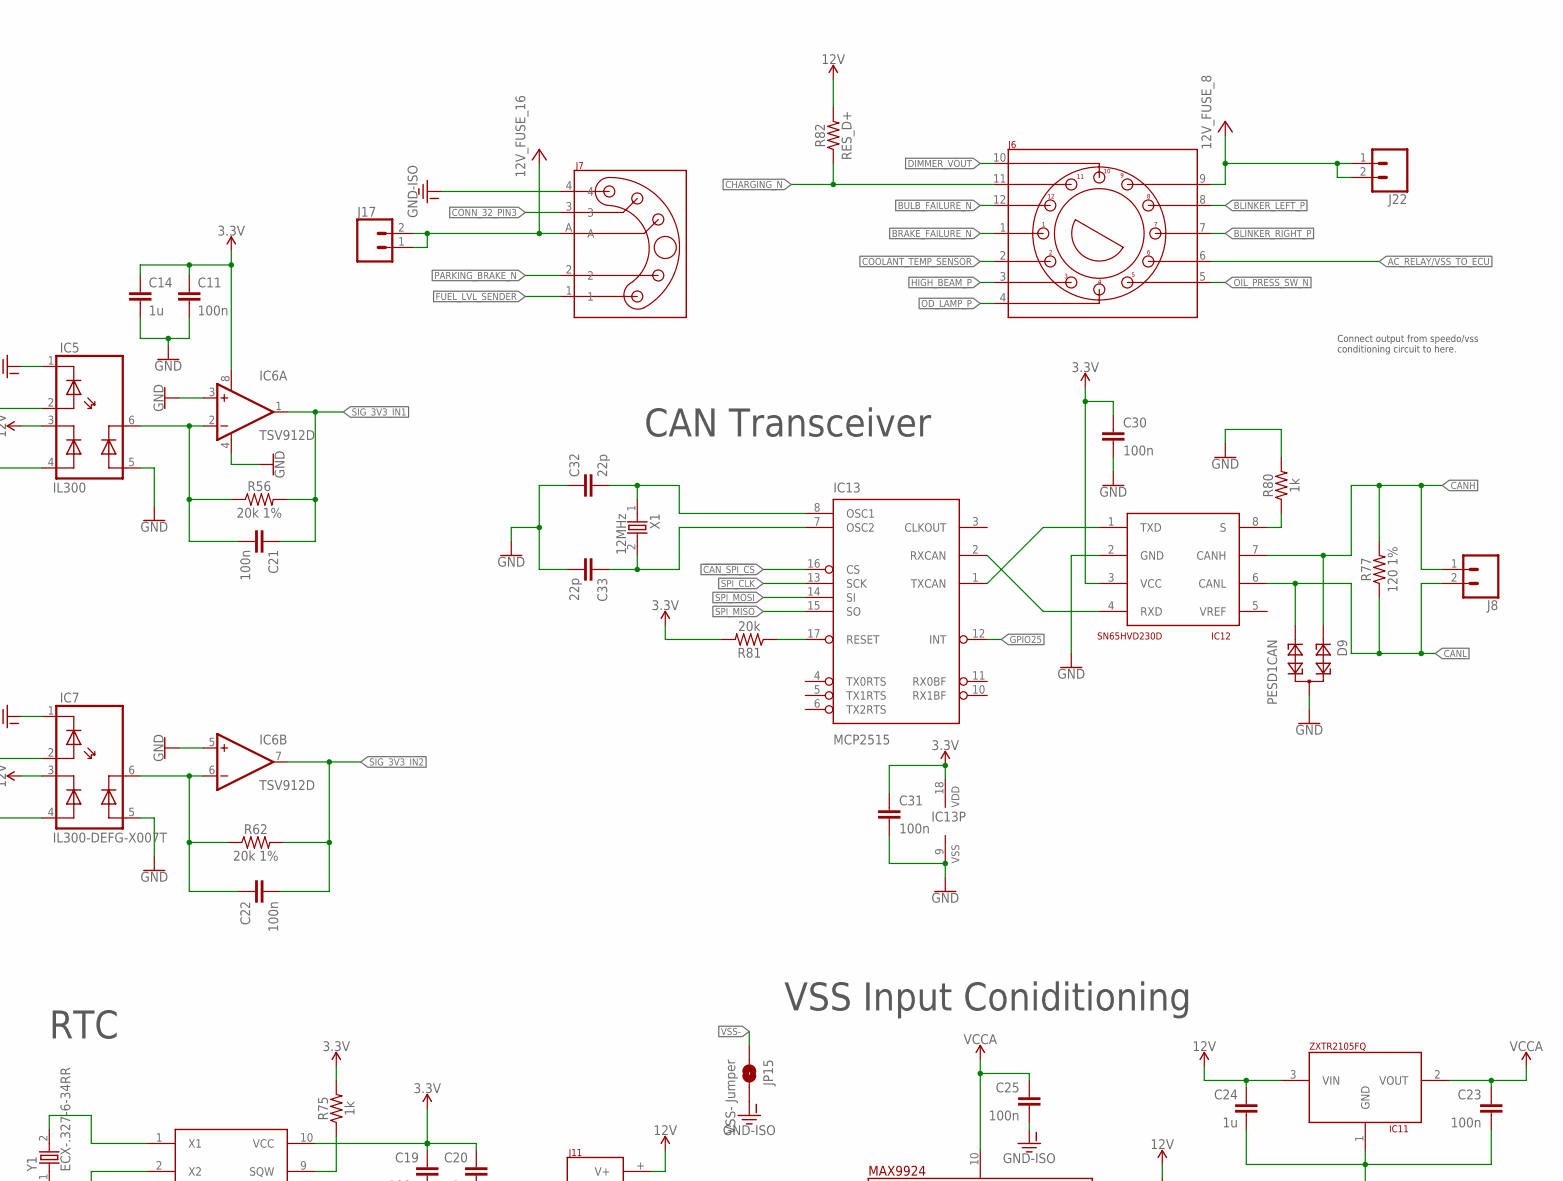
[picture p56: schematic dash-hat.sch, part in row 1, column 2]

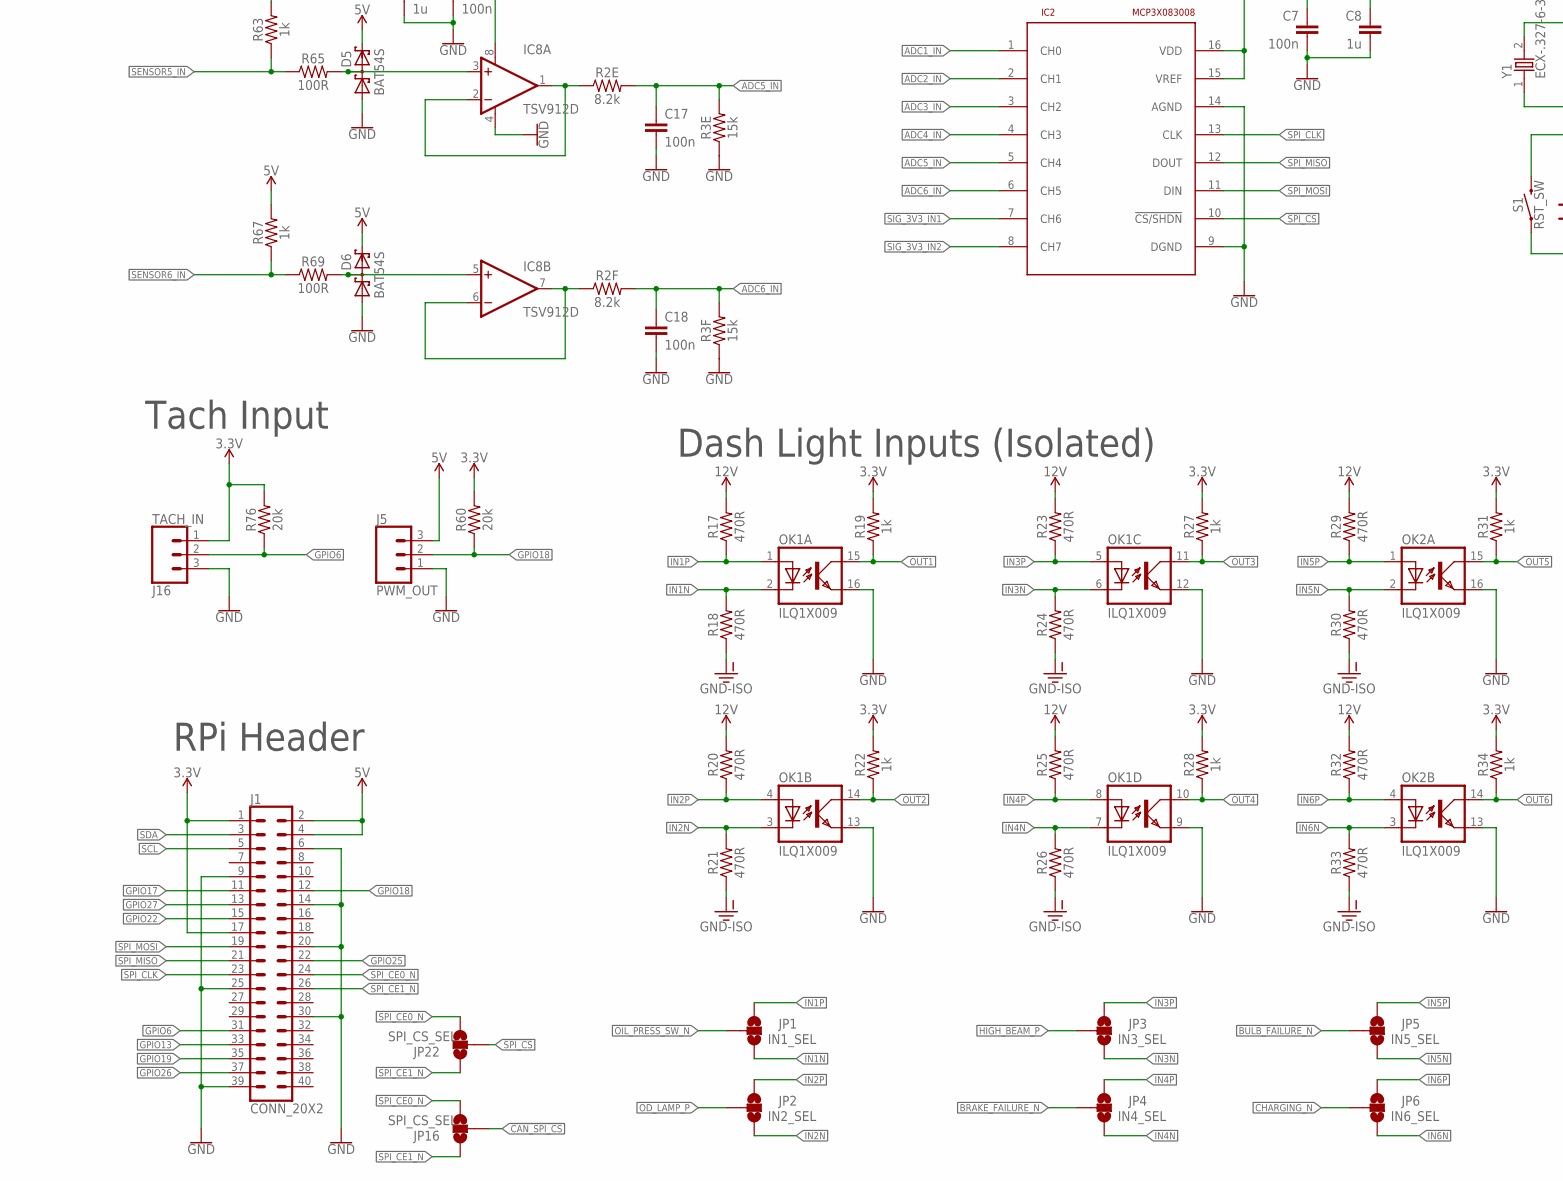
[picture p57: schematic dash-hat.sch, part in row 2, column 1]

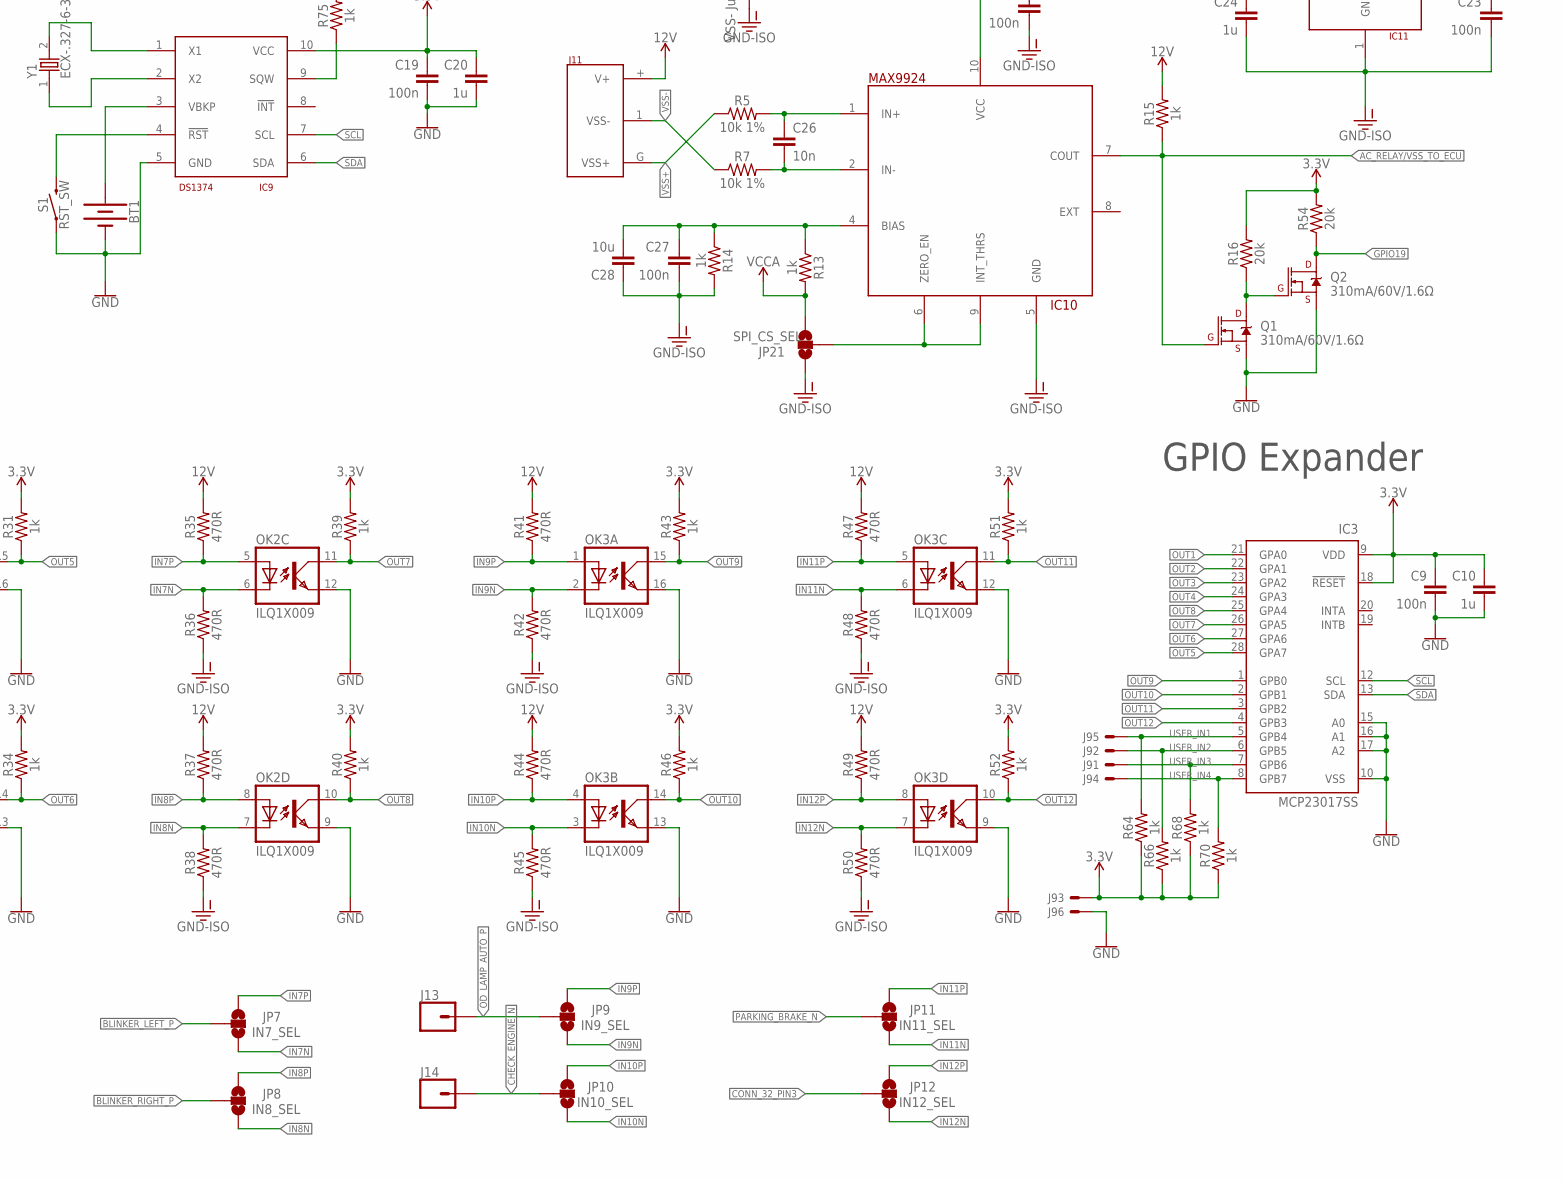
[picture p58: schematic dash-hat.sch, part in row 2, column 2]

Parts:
BT1: BATTERY-12MM_SMD; BATTCON_12MM
C1, C2, C3, C4, C5, C7, C9, C11, C12, C15, C17, C18, C19, C21, C22, C23, C25, C27, C30, C31: 100n; 0603
C6, C8, C10, C13, C14, C16, C20, C24: 1u; 0603
C26: 10n; 0603
C28: 10u; 0603
C32, C33: 22p; 0603
D1, D2, D3, D4, D5, D6, D7, D8: BAT54S; SOT23
D9: PESD1CAN; SOT23
IC1: LMV614; TSSOP14
IC2: MCP3X083008; SO16
IC3: MCP23017SS; SSOP28
IC4: LM358D; SO08
IC5: IL300; DIL8-SMD
IC6, IC8: TSV912D; SO08
IC7: IL300-DEFG-X007T; DIL8-SMD
IC9: DS1374; UMAX10
IC10: MAX9924; UMAX10
IC11: ZXTR2105FQ; SOT23
IC12: SN65HVD230D; SO08
IC13: MCP2515; SO18W
J1: CONN_20X2; 2X20
J2: CONN_04X2; MOLEX-1053102108
J3: CONN_04RIGHT-ANGLE; MOLEX-1053141204
J5: PWM_OUT; 1X03_JST-XHP
J6: VOLVO_CONN_31; VOLVO_CON_31
J7: VOLVO_CONN_32; VOLVO_CON_32
J8: CONN_02JST-XHP; 1X02_JST-XHP
J9: CONN_03X2; MOLEX-1053101106
J11: VOLVO_CONN_VSS
J13, J14: CONN_01PTH_2MM; 1X01_2MM
J16: TACH_IN; 1X03_JST-XHP
J17, J20, J21, J22: CONN_02PTH4; 1X02_XTRA_BIG
JP1: IN1_SEL; SMT-JUMPER_3_NO_SILK
JP2: IN2_SEL; SMT-JUMPER_3_NO_SILK
JP3: IN3_SEL; SMT-JUMPER_3_NO_SILK
JP4: IN4_SEL; SMT-JUMPER_3_NO_SILK
JP5: IN5_SEL; SMT-JUMPER_3_NO_SILK
JP6: IN6_SEL; SMT-JUMPER_3_NO_SILK
JP7: IN7_SEL; SMT-JUMPER_3_NO_SILK
JP8: IN8_SEL; SMT-JUMPER_3_NO_SILK
JP9: IN9_SEL; SMT-JUMPER_3_NO_SILK
JP10: IN10_SEL; SMT-JUMPER_3_NO_SILK
JP11: IN11_SEL; SMT-JUMPER_3_NO_SILK
JP12: IN12_SEL; SMT-JUMPER_3_NO_SILK
JP13, JP14, JP17, JP18: JUMPER-SMT_3_NO_SILK; SMT-JUMPER_3_NO_SILK
JP15: VSS- Jumper; SMT-JUMPER_2_NO_SILK
JP16, JP21, JP22: SPI_CS_SEL; SMT-JUMPER_3_NO_SILK
OK1, OK2, OK3: ILQ1X009; SMD16
Q1, Q2: 310mA/60V/1.6Ω; SOT323
R1, R4, R6, R8, R57, R58, R65, R69: 100R; 0603
R2: 8.2k; YC248
R3: 15k; YC248
R5, R7: 10k 1%; 0603
R9, R10, R11, R12, R13, R14, R15, R19, R22, R27, R28, R31, R34, R39, R40, R43, R46, R51, R52, R63, R64, R66, R67, R68, R70, R75, R80: 1k; 0603
R16, R54, R60, R76, R81: 20k; 0603
R17, R18, R20, R21, R23, R24, R25, R26, R29, R30, R32, R33, R35, R36, R37, R38, R41, R42, R44, R45, R47, R48, R49, R50: 470R; 0603
R53, R59, R71, R72, R73, R74: 100k 1%; 0603
R55, R61: 270 1%; 0603
R56, R62: 20k 1%; 0603
R77: 120 1%; 0603
R82: RES_D+; 0617/17
S1: RST_SW; TACTILE_SWITCH_SMD_6.0X3.5MM
X1: 12MHz; ECS
Y1: ECX-.327-6-34RR; ECX-34RR

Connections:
3.3V: C7.1, C8.1, C9.1, C10.1, C11.1, C14.1, C19.1, C20.1, C30.1, C31.1, IC2.15 (VREF), IC2.16 (VDD), IC3.9 (VDD), IC3.18 (!RESET), IC6.8 (V+), IC9.10 (VCC), IC12.3 (VCC), IC13.18 (VDD), J1.1, J1.17, J9.3, J16.1, R16.2, R19.2, R22.2, R27.2, R28.2, R31.2, R34.2, R39.2, R40.2, R43.2, R46.2, R51.2, R52.2, R54.2, R60.2, R64.1, R66.1, R68.1, R70.1, R75.2, R76.2, R81.2
5V: C5.1, C6.1, C15.1, C16.1, D1.2 (C2), D2.2 (C2), D3.2 (C2), D4.2 (C2), D5.2 (C2), D6.2 (C2), IC1.4 (V+), IC8.8 (V+), J1.2, J1.4, J2.7, J5.3, R9.2, R10.2, R11.2, R12.2, R63.2, R67.2
12V: C12.1, C13.1, C24.1, D7.2 (C2), D8.2 (C2), IC4.8 (V+), IC5.3 (C3), IC7.3 (C3), IC11.3 (VIN), J3.1, J3.2, J11.+ (V+), R15.2, R17.2, R20.2, R23.2, R25.2, R29.2, R32.2, R35.2, R37.2, R41.2, R44.2, R47.2, R49.2, R82.2
12V-FUSE_8: J6.9, J22.1, J22.2, JP18.3
12V-FUSE_16: J7.A, J17.1, J17.2
!CAN_SPI_CS: IC13.16 (CS), JP16.2
!SPI_CS: IC2.10 (!CS/SHDN), JP22.2
AC_RELAY/VSS_TO_ECU: IC10.7 (COUT), J6.6, Q1.1 (G), R15.1
ADC1_IN: C1.1, IC2.1 (CH0), R2.16 (2), R3.16 (2)
ADC2_IN: C2.1, IC2.2 (CH1), R2.15 (2), R3.15 (2)
ADC3_IN: C3.1, IC2.3 (CH2), R2.14 (2), R3.14 (2)
ADC4_IN: C4.1, IC2.4 (CH3), R2.13 (2), R3.13 (2)
ADC5_IN: C17.1, IC2.5 (CH4), R2.12 (2), R3.12 (2)
ADC6_IN: C18.1, IC2.6 (CH5), R2.11 (2), R3.11 (2)
BLINKER_LEFT_P: J6.8, JP7.2
BLINKER_RIGHT_P: J6.7, JP8.2
BRAKE_FAILURE_N: J6.1, JP4.2
BULB_FAILURE_N: J6.12, JP5.2
CANH: D9.1, IC12.7 (CANH), J8.1, R77.2
CANL: D9.2, IC12.6 (CANL), J8.2, R77.1
CHARGING_N: J6.11, JP6.2, R82.1
CHECK_ENGINE_N: J14.1, JP10.2
CONN_32_PIN3: J7.3, JP12.2
COOLANT_TEMP_SENSOR: J6.2, JP13.3
DIMMER_VOUT: J6.10, JP17.3
FUEL_LVL_SENDER: J7.1, JP14.3
GND: BT1.GND (-), C1.2, C2.2, C3.2, C4.2, C5.2, C6.2, C7.2, C8.2, C9.2, C10.2, C11.2, C14.2, C15.2, C16.2, C17.2, C18.2, C19.2, C20.2, C30.2, C31.2, C32.1, C33.2, D1.1 (A1), D2.1 (A1), D3.1 (A1), D4.1 (A1), D5.1 (A1), D6.1 (A1), D9.3, IC1.11 (V-), IC2.9 (DGND), IC2.14 (AGND), IC3.10 (VSS), IC3.15 (A0), IC3.16 (A1), IC3.17 (A2), IC5.5 (A5), IC6.3 (+IN), IC6.4 (V-), IC6.5 (+IN), IC7.5 (A5), IC8.4 (V-), IC9.5 (GND), IC12.2 (GND), IC13.9 (VSS), J1.6, J1.9, J1.14, J1.20, J1.25, J1.30, J1.39, J2.8, J5.1, J9.6, J16.3, OK1.9 (EMIT), OK1.12 (EMIT), OK1.13 (EMIT), OK1.16 (EMIT), OK2.9 (EMIT), OK2.12 (EMIT), OK2.13 (EMIT), OK2.16 (EMIT), OK3.9 (EMIT), OK3.12 (EMIT), OK3.13 (EMIT), OK3.16 (EMIT), Q1.2 (S), Q2.2 (S), R3.1, R3.2 (1), R3.3 (1), R3.4 (1), R3.5 (1), R3.6 (1), R80.2, S1.1
GND-ISO: C12.2, C13.2, C23.2, C24.2, C25.2, C27.2, C28.1, D7.1 (A1), D8.1 (A1), IC4.4 (V-), IC5.1 (C1), IC7.1 (C1), IC10.5 (GND), IC11.1 (GND), J3.3, J3.4, J7.4, J20.1, J20.2, J21.1, J21.2, JP15.2, JP21.1, R14.2, R18.1, R21.1, R24.1, R26.1, R30.1, R33.1, R36.1, R38.1, R42.1, R45.1, R48.1, R50.1, R53.1, R59.1, R72.1, R74.1
GPIO6: J1.31, J16.2, R76.1
GPIO13: J1.33
GPIO17: J1.11
GPIO18: J1.12, J5.2, R60.1
GPIO19: J1.35, Q2.3 (D), R54.1
GPIO22: J1.15
GPIO25: IC13.12 (INT), J1.22
GPIO26: J1.37
GPIO27: J1.13
HIGH_BEAM_P: J6.3, JP3.2
IN1N: JP1.3, OK1.2 (C), R18.2
IN1P: JP1.1, OK1.1 (A), R17.1
IN1_12V_SIGNAL: R57.1, R73.2, R74.2
IN2N: JP2.3, OK1.3 (C), R21.2
IN2P: JP2.1, OK1.4 (A), R20.1
IN3N: JP3.3, OK1.6 (C), R24.2
IN3P: JP3.1, OK1.5 (A), R23.1
IN4N: JP4.3, OK1.7 (C), R26.2
IN4P: JP4.1, OK1.8 (A), R25.1
IN5N: JP5.3, OK2.2 (C), R30.2
IN5P: JP5.1, OK2.1 (A), R29.1
IN6N: JP6.3, OK2.3 (C), R33.2
IN6P: JP6.1, OK2.4 (A), R32.1
IN7N: JP7.3, OK2.6 (C), R36.2
IN7P: JP7.1, OK2.5 (A), R35.1
IN8N: JP8.3, OK2.7 (C), R38.2
IN8P: JP8.1, OK2.8 (A), R37.1
IN9N: JP9.3, OK3.2 (C), R42.2
IN9P: JP9.1, OK3.1 (A), R41.1
IN10N: JP10.3, OK3.3 (C), R45.2
IN10P: JP10.1, OK3.4 (A), R44.1
IN11N: JP11.3, OK3.6 (C), R48.2
IN11P: JP11.1, OK3.5 (A), R47.1
IN12N: JP12.3, OK3.7 (C), R50.2
IN12P: JP12.1, OK3.8 (A), R49.1
unnamed: IC1.1 (OUT), IC1.2 (-IN), R2.1
unnamed: D7.3 (C1A2), IC4.3 (+IN), R57.2
unnamed: D1.3 (C1A2), IC1.3 (+IN), R1.2
unnamed: IC4.2 (-IN), IC5.4 (A4), R53.2
unnamed: IC1.6 (-IN), IC1.7 (OUT), R2.2 (1)
unnamed: D8.3 (C1A2), IC4.5 (+IN), R58.2
unnamed: D2.3 (C1A2), IC1.5 (+IN), R4.2
unnamed: IC4.6 (-IN), IC7.4 (A4), R59.2
unnamed: IC1.8 (OUT), IC1.9 (-IN), R2.3 (1)
unnamed: C21.2, IC5.6 (C6), IC6.2 (-IN), R56.1
unnamed: D3.3 (C1A2), IC1.10 (+IN), R6.2
unnamed: IC12.8 (S), R80.1
unnamed: IC1.13 (-IN), IC1.14 (OUT), R2.4 (1)
unnamed: Q1.3 (D), Q2.1 (G), R16.1
unnamed: D4.3 (C1A2), IC1.12 (+IN), R8.2
unnamed: JP13.2, R1.1, R9.1
unnamed: R58.1, R71.2, R72.2
unnamed: C32.2, IC13.8 (OSC1), X1.1
unnamed: JP18.2, R71.1
unnamed: IC4.1 (OUT), R55.1
unnamed: IC4.7 (OUT), R61.1
unnamed: JP14.2, R4.1, R10.1
unnamed: JP17.2, R73.1
unnamed: IC9.1 (X1), Y1.2
unnamed: IC5.2 (A2), R55.2
unnamed: IC7.2 (A2), R61.2
unnamed: C22.1, IC6.6 (-IN), IC7.6 (C6), R62.1
unnamed: IC8.1 (OUT), IC8.2 (-IN), R2.5 (1)
unnamed: D5.3 (C1A2), IC8.3 (+IN), R65.2
unnamed: C33.1, IC13.7 (OSC2), X1.2
unnamed: IC9.2 (X2), Y1.1
unnamed: IC8.6 (-IN), IC8.7 (OUT), R2.6 (1)
unnamed: D6.3 (C1A2), IC8.5 (+IN), R69.2
unnamed: IC12.4 (RXD), IC13.2 (RXCAN)
unnamed: BT1.PWR@1 (+), IC9.3 (VBKP)
unnamed: IC9.9 (SQW), R75.1
unnamed: IC12.1 (TXD), IC13.1 (TXCAN)
unnamed: IC9.4 (!RST), S1.2
unnamed: IC13.17 (RESET), R81.1
unnamed: C26.1, IC10.1 (IN+), R5.2
unnamed: C26.2, IC10.2 (IN-), R7.2
unnamed: C27.1, C28.2, IC10.4 (BIAS), R13.1, R14.1
unnamed: IC10.6 (ZERO_EN), IC10.9 (INT_THRS), JP21.2
OD_LAMP_AUTO_P: J13.1, JP9.2
OD_LAMP_P: J6.4, JP2.2
OIL_PRESS_SW_N: J6.5, JP1.2
OUT1: IC3.21 (GPA0), OK1.15 (COL), R19.1
OUT2: IC3.22 (GPA1), OK1.14 (COL), R22.1
OUT3: IC3.23 (GPA2), OK1.11 (COL), R27.1
OUT4: IC3.24 (GPA3), OK1.10 (COL), R28.1
OUT5: IC3.28 (GPA7), OK2.15 (COL), R31.1
OUT6: IC3.27 (GPA6), OK2.14 (COL), R34.1
OUT7: IC3.26 (GPA5), OK2.11 (COL), R39.1
OUT8: IC3.25 (GPA4), OK2.10 (COL), R40.1
OUT9: IC3.1 (GPB0), OK3.15 (COL), R43.1
OUT10: IC3.2 (GPB1), OK3.14 (COL), R46.1
OUT11: IC3.3 (GPB2), OK3.11 (COL), R51.1
OUT12: IC3.4 (GPB3), OK3.10 (COL), R52.1
PARKING_BRAKE_N: J7.2, JP11.2
SCL: IC3.12 (SCL), IC9.7 (SCL), J1.5
SDA: IC3.13 (SDA), IC9.6 (SDA), J1.3
SENSOR1_IN: J2.4, JP13.1
SENSOR2_IN: J2.3, JP14.1
SENSOR3_IN: J2.2, R6.1, R11.1
SENSOR4_IN: J2.1, R8.1, R12.1
SENSOR5_IN: J2.5, R63.1, R65.1
SENSOR6_IN: J2.6, R67.1, R69.1
SIG_3V3_IN1: C21.1, IC2.7 (CH6), IC6.1 (OUT), R56.2
SIG_3V3_IN2: C22.2, IC2.8 (CH7), IC6.7 (OUT), R62.2
SIG_12V_IN1: JP17.1
SIG_12V_IN2: JP18.1
SPI_CE0_N: J1.24, JP16.3, JP22.3
SPI_CE1_N: J1.26, JP16.1, JP22.1
SPI_CLK: IC2.13 (CLK), IC13.13 (SCK), J1.23
SPI_MISO: IC2.12 (DOUT), IC13.15 (SO), J1.21
SPI_MOSI: IC2.11 (DIN), IC13.14 (SI), J1.19
USER_IN1: IC3.5 (GPB4), J9.5, R64.2
USER_IN2: IC3.6 (GPB5), J9.2, R66.2
USER_IN3: IC3.7 (GPB6), J9.1, R68.2
USER_IN4: IC3.8 (GPB7), J9.4, R70.2
VCCA: C23.1, C25.1, IC10.10 (VCC), IC11.2 (VOUT), JP21.3, R13.2
VSS+: J11.G (VSS+), R5.1
VSS-: J11.1 (VSS-), JP15.1, R7.1

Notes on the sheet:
Resistive Sensor Inputs
12V Analog Inputs (Isolated)
Sensor/Analog Input ADC
Dash Light Inputs (Isolated)
Connect output from speedo/vss conditioning circuit to here.
RPi Header
Tach Input
RTC
GPIO Expander
Switched 12V
VSS Input Coniditioning
CAN Transceiver

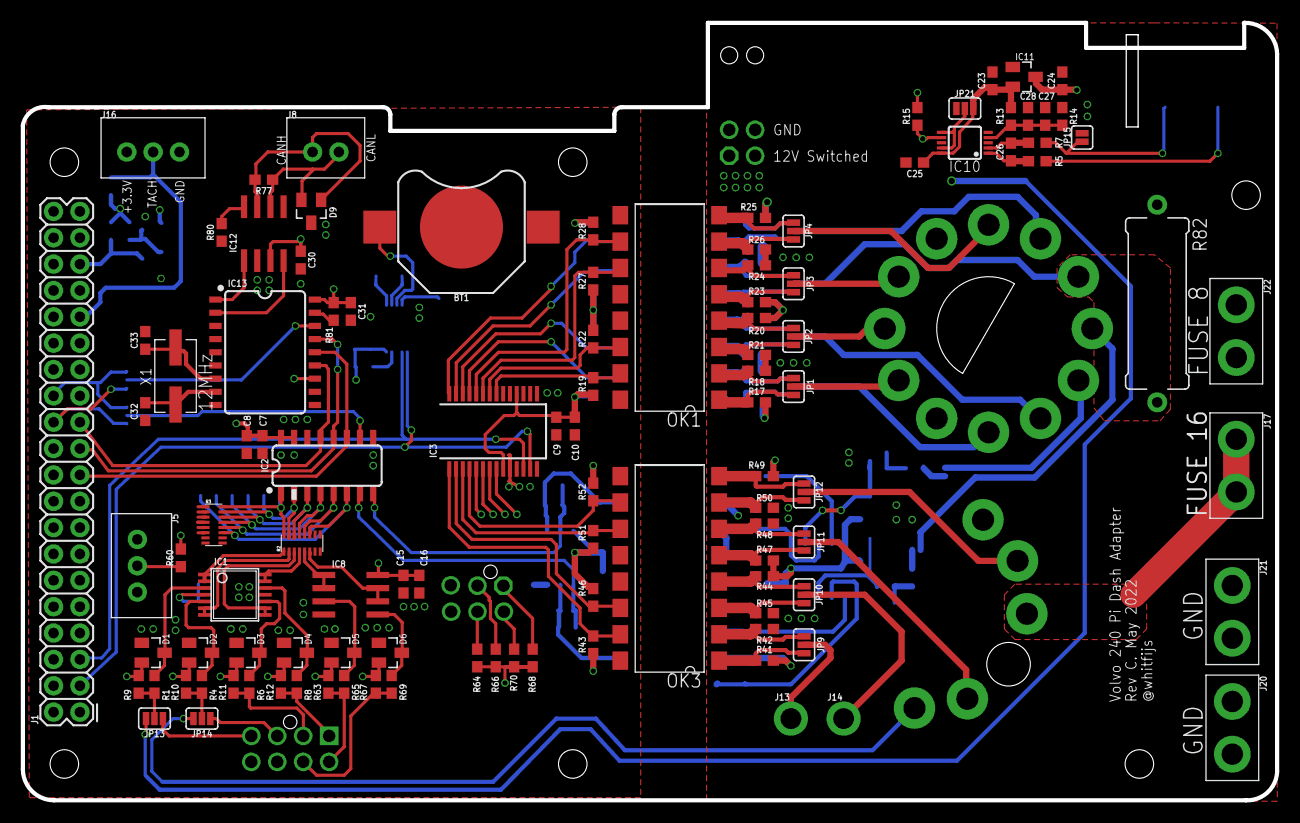
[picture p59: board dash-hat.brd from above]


Board: 4 copper layers, 120.9 x 74.9 mm, 179 parts (65 on the bottom side), 139 nets.

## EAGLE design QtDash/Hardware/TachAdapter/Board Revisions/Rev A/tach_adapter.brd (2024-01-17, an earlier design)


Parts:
D1, D2: 82V; SMB-DIODE
D3: DIODESMA; SMA-DIODE
D4: 13V; SMB-DIODE
IC1: PS2701-1; 4-SMD
J1: M02PTH3; 1X02_LONGPADS
J2: M03LONGPADS; 1X03_LONGPADS
R1: 2k; 1206
R2, R4: 220; 1206
R3: 1k; 1206

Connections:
3.3V: J2.1, R3.1
GND: IC1.3 (EMIT), J2.3
GND-ISO: D4.A, J1.1, R4.1
unnamed: D1.C, D3.C
unnamed: D1.A, D2.C
unnamed: D2.A, R1.1
unnamed: D4.C, R1.2, R2.1
unnamed: IC1.1 (A), R2.2
unnamed: IC1.2 (C), R4.2
unnamed: IC1.4 (COL), J2.2, R3.2
unnamed: D3.A, J1.2

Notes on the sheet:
Rev A Final Assembly Note: Replace D1 with 13V Zener and short across D2 pads


Board: 2 copper layers, 43.5 x 14.6 mm, 11 parts (0 on the bottom side), 11 nets.

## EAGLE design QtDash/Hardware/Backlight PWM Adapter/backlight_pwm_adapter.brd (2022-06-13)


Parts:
C1: 100n; 0603
C2: 1u; 0603
J1, J2: CONN_06; 140-506-417-060
J3: CONN_02; 1X02
JP1: JUMPER-SMT_3_NO_SILK; SMT-JUMPER_3_NO_SILK
Q2: 310mA/60V/1.6Ω; SOT323
R2: 1k; 0603
R3: 100R; 0603
R4: 20k; 0603

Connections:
3.3V: J1.3, J2.4, R4.2
5V: C1.1, C2.1, J1.1, J2.6, R2.2
GND: C1.2, C2.2, J1.6, J2.1, J3.1, Q2.2 (S)
LCD_PWM_IN: J1.4, JP1.3
unnamed: J3.2, R3.2
unnamed: Q2.1 (G), R3.1, R4.1
PI_PWM_OUT: JP1.1, Q2.3 (D), R2.1
PWM_OUT: J2.3, JP1.2


Board: 2 copper layers, 40.4 x 19.5 mm, 10 parts (0 on the bottom side), 8 nets.

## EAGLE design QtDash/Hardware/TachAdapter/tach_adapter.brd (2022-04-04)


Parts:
C1: 10n; 0603
C2: 100n; 0603
D1: 13V; SMB-DIODE
D2, D3: DIODESMA; SMA-DIODE
IC1: H11L1SR2VM; 6-SMD
J1: CONN_02LARGE; 1X02_LARGE
J2: CONN_031X03_LARGE; 1X03_LARGE
R1: 2k; 1206
R2, R4: 220; 1206
R3, R5: 1k; 0603

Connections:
3.3V: C2.1, IC1.6 (VCC), J2.1, R3.1
GND: C1.2, C2.2, IC1.5 (GND), J2.3
GND-ISO: J1.1, R4.1
unnamed: D1.C, D3.C
unnamed: C1.1, D2.C, J2.2, R5.2
unnamed: D1.A, R1.1
unnamed: R1.2, R2.1
unnamed: IC1.1 (A), R2.2
unnamed: IC1.2 (C), R4.2
unnamed: D2.A, IC1.4 (VOUT), R3.2, R5.1
unnamed: D3.A, J1.2


Board: 2 copper layers, 45.4 x 14.6 mm, 13 parts (0 on the bottom side), 11 nets.

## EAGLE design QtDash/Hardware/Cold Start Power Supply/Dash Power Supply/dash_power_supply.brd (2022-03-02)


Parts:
C1, C2, C4, C17: 0.1u; C1210
C3, C16: 4.7u; C1210
C5: 100n; 0603
D1, D3: 24V; SMC
D2: 13V; D0-219AB
D4, D6: 200V; D0-219AB
D5, D10, D11: NSR0170HT1G; SOD-323
D7, D8: 24V; SMA
IC1: LM5060; VSSOP-10
J1, J3: CONN_02PTH4; 1X02_XTRA_BIG
Q1, Q2: IPB042N10N3GATMA1; TO263
Q3: BC816-25HVL; SOT23
R1: 390k; 0603
R2: 2.0k; 0603
R3, R4: 200; 1206
R5, R6, R9: 10k; 0603
R7: 470k; 0603
R8: 15k; 0603

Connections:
5V: D10.A; also elsewhere on the board
G: D5.A, Q1.1 (G), Q2.1 (G), Q3.3 (C), R2.1
GATE: D5.C, IC1.10 (GATE), R2.2
GND: C2.2, C3.2, C4.2, C5.2, C16.2, C17.2, D3.A, D7.A, D8.A, IC1.6 (GND), J1.1, J3.1, R1.2, R8.1; also elsewhere on the board
unnamed: C1.2, C2.1
unnamed: IC1.5 (EN), R5.2
unnamed: D6.A, R3.1, R4.1
unnamed: D8.C, IC1.1 (SENSE), R6.1
unnamed: D4.C, Q3.1 (B), R1.1
unnamed: IC1.3 (OVP), R7.1, R8.2
unnamed: C5.1, IC1.7 (TIMER)
unnamed: IC1.9 (OUT), R9.1
unnamed: D11.C, R5.1
VBATT: C16.1, C17.1, D2.C, D3.C, J3.2, Q1.3 (D), R9.2; also elsewhere on the board
VIN: C1.1, D1.C, J1.2, Q2.3 (D), R3.2, R4.2, R6.2, R7.2
VIN_INTERNAL: D1.A, D2.A, D4.A, Q1.2 (S), Q2.2 (S), Q3.2 (E)
VIN_LM5060: C3.1, C4.1, D6.C, D7.C, D10.C, D11.A, IC1.2 (VIN), IC1.4 (UVLO)

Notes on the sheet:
Input Protection


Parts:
C6: 100n; 0603
C7, C8, C9: 3.3u; PANASONIC_C
C10, C11: 100u; C1210
C12: 4.7u; 0603
C13: .68u; 0603
C14, C15: 1n; 0603
D9: STPS8H100G-TR; TO263
IC2: LM3488; VSSOP-8
J2: CONN_02PTH4; 1X02_XTRA_BIG
L1: DRQ127-4R7-R; DRQ127
Q4: BSC027N04LSG; TDSON
R10: 20R; 0603
R11: 100R; 0603
R12: 30.9k 1%; R1206
R13: 10k 1%; 0603
R14: 75k; 0603
R15: 6mOhm; 3216
R16: 270 1%; 0603
R17: 0; 0603

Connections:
5V: C10.1, C11.1, D9.3 (C), J2.1, R12.2; also elsewhere on the board
GND: C6.2, C7.-, C8.-, C9.-, C10.2, C11.2, C13.2, C14.2, C15.2, IC2.4 (AGND), IC2.5 (PGND), J2.2, L1.2, R13.1, R14.1, R15.1; also elsewhere on the board
unnamed: Q4.4 (G), R17.2
unnamed: C6.1, IC2.8 (VIN), R10.1
unnamed: IC2.3 (FB), R12.1, R13.2
unnamed: IC2.6 (DR), R17.1
unnamed: C15.1, IC2.1 (ISEN), R11.1
unnamed: Q4.1 (S), Q4.2 (S), Q4.3 (S), R11.2, R15.2
unnamed: C12.1, L1.3, Q4.5 (D)
unnamed: C12.2, D9.2 (A), L1.4
unnamed: C14.1, IC2.2 (COMP), R16.2
unnamed: C13.1, R16.1
unnamed: IC2.7 (SYNC), R14.2
VBATT: C7.+, C8.+, C9.+, L1.1, R10.2; also elsewhere on the board

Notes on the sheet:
5V Supply

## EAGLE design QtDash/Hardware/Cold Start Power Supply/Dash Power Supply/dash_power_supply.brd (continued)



Board: 2 copper layers, 50.8 x 86.0 mm, 55 parts (2 on the bottom side), 28 nets.

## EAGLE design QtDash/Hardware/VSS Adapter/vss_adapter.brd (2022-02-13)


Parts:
C1: 1n; 0603
C2, C3, C6: 100n; 0603
C4: 1u; 0603
C5: 10u; 0603
IC1: MAX9924; UMAX10
IC2: ZXTR2105FQ; SOT23
J1: VOLVO_CONN_VSS
J2, J3, J4: CONN_031X03_LARGE; 1X03_LARGE
J5: CONN_02LARGE; 1X02_LARGE
JP1: ZERO_EN; SMT-JUMPER_3_NO_SILK
JP2: VSS-_GND; SMT-JUMPER_2_NO_SILK
Q1: 310mA/60V/1.6Ω; SOT323
R1, R2, R5, R6: 10k 1%; 0603
R3, R4: 1k; 0603

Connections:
5V: C2.1, C3.1, IC1.10 (VCC), IC2.2 (VOUT), JP1.3, R4.1
GND: C2.2, C3.2, C4.2, C5.2, C6.2, IC1.5 (GND), IC2.1 (GND), J3.3, J4.1, J4.2, J4.3, JP1.1, JP2.1, Q1.2 (S), R3.1
IN+: C1.1, IC1.1 (IN+), R1.2
IN-: C1.2, IC1.2 (IN-), R2.2
unnamed: C5.1, C6.1, IC1.4 (BIAS), R3.2, R4.2
unnamed: IC1.6 (ZERO_EN), IC1.9 (INT_THRS), JP1.2
VCC_1: J3.1, R5.2
VCC_2: J5.1, R6.2
VIN: C4.1, IC2.3 (VIN), J1.+ (V+), J2.1, J2.2, J2.3
VSS2_OUT: J5.2, Q1.3 (D), R6.1
VSS+: J1.G (VSS+), R1.1
VSS-: J1.1 (VSS-), JP2.2, R2.1
VSS_OUT: IC1.7 (COUT), J3.2, Q1.1 (G), R5.1



Board: 2 copper layers, 34.3 x 27.9 mm, 22 parts (2 on the bottom side), 13 nets.

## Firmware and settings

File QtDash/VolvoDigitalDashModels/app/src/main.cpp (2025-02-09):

#include <QGuiApplication>
#include <QQmlApplicationEngine>
#include <QQmlContext>
#include <QFont>
#include <QFontDatabase>
#include <QList>
#include <QSurface>
#include <QScreen>
#include <QQmlComponent>
#include <QQuickWindow>
#include <key_press_emitter.h>

#include <config.h>
#include <QMetaType>

#ifdef RASPBERRY_PI
#include <dash.h>
#else
#include <dash_host.h>
#endif

int main(int argc, char *argv[])
{
    QCoreApplication::setAttribute(Qt::AA_EnableHighDpiScaling);
    QGuiApplication app(argc, argv);

    QList<QScreen *> screens = QGuiApplication::screens();
    qDebug("Application sees %d screens", screens.count());
    for (auto screen : screens) {
        qDebug() << "Screen: " << screen;
        qDebug() << screen->physicalSize();
        qDebug() << screen->availableSize();
        qDebug() << screen->availableSize();
    }

    QFontDatabase::addApplicationFont(":/fonts/HandelGothReg.ttf");
    QFont mFont;
    mFont.setFamily("Handel Gothic");
    QGuiApplication::setFont(mFont);

    //Setup QML
    QQmlApplicationEngine engine;
    QQmlContext * ctxt = engine.rootContext();

    KeyPressEmitter * sideScreenKeyPress = new KeyPressEmitter();
    ctxt->setContextProperty("keyPressEmitter", sideScreenKeyPress);

    // Initialize Dash
#ifdef RASPBERRY_PI
    auto dash = std::make_unique<Dash>(&app, ctxt); // new scheme with sensor source -> sensor -> gauge -> model

    ctxt->setContextProperty("RASPBERRY_PI", QVariant(true));

    QObject::connect(
        dash.get(),
        &Dash::keyPress,
        [&engine](QKeyEvent* ev) {
            if (ev != nullptr) {
                qDebug() << "Event:" << ev;
                QCoreApplication::postEvent(
                    engine.rootObjects().first(),
                    ev);
            }
        }
    );

    QObject::connect(sideScreenKeyPress, &KeyPressEmitter::keyPressAndHold, [&dashClass = dash](Qt::Key key) {
       switch (key) {
       case Qt::Key_A:
           dashClass->odoTripReset(0);
           break;
       case Qt::Key_B:
           dashClass->odoTripReset(1);
           break;
       default:
           break;
       }
    });

    dash->init();

    // load main.qml
    engine.load(QUrl(QLatin1String("qrc:/main.qml")));
    if (engine.rootObjects().isEmpty())
        return -1;

    // connect quit
    QObject::connect(&engine, SIGNAL(quit()), &app, SLOT(quit()));

    if (screens.count() > 1) {
        QQuickWindow * accessoryWindow = engine.rootObjects()[0]->findChild<QQuickWindow *>("accessoryScreen");

        QScreen * screen = screens[1];
        screen->setOrientationUpdateMask(Qt::PortraitOrientation);

        accessoryWindow->setScreen(screen);
        accessoryWindow->setProperty("visible", true);
    }
#else
    DashHost * dash = new DashHost(&app, ctxt);
    ctxt->setContextProperty("RASPBERRY_PI", QVariant(false));

    QObject::connect(dash, &DashHost::keyPress, [&engine](QKeyEvent * ev) {
        if (ev != nullptr) {
            qDebug() << ev;
            QCoreApplication::postEvent(engine.rootObjects().first(), ev);
        }
    });

    QObject::connect(sideScreenKeyPress, &KeyPressEmitter::keyPressAndHold, [dash](Qt::Key key) {
       switch (key) {
       case Qt::Key_A:
           dash->odoTripReset(0);
           break;
       case Qt::Key_B:
           dash->odoTripReset(1);
           break;
       default:
           break;
       }
    });

    dash->init();

    // load main.qml
    engine.load(QUrl(QLatin1String("qrc:/main.qml")));
    if (engine.rootObjects().isEmpty())
        return -1;

    // connect quit
    QObject::connect(&engine, SIGNAL(quit()), &app, SLOT(quit()));

    QQuickWindow * accessoryWindow = engine.rootObjects()[0]->findChild<QQuickWindow *>("accessoryScreen");
    accessoryWindow->setWidth(480);
    accessoryWindow->setHeight(800);
    accessoryWindow->setProperty("visible", true);
#endif
    // Start Dash
    dash->start();

    return QGuiApplication::exec();
}

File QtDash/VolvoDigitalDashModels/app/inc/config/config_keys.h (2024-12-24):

#ifndef CONFIG_KEYS_H
#define CONFIG_KEYS_H

namespace ConfigKeys {
    // expected groups
    static constexpr char SENSOR_CHANNEL_GROUP[] = "sensor_channels";
    static constexpr char DASH_LIGHT_GROUP[] = "dash_lights";
    static constexpr char MAP_SENSOR_GROUP[] = "map_sensor";
    static constexpr char TEMP_SENSOR_GROUP[] = "temp_sensor";
    static constexpr char TACH_INPUT_GROUP[] = "tach_input";
    static constexpr char RESISTIVE_SENSOR_GROUP[] = "resistive_sensor";
    static constexpr char ANALOG_INPUT_12V_GROUP[] = "12v_analog";
    static constexpr char VSS_INPUT_GROUP[] = "vss_input";
    static constexpr char ODOMETER_GROUP[] = "odometer";
    static constexpr char BACKLIGHT_GROUP[] = "backlight";
    static constexpr char USER_INPUT_GROUP[] = "user_inputs";

    // expected sensor keys
    static constexpr char COOLANT_TEMP_KEY[] = "coolant_temp";
    static constexpr char FUEL_LEVEL_KEY[] = "fuel_level";
    static constexpr char OIL_PRESSURE_KEY[] = "oil_pressure";
    static constexpr char OIL_TEMP_KEY[] = "oil_temp";
    static constexpr char MAP_SENSOR_KEY[] = "map_sensor";
    static constexpr char AMBIENT_TEMP_KEY[] =  "ambient_temp";
    static constexpr char DIMMER_VOLTAGE_KEY[] =  "dimmer_voltage";
    static constexpr char FUSE8_12V_KEY[] = "fuse8_12v";
    static constexpr char REFERENCE_MEASUREMENT[] = "reference";
    static constexpr char V_SUPPLY_KEY[] = "v_supply";
    static constexpr qreal DEFAULT_V_SUPPLY = 5.0;

    // expected dash light keys
    static constexpr char ACTIVE_LOW[] = "active_low";
    static constexpr char OIL_PRESSURE_SW_KEY[] = "oil_pressure_sw";
    static constexpr char OD_LAMP_KEY[] = "od_lamp";
    static constexpr char HIGH_BEAM_KEY[] = "high_beam";
    static constexpr char BRAKE_FAILURE_KEY[] = "brake_failure";
    static constexpr char BULB_FAILURE_KEY[] = "bulb_failure";
    static constexpr char CHARGING_LIGHT_KEY[] = "charging";
    static constexpr char BLINKER_LEFT_KEY[] = "blinker_left";
    static constexpr char BLINKER_RIGHT_KEY[] = "blinker_right";
    static constexpr char OD_LAMP_AUTO[] = "od_lamp_auto";
    static constexpr char CHECK_ENGINE_KEY[] = "check_engine";
    static constexpr char PARKING_BRAKE_KEY[] = "parking_brake";
    static constexpr char CONN_32_PIN3[] = "conn_32_pin3";

    // expected user input keys
    static constexpr char USER_INPUT1[] = "input_1";
    static constexpr char USER_INPUT2[] = "input_2";
    static constexpr char USER_INPUT3[] = "input_3";
    static constexpr char USER_INPUT4[] = "input_4";
    static constexpr char USER_INPUT1_MAP[] = "input_1_map";
    static constexpr char USER_INPUT2_MAP[] = "input_2_map";
    static constexpr char USER_INPUT3_MAP[] = "input_3_map";
    static constexpr char USER_INPUT4_MAP[] = "input_4_map";
    static constexpr Qt::Key USER_INPUT_DEFAULT_KEY = Qt::Key::Key_A;
    static constexpr char USER_INPUT_LONG_PRESS_DURATION[] = "long_press_msec";
    static constexpr int DEFAULT_LONG_PRESS_DURATION_MSEC = 3000;

    //expected map sensor keys
    static constexpr char PRESSURE_AT_0V[] = "p_0v";
    static constexpr char PRESSURE_AT_5V[] = "p_5v";
    static constexpr char PRESSURE_ATM[] = "p_atm";
    static constexpr char PRESSURE_UNITS[] = "units";

    //expected temperature sensor keys
    static constexpr char TEMP_TYPE[] = "type";
    static constexpr char TEMP_R_BALANCE[] = "r_balance";
    static constexpr char T1_TEMP[] = "t1_temp";
    static constexpr char T1_RES[] = "t1_R";
    static constexpr char T2_TEMP[] = "t2_temp";
    static constexpr char T2_RES[] = "t2_R";
    static constexpr char T3_TEMP[] = "t3_temp";
    static constexpr char T3_RES[] = "t3_R";
    static constexpr char TEMP_UNITS[] = "units";

    static constexpr char TEMP_TYPE_COOLANT[] = "coolant";
    static constexpr char TEMP_TYPE_OIL[] = "oil";
    static constexpr char TEMP_TYPE_AMBIENT[] = "ambient";

    //expected keys for tach input
    static constexpr char TACH_PULSES_PER_ROTATION[] = "pulse_per_rot";
    static constexpr char TACH_MAX_RPM[] = "max_rpm";
    static constexpr char TACH_AVG_NUM_SAMPLES[] = "avg_num_samples";

    //expected keys for vss input
    static constexpr char VSS_PULSES_PER_ROTATION[] = "pulse_per_rot";
    static constexpr char VSS_TIRE_DIAMETER[] = "tire_diameter";
    static constexpr char VSS_TIRE_DIAMETER_UNITS[] = "diameter_units";
    static constexpr char VSS_PULSES_PER_DISTANCE[] = "pulse_per_unit_distance";
    static constexpr char VSS_DISTANCE_UNITS[] = "distance_units";
    static constexpr char VSS_MAX_SPEED[] = "max_speed";
    static constexpr char VSS_USE_GPS[] = "use_gps";
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

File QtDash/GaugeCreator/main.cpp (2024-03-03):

#include <QGuiApplication>
#include <QQmlApplicationEngine>
#include <QFontDatabase>


int main(int argc, char *argv[])
{
#if QT_VERSION < QT_VERSION_CHECK(6, 0, 0)
    QCoreApplication::setAttribute(Qt::AA_EnableHighDpiScaling);
#endif
    QGuiApplication app(argc, argv);

    QFontDatabase::addApplicationFont(":/fonts/HandelGothReg.ttf");
    QFont mFont;
    mFont.setFamily("Handel Gothic");
    app.setFont(mFont);

    QQmlApplicationEngine engine;
    const QUrl url(QStringLiteral("qrc:/main.qml"));
    QObject::connect(&engine, &QQmlApplicationEngine::objectCreated,
                     &app, [url](QObject *obj, const QUrl &objUrl) {
        if (!obj && url == objUrl)
            QCoreApplication::exit(-1);
    }, Qt::QueuedConnection);
    engine.load(url);

    return app.exec();
}

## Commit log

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2021-05-21 - added warning light model - added parking brake and brake failure lights to original dash layout - TODO: add other warning lights to a layout that can be placed at the bottom of all screens
    [main.cpp]
2021-05-21 - added bulb failure light
    [main.cpp]
2021-05-22 - added icons for battery, oil, high beam and bulb failure wanring lights
    [main.cpp]
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2021-12-14 digital-dash-project: - added start of circular connector 31 - added pos/neg isolated inputs and hooked up gpio expander - todo: get measurements on connector 32 and connector 31 to be able to finish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
    [con_31.dxf, dash-hat.brd, dash-hat.sch]
2021-12-15 - added pinouts and dxf of connector 31 and 32 pin layouts
    [Dash-Connector-31.dxf, Dash-Connector-32.dxf]
2021-12-15 - updated tach adapter with opto-coupler that is currently available - added datasheets for tach-adapter components - updated dashhat library with new connector 31 dimensions - moved circuit simulati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
    [tach_adapter.brd, tach_adapter.sch]
2021-12-15 - added IL300 to library -- need to have isolated 0-12V input to 0-3.3V output - added start of non-isolated 0-12V input -- need to change to use IL300 ($$$) x2 at least.
    [dash-hat.brd, dash-hat.sch]
2021-12-16 - finished connector 31 symbol and footprint -- still need to verify pin diameter from old dash - started moving components around in layout - added IL300 and LM158 datasheets and applicable app note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
    [dash-hat.brd, dash-hat.sch]
2021-12-20 - added volvo connector 32 to library and schematic -- still need to figure out where to grab 12V from
    [dash-hat.brd, dash-hat.sch]
2021-12-24 - started layout of 12v isolated section -- will definitely have to change. - TODO: figure out board form factor.
    [dash-hat.brd, dash-hat.sch]
2021-12-27 - added MCP23017 user space driver in QtDash project using linux i2c-dev -- tested using mcp23017 i2c breakout board hooked up to i2c1 on pi - Hooked up indicator lights and blinkers in qt program - 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
    [dash-hat.brd, dash-hat.sch]
2021-12-28 - added 2 more 5V sensor in channels (MAP and ambient temp) - started laying out sensor/ADC within limits of piHAT pcb section
    [dash-hat.brd, dash-hat.sch]
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2021-12-28 - finished tach adapter board -- ordered components and board from OSHPark
    [tach_adapter.brd, tach_adapter.sch]
2021-12-29 - finished first draft of dash hat board -- ended up 4 layers to keep things tight, became very expensive - TODO: verify all pin connections - look into max9924 for VSS signal conditioning -- would r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
    [dash-hat.brd, dash-hat.sch]
2021-12-29 - added mcp3208 dts/dtb - added tach input to board - changed 12V analog inputs to be 1/2 to be able to handle >12V during operation - added mcp3208 to config
    [dash-hat.brd, dash-hat.sch]
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2021-12-29 - added missing init.d file for module loading - added linux and defconfig changes made over the last few days -- currently working with MCP3208 and MCP32017
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2021-12-30 - Ground return path check -- added a few more vias in GND and GND-ISO
    [dash-hat.brd]
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2021-12-31 - replaced remaining single BAT54s with BAT54s -- save some space and ground plane
    [dash-hat.brd, dash-hat.sch]
2021-12-31 - QGeoPositionInfoSource didn't like the pi -- changed to explicit QNmeaPositionInfoSource with manual opening of the serial port -- probably have to close it now as well. - included qtserialport lib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
    [main.cpp]
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2022-01-01 - added pdfs for rtc and battery holder - added DS1374 RTC to board, I forsee bodge wires in the future - TODO: look into configuration file/management for sensor and dash light inputs
    [dash-hat.brd, dash-hat.sch]
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2022-01-02 - implemented config for rpi builds - fixed some oddities in the way the need center is being drawn for the gauges - tried to make the ambient temperature gauge work. Doesn't seem to be equally space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
    [config.ini, main.cpp]
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2022-01-03 feature/740-gauges: - finished svg recreation of stock 740 gauges - added 4th screen with stock 740 layout - TODO: speedo doesn't really line up that well -- it might need a separate model or the mod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
    [main.cpp]
2022-01-04 - started Eagle library clean up and proper part value assignment - added RC0603-* resistors to library with proper values and part numbers
    [dash-hat.brd, dash-hat.csv, dash-hat.sch]
2022-01-04 - finished adding yageo resistors to schematic -- should all of the right part numbers now - TODO: caps
    [dash-hat.brd, dash-hat.csv, dash-hat.sch]
2022-01-05 topic/740-gauges: - downsized 740 gauge images for faster loading - converted 740 gauge delegates to loaders - adjusted 740 speedo start and end angle. Still doesn't line up quite right
    [main.cpp]
2022-01-05 - added real part numbers for capacitors - made new BOM/parts list
    [dash-hat-BOM.csv, dash-hat-parts.csv, dash-hat.brd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]
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2022-01-06 feature/740-gauges: - fixed config.h issue for 0V pressure key string - config for map sensor is now a 3bar map sensor
    [config.ini]
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2022-01-07 - added load resistor to alternator D+ connection -- not sure what kind of current is needed for this -- 15 Ohm 5W EP5WS15RJ 17.5mm axial resistor spec'd for now
    [dash-hat.brd, dash-hat.sch]
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2022-01-09 - added sftp and networking to linux image -- should be able to ssh over ehternet now - made some final edits to the board and sent off to OSHPark - created a real rootfs overlay in boards/volvodash 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
    [dash-hat.brd]
2022-01-10 - updated post-build.sh script to remove all absolute paths so it doesn't suck to build everything - buildroot make will now build and package the Qt dash app in to the generated image -- no need to 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
    [config.ini]
2022-01-11 feature/tach_input_module: - pulse spacing and pulse count now working in the pulse_counter kernel module - timing using jiffies is not going to be sufficient as it seems to be msec timing - need to 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
2022-01-11 feature/tach_input_module: - first go at reading tach input from sysfs class creating from pulse_counter kernel module - everything seems to work -- definitely need error checking as we could divide 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
    [main.cpp]
2022-01-11 feature/tach_input_module: - added pulse timeout timer -- set to 200 msec now -- if no pulse comes in within 200msec the pulse spacing avg is reset - added pulse_counter to modules list
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2022-01-17 topic/sensor-utilities: - fixed some issues with polynomial regression - need to create actual values for ini
    [config.ini, dash_host.h]
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2022-01-17 topic/sensors-utilities: - added 12V analog input voltage calculations (IL300 gains vary a lot -- each one will have to be characterized) - added 3.3V voltage divider correction factor (not currently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
    [config.ini]
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2022-01-19 topic/sensor-gauge-complete-overhaul: - added 240 temp/fuel back in - fixed signaling issue in signal source - added tach gauge back in - added "very fast" event timer -- 20Hz - added some sensor dat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
2022-01-23 bugfix/hardware-revA-issues: - pin 12 on full round connector had 2mm drill instead of 2.1336mm drill. makes for a press fit vs slip fit - TODO: top side of board interacts with ethernet port -- lose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
2022-01-24 bugfix/hardware-revA-issues: - updated library to include TSV912 and LMV614 (RRIO -- what should have been in there to begin with) - made room for ethernet port - added ground planes where available 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
    [dash-hat.brd, dash-hat.sch]
2022-01-25 bugfix/hardware-revA-issues: - moved alternator D+ supply to fuse 16 12V supply - added datasheet for new LED backlit screen - added mount stls
    [Mount-HSD123KPW2-left.stl, Mount-HSD123KPW2-right.stl, dash-hat.brd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]
2022-01-25 bugfix/hardware-revA-issues: - added 0.5mm clearance to screen through holes
    [Mount-HSD123KPW2-left.stl, Mount-HSD123KPW2-right.stl]
2022-01-25 bugfix/hardware-revA-issues: - slotted outer dash mounting holes - added more clearance for module cover
2022-01-25 bugfix/hardware-revA-issues: - adjusted mounts to be inset about a mm - added mounts to align the screen upside down
    [Mount-HSD123KPW2-upsidedown-left.stl, Mount-HSD123KPW2-upsidedown-right.stl, dash-hat.brd]
2022-01-26 bugfix/hardware-revA-issues: - first draft of mount
    [Electronics Mount-left.stl, Electronics Mount-right.stl, Electronics Mount.stl]
2022-01-26 bugfix/hardware-revA-issues: - added addition of ds1374 to i2c new_device, not sure why its not loading automatically - changed mcp23017 address to 0x20 to reflect revA hardware
2022-01-27 bugfix/hardware-revA-issues: - added active low configuration
    [config.ini, dash_lights.h]
2022-01-27 bugfix/hardware-revA-issues: - changed address in mcp23017 qt driver - changed active_low config from true to 1
    [config.ini]
2022-01-27 bugfix/hardware-revA-issues: - added outputs solder points for fuse 16 and fuse 8 power - added 12V input solder points switched power? - added some ground vias on for 5V ground return path -- things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
    [dash-hat.brd, dash-hat.sch]
2022-01-28 bugfix/hardware-revA-issues: - added squashfs rootfs to sd card image -- should be able to switch between ext4 and squash using cmdline.txt
2022-01-30 bugfix/hardware-revA-issues: - changes to config.ini to reflect current hardware -- guessed on temp sender. fuel sensor seems to be right (ish). - fuse 16 on the half moon connector is NOT populated 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
    [config.ini]
2022-01-31 bugfix/hardware-revA-issues: - moved D+ resistor back to switched 12V supply - added second switched 12V header - D+ resistor moved and 12Vin plane extended
    [dash-hat.brd, dash-hat.sch]
2022-02-01 bugfix/hardware-revA-issues: - output of IL300s were oscillating under load -- added 100n capacitor (bodged on revA) - 12V inputs are only 0-3.3V signals -- K3 used to compensate for different for now
    [dash-hat.brd, dash-hat.sch]
2022-02-02 bugfix/hardware-revA-issues: - added max9924 vss adapter -- dual output one active high, one active low - updated coil simulation to reflect what I'm seeing on the car - fixed adc correction factor
    [vss_adapter.brd, vss_adapter.sch]
2022-02-03 bugfix/hardware-revA-issues: - changed resistance values for coolant temp sensor to early 240 version values
    [config.ini]
2022-02-05 bugfix/hardware-revA-issues: - modified pulse_counter kernel module to handle both VSS and tach pulse inputs - fixed issue with tach signal jumping around -- ignore pulses that are too fast instead o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
    [config.ini]
2022-02-05 bugfix/hardware-revA-issues: - added voltage correction factor to 12v analog signals
2022-02-06 bugfix/hardware-revA-issues - removed superfluous zener diodes from input of tach adapter board - changed input/output wire solder hole sizes - added debouncing circuit that probably won't work on th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
    [tach_adapter.brd, tach_adapter.sch]
2022-02-06 - copied revA version of pi adapter into /QtDash/Hardware/DashHat/Board Revisions/Rev A - generated gerbers and schematic pdf -- will need to modify the schematic to reflect what was actually built -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
    [dash-hat-BOM.csv, dash-hat-parts.csv, dash-hat.brd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]
2022-02-06 - copied rev A of tach adapter into /Hardware/TachAdapter/Board Revisions/ - added gerbers to tach adapter Rev A - todo: Correct schematic to reflect what was actually built and working
    [tach_adapter.brd, tach_adapter.sch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]
2022-02-06 - added assembly variant of Rev A tach adapter board -- with notes on final assembly - updated pdf of Rev A schematic with Rev A final assembly variant
    [tach_adapter.brd, tach_adapter.sch]
2022-02-06 - update Board Revisions/Rev A schematic with final assembly values notes on final assembly
    [dash-hat.brd, dash-hat.sch]
2022-02-10 bugfix/hardware-revA-issues: - started on cold-start tolerant 5V power supply
    [dash_power_supply.brd, dash_power_supply.sch]
2022-02-10 bugfix/hardware-revA-issues: - added lm3488 5V SEPIC DC/DC converter -- components selected and first draft of layout - TODO: select components for input protection and layout the input proectection 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
    [2022-02-10T151251.xlsx, dash_power_supply.brd, dash_power_supply.sch]
2022-02-11 bugfix/hardware-revA-issues: - first draft of cold start power supply board layout -- passed DRC
    [dash_power_supply.brd, dash_power_supply.sch]
2022-02-12 bugfix/hardware-revA-issues: - added supply only board for testing separately and more cheaply - added resistor values to cold start board library
    [dash_power_supply.brd, dash_power_supply.sch]
2022-02-13 bugfix/hardware-revA-issues: - added jumper from VSS- to ground just in case and up-reved VSS input board -
    [vss_adapter.brd, vss_adapter.sch]
2022-02-15 topix/component-optimization: - fixed issue with gauge needle movement - changed sensor 5V to 3.3V resistor divider to use resistory arrays
    [dash-hat.brd, dash-hat.sch]
2022-02-16 topic/switch-to-64-bit: - buildroot adjusted to work without rpi-userland packages - vc4 and v3d compiled into kernel - qml manually rotated 180 degrees - additional QT_QPA parameters added to init.d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
2022-02-17 topic/new-gauge-designs: - added flipped boot screen - updated image rendering and qt quick versions
    [main.cpp]
2022-02-17 bugfix/tach-adapter-updates: - updated eagle tach adapter project
    [tach_adapter.brd, tach_adapter.sch]
2022-02-17 bugfix/tach-adapter-updates: - added kicad project for tach adapter -- testing out kicad
    [TachAdapter-B_Cu.gbl, TachAdapter-B_Mask.gbs, TachAdapter-B_Paste.gbp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]
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2022-02-18 bugfix/tach-adapter-updates: - added footprint cache
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2022-02-19 topic/new-gauge-designs: - reverted 240 needle output to radiused rectangle
    [dash_host.h, main.cpp]
2022-02-19 topic/sensor-and-gauge-value-conditioning: - re-arranged dash initialization to avoid flippy text during boot
    [main.cpp]
2022-02-19 topic/component-optimization: - re-organized schematic - fixed some layout issues and component labels on the board
    [dash-hat.brd, dash-hat.sch]
2022-02-20 topic/sensor-and-gauge-value-conditioning: - added check for disconnected/shorted sensor for both NTC and generic resistive sensors - added v_supply config value to resistive sensor configs
    [config.ini]
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2022-02-25 topic/component_optimization: - fixed issue with vss source signal/slot hookup - vss input now working -- tested with function generator
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2022-03-01 topic/component-optimization: - 20k resistor on vin of power supply should have been 20R - fixed silk screen on cold start power supply - re-arranged components a via for cleaner return paths
    [dash_power_supply.brd, dash_power_supply.sch]
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2022-03-04 - filled in missing documentation in a lot of file
    [dash_host.h]
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2022-03-05 - fixed schematic image
2022-03-05 bugfix/gauge-configs-dont-propagate: - gauge display units aren't getting propagated - TODO: define internal units for sensors/sensor sources and the gauge is responsible for conversion to display un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
    [dash_host.h]
2022-03-06 bugfix/gauge-configs-dont-propagate: - ugly solution to convert internal sensor units to display units from config_gauges.ini
    [dash_host.h]
2022-03-07 bugfix/gauge-configs-dont-propagate: - added config option to repurpose one input as a reference measurement -- no sensor attached, just a pullup to the unregulated 5V supply - if reference channel i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
    [config.ini]
2022-03-08 bugfix/gauge-configs-dont-propagate: - changed secondary gauge to have one decimal place and switched it to voltage - added linear fit to analog 12V input -- the output is linear but there is an offs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
    [config.ini]
2022-03-08 bugfix/gauge-configs-dont-propagate: - updated README.md with new 12V input parameters and rough instructions on determining k3 gain/calibrating the voltmeter
2022-03-14 bugfix/analog-12v-input-linearity-issues: - added reference update after every reading -- probably not necessary - changed IL300 circuit values to increase drive current and opamp output voltage to d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
    [dash-hat.brd, dash-hat.sch]
2022-03-14 bugfix/analog-12V-input-linearity-issues: - added simulation for IL300 circuit with updated values to increase drive LED current
2022-03-14 bugfix/analog-12v-input-linearity-issues: - added datasheets for IL300 alternatives - added .lib file for IL300
2022-03-15 bugfix/analog-12v-input-linearity-issues: - small changes in main board schematic to make it easier to read
    [dash-hat.sch]
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2022-04-08 topic/backlight-pwm-control: - added backlight control class - fixed issues in pwm class - pwm control starts when qt dash is started -- startup script likely needed to start backlight at default val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
    [backlight_pwm_adapter.brd, backlight_pwm_adapter.sch]
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2022-04-23 topic/backlight-pwm-control: - mapped dimmer voltage / battery voltage ratio to min/max duty cycle - added minimum and maximum dimmer voltage / battery voltage ratio -- might need to low pass changes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
    [dimmer_voltage_ratio.csv]
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2022-04-23 topic/backlight-pwm-control: - fixed conditional for use dimmer boolean - dimmer sort of working on the car -- jumps around a little bit with varying load.
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2022-04-27 topic/hardware-revc: - removed individual pin headers for sensor inputs -- changed to molex 8 pin for now, might be too large
    [dash-hat.brd, dash-hat.sch]
2022-04-28 topic/hardware-revc: - replaced larger molex connector smaller molex connector
    [dash-hat.brd, dash-hat.sch]
2022-04-28 topic/hardware-revc: - Analog input layout with new connector is done -- need to check on connector footprint as there is a dimension error - TODO: replace switched 12V power and GND with molex conne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
    [dash-hat.brd, dash-hat.sch]
2022-04-29 topic/hardware-revc: - added right angle nano-fit molex connector for switched 12V power - added 4 user inputs on the remaining 4 pins of MCP23017 - added pwm output on pin 18 with 3.3V pullup - adde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
    [dash-hat.brd, dash-hat.sch]
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2022-05-04 topic/hardware-revc: - open drain for PWM adapter made non-inverting -- keeps backlight on during boot - made use of activeLow backlight config - changed backlight initialization values in inittab - 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
    [backlight_pwm_adapter.brd, backlight_pwm_adapter.sch]
2022-05-04 topic/hardware-revc: - replaced dd with fbv in /sbin/preinit - tested pwm.h changes
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2022-05-20 topic/hardware-revc: - added MCP2515 and SN65HVD230 to board - didn't use split termination or common mode choke for CAN -- if there is EMI issues that'll be one (of likely many) place to look
    [dash-hat.brd, dash-hat.sch]
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2022-06-02 topic/hardware-revc: - fixed (hopefully) some string comparision issues in sensor utils and config - updated mcp2515 and transceiver circuit -- todo: check dimensions of cheap amazon JST style plug
    [dash-hat.brd, dash-hat.sch]
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2022-07-08 bugfix/hardware-revc-fixes: - added proper CAN support to rpi4 image -- working with MCP2515 on rev C hardware - fixed missing i2cdev package in rpi4 linux image -- mcp23017 working - MCP3208 moved t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
2022-09-30 bugfix/hardware-revc-fixes: - added object to lambda in gauge_temp_fuel_cluster - fixed unused parameter warning in gps_helper.h - added emit to signal call in sensor_tach.h - added invalid resistanc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
2022-10-03 bugfix/hardware-revc-fixes: - filled in more config unit tests -- temp sensor configs
2022-10-05 bugfix/hardware-revc-fixes: - fixed bug in sensor utils convert() function -- distance conversion now works - fixed non-public constructor in gpio_sensor - added distance/length convert() test case -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
2022-10-05 bugfix/hardware-revc-fixes: - added signal/slot system for passing MCP23017 gpio events up to the qml layer as key events
    [main.cpp]
2022-10-06 bugfix/hardware-revc-fixes: - added key pass to host dash - switched to using arrow keys to cycle through screens - added reset() function to odometer sensor -- only for trip counters - fixed various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
    [dash_host.h, main.cpp]
2022-10-06 bugfix/hardware-revc-fixes: - changed 4-pin user input to 6-pin molex nano-fit connector to accomodate 3.3V and GND
    [dash-hat.brd, dash-hat.sch]
2022-12-13 bugfix/hardware-revc-fixes: - fixed missing explicit override in sensor sources
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2022-12-28 bugfix/hardware-revc-fixes: - added start out touch panel for 4 user inputs - fixed issues with host dash setup - changed changing of screen to key released and ignore duplicate events
    [touch_panel.kicad_pcb, touch_panel.kicad_sch, touch_panel.sch]
2022-12-29 bugfix/hardware-revc-fixes: - first draft of layout for control button board - added symbol + footprint for capacitive touch button 12.5mm square
    [touch_panel.kicad_pcb, touch_panel.kicad_sch]
2022-12-30 bugfix/hardware-revc-fixes: - finalized touch panel rev A - Rev A touch panel board sent to fab - added stl files for small guage slot cover (whole and cutout for touch panel board)
    [Small_Gauge_Cover_Cover_ w_cutout.stl, Small_Gauge_Cover_Whole.stl, touch_panel.kicad_pcb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]
2023-01-03 bugfix/hardware-revc-fixes: - added documentation for rev A touch panel board
    [touch_panel-B_Cu.gbl, touch_panel-B_Mask.gbs, touch_panel-B_Paste.gbp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]
2023-01-16 bugfix/hardware-revc-fixes: - user inputs pins are configurable - user input key mapping is somewhat configurable (Key_Left,Key_Right are needed to changed screens) - updated DashLights to accept gen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
    [config.ini, dash.h, dash_host.h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]
2023-01-17 bugfix/hardware-revc-fixes: - updated README with user input and PWM backlight options
2023-01-17 bugfix/hardware-revc-fixes: - updated stl files for gauge covers
    [Small_Gauge_Cover_Cover_ w_cutout.stl, Small_Gauge_Cover_Whole.stl]
2023-01-18 bugfix/hardware-revc-fixes: - added enable/disable CAN frame handling from CAN config file - updated README with CAN config information - fixed some values in the can_config.ini file
    [config_can.ini]
2023-02-07 bugfix/hardware-revc-fixes: - initial value of resistive sensor previousValue was undefined
2023-02-16 feature/long-press-mapping-for-user-inputs-trip-odometer-resetting: - initial go at long press mapped to resetting trip counters - TODO: make long press mapping configurable
    [dash_lights.h]
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2023-03-15 feature-45: - changed button height on side accessory gauge screen - failed attempt at rotating popup menu
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2023-03-16 feature-45: - accessory screen no longer visible by default
    [main.cpp]
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2023-03-18 feature-45: - added pressAndHold to keyPressEmitter class - added pressAndHold call to middle keys (changed to A and B) to reset trip odometers
    [dash_host.h, main.cpp]
2023-04-24 feature-45: - added startup script S99usbmultitouch to attempt to locate the HID USB multitouch input and set the correct qt environment variables so that the touchscreen gets picked up correctly at 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
    [main.cpp]
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2023-12-04 50-map-sensor-atmospheric-offset-not-configurable: - fixed rpi dash build -- was including removed dash header
    [main.cpp]
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2023-12-05 50-map-sensor-atmospheric-offset-not-configurable: - messy fix to read supply_voltage as an int
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2024-02-27 topic/early-240-gauges: - generated kph early 240 speedo - started fixing diplay unit propagation -- gauges with different min/max yet to be handled
    [dash_host.h]
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2024-03-06 topic/delegate-restructuring: - updated parts list with battery holder that's available - corrected IL300 part number with smd part
    [dash-hat.brd, dash-hat.sch, mouser_parts_list.xls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]
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2024-03-10 55-adc-voltage-calculation-incorrect: - fixed issue with voltmeter calculation after testing in car
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2024-03-12 topic/accessory-gauge-units: - fixed issue with p1800 side screen oil pressure max - added psi oil pressure for p1800 style
2024-03-12 topic/accessory-gauge-units: - fixed integer truncating in gauge min/max values - added default values for given units to simplify config_gauges.ini
    [dash_host.h]
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2024-06-12 topic/config-cleanup: - fixed issue with accessory gauge sensors not being capture by lambda properly
2024-12-22 feature/63: - finally fixed absolute paths in dash host app
    [dash_host.h]
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2024-12-24 bugfix/67: - updated README for alternate gauge units and resistive sensor decaying lag coefficient
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2025-02-04 task/gauge-sensor-cleanup: - lots of lambda capture fixes - sensorDataReady, transform, dataReady all use const QVariant&
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2025-02-07 topic/config-sonarqube-cleanup: - fixed const and raw for loop
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

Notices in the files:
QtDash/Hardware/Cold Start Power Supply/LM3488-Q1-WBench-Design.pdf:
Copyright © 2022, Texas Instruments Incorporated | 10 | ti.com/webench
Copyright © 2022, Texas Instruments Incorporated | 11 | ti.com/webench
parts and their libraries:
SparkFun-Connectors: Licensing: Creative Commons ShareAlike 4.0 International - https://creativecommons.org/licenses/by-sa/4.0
